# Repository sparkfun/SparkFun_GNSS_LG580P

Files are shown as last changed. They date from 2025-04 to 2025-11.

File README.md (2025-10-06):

SparkFun Quadband GNSS RTK with Heading Breakout - LG580P (Qwiic)
========================================

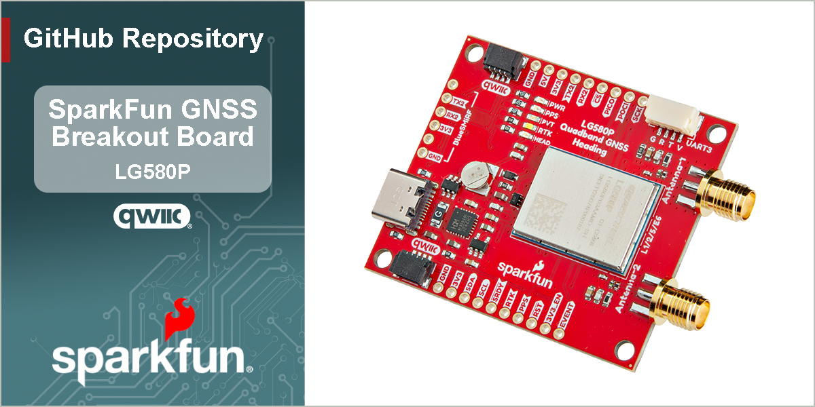
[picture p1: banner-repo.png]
SparkFun Quadband GNSS RTK with Heading Breakout - LG580P (Qwiic)


[*SparkFun Quadband GNSS RTK with Heading Breakout - LG580P (Qwiic) (GPS-28019)*](https://www.sparkfun.com/sparkfun-quadband-gnss-rtk-with-heading-breakout-lg580p-qwiic.html)

The [SparkFun Quadband GNSS RTK with Heading Breakout - LG580P (Qwiic)](https://www.sparkfun.com/sparkfun-quadband-gnss-rtk-with-heading-breakout-lg580p-qwiic.html) features the Quectel LG580P GNSS module, providing exceptional positioning and heading accuracy. The LG580P GNSS module is an upgraded version of the LG290P on our [SparkFun Quadband GNSS RTK Breakout - LG290P (Qwiic)](https://www.sparkfun.com/sparkfun-quadband-gnss-rtk-breakout-lg290p-qwiic.html); providing an additional GNSS antenna input for instantaneous heading determination down to 0.1&deg;. In traditional navigation systems, such as those used on your phone or car, previous navigation points are utilized to determine the course heading. This is the reason why the arrow indicator will spin or be oriented in the wrong directions when the navigation system first boots or has been stationary for extended periods of time. However, with the LG580 GNSS module, users are provided with a dedicated heading without relying on previous course data points, magnetometers/compasses, or gyroscopes in IMUs, which can introduce small errors.

The board's dimensions, pin layout, and connectors are similar to our very popular [SparkFun GPS-RTK-SMA Breakout - ZED-F9P (Qwiic)](https://www.sparkfun.com/sparkfun-gps-rtk-sma-breakout-zed-f9p-qwiic.html), featuring a compact design and convenient Qwiic connectors. *(\*Depending on your application, this board could potentially function as a drop-in replacement; users should verify the pin compatibility of this board with their current installation.)* The board also accommodates users with a diverse choice of interfaces including UART, SPI*, I<sup>2</sup>C*, and CAN*. The board has three UART ports, which are accessible through the USB-C connector, BlueSMiRF *(6-pin PTH)* header, and 4-pin locking JST connector. Users can also interface with the board through the 25 PTH pins that are broken out around the edge of the board. For the GNSS antenna(s), SMA antenna connectors are provided on the edge of the board; an optional, secondary antenna can be utilized for heading determination. We also provide two 4-pin JST Qwiic connectors for future use, when the I<sup>2</sup>C feature becomes available for the GNSS module.

The LG580P module is a quad-band, multi-constellation, high-precision, RTK and heading GNSS receiver. The module is capable of simultaneously receiving signals from the `L1`, `L2`, `L5`, and `L6`/`E6` frequency bands of the GPS, GLONASS, Galileo, BDS, QZSS, and NavIC GNSS constellations. In addition, the module supports SBAS augmentation systems (WAAS, EGNOS, BDSBAS, MSAS, GAGAN, KASS, ASECNA, SouthPAN, and SDCM), PPP services* (BDS PPP-B2b, QZSS CLAS, MADOCA-PPP, and Galileo HAS), RTCM, and RTK corrections for precision navigation with a fast convergence time and reliable performance.

The built-in professional-grade interference signal detection and elimination algorithms, effectively mitigate multiple narrow-band interference sources and significantly improve signal reception performance in complex electromagnetic environments. In addition, the RTK and heading algorithms ensure reliable positioning in challenging scenarios such as urban environments and deep tree cover. With its high-precision, low power consumption and a high positioning and heading update rate of up to 20 Hz, this board is ideal for high-precision navigation applications, such as intelligent robots, precision agriculture, ADAS, and autonomous driving.

> [!NOTE]
> `*`: Feature is still under development

> [!IMPORTANT]
> - Currently, only the UART interface is supported by the module. All three UART ports are broken out to the USB-C connector *(via CH342 USB-serial converter)*, 4-pin locking JST connector, and BlueSMiRF 6-pin header.
> - Additionally, the corrections for some of the PPP services may not be implemented yet.

Documentation
--------------

- **[Hookup Guide (mkdocs)](http://docs.sparkfun.com/SparkFun_GNSS_LG580P/)** - A hookup guide for the SparkFun Quadband GNSS RTK Breakout - LG580P breakout board hosted by GitHub pages<br>
   
- [SparkFun LG290P GNSS Arduino Library](https://github.com/sparkfun/SparkFun_LG290P_GNSS_Arduino_Library) - An Arduino library for the LG290P and LGx80P GNSS modules

Repository Contents
-------------------

- **[/docs](/docs/)** - Online documentation files
  - [/assets](/docs/assets/) - Assets files
    - [/3d_model](/docs/assets/3d_model/) - 3D models for the board
    - [/board_files](/docs/assets/board_files/) - Design files for the board
      - [KiCad Design Files](/docs/assets/board_files/kicad_files.zip) (.zip)
      - [Schematic](/docs/assets/board_files/schematic.pdf) (.pdf)
      - [Dimensions](/docs/assets/board_files/dimensions.pdf) (.pdf)
    - [/component_documentation](/docs/assets/component_documentation/) - Datasheets for hardware components
    - [/img/hookup_guide](/docs/assets/img/hookup_guide/) - Images for hookup guide documentation - Hookup guide images for the board
    - /Hardware - Hardware design files (.brd, .sch)
      - /Production - Production files

Product Variants
----------------

- [GPS-28019](https://www.sparkfun.com/sparkfun-quadband-gnss-rtk-with-heading-breakout-lg580p-qwiic.html) - v1.0, Initial Release
- LG290P Variants
  - [GPS-26620](https://www.sparkfun.com/sparkfun-quadband-gnss-rtk-breakout-lg290p-qwiic.html) - SparkFun LG290P Breakout
  - [GPS-26916](https://www.sparkfun.com/sparkfun-rtk-postcard.html) - SparkFun RTK Postcard *(LG290P + ESP32)*

Version History
---------------

- [v10](https://github.com/sparkfun/SparkFun_GNSS_LG580P/releases/tag/v10) - Initial Release

License Information
-------------------

This product is ***open source***!

Please review the [`LICENSE.md`](./LICENSE.md) file for license information.

If you have any questions or concerns about licensing, please contact technical support on our [SparkFun forums](https://forum.sparkfun.com/viewforum.php?f=152).

Distributed as-is; no warranty is given.

- Your friends at SparkFun.

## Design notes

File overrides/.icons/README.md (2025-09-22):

.icons directory
====================
This folder should contain branding logos for the product documentation

## General Images
- `sfe.svg` - SparkFun flame logo
- `kicad-primary.svg` - Full KiCad logo

## Directory
- `logo` - Other available logos

## SVG Optimizer
- [Remove meta data from svg](https://jakearchibald.github.io/svgomg/)

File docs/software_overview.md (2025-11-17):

!!! tip
	While it is not required, we highly recommend that users configure their LG580P GNSS module with the [QGNSS software provided by Quectel](#qgnss-software).

	???+ warning "Windows Only"
		Currently, the QGNSS software is only available for Windows operating systems.

???+ success "Windows, MacOS, or Linux"
	For users with computers that run on MacOS or Linux, we have found alternative software option for viewing the data from the NMEA messages.

	- :material-github: [GitHub Repository](https://github.com/semuconsulting/PyGPSClient)
	- [Installation Instructions](https://github.com/semuconsulting/PyGPSClient?tab=readme-ov-file#installation)
	- [PyPI Project](https://pypi.org/project/pygpsclient/)

## CH342 USB Driver
The USB drivers for the CH342 USB-to-Serial converter can be downloaded from the [manufacturer's website](https://www.wch-ic.com/search?q=CH342&t=downloads).

<div class="grid cards" align="center" markdown>

-   :material-microsoft-windows: **Windows**

	---

	[:octicons-download-16:{ .heart } Download Page for `CH343SER.EXE`](https://www.wch-ic.com/downloads/CH343SER_EXE.html){ .md-button .md-button--primary target="blank" }

-   :material-apple: **MacOS**

	---

	[:octicons-download-16:{ .heart } Download Page for `CH341SER_MAC.ZIP`](https://www.wch-ic.com/downloads/CH34XSER_MAC_ZIP.html){ .md-button .md-button--primary target="blank" }

</div>

!!! info "Linux"
	A USB driver is not required for Linux based operating systems.

## QGNSS Software
!!! warning "Windows Only"
	Currently, the QGNSS software is only available for Windows operating systems.

QGNSS is highly intuitive GNSS evaluation software that is easy to use, personalized, and compatible with leading Quectel technologies. The software allows users to define or apply GNSS product configurations for specific use cases. Saving, restoring, or sharing configurations between different products and users is easy. The software supports product evaluation with a choice of views to observe static and dynamic behavior of the connected a Quectel GNSS receiver.

<article style="text-align: center;" markdown>
[:octicons-download-16:{ .heart } Download the QGNSS Software *(v2.x)* from Quectel](https://www.quectel.com/download/qgnss_v2-0_en/){ .md-button .md-button--primary target="blank" }
</article>

!!! info "System Requirements"
	**Operating System:** Windows

### Connecting to the LG580P
In order to connect to the LG580P properly, users will need to specify the settings of the UART port.

<figure markdown>
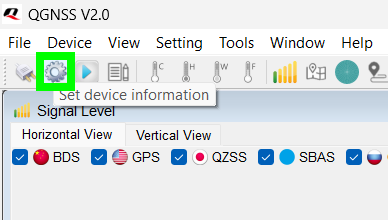
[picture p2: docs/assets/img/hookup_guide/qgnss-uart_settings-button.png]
Configure UART Settings

<figcaption markdown>Click the <kbd>:material-cog:</kbd> button to configure the UART settings.</figcaption>
</figure>

Before users can connect to the Quad-band GNSS RTK breakout board, they will need to specify the connection settings in QGNSS. Once configured, users can select the ++"OK"++ button and QGNSS will automatically attempt to connect to the GNSS module.

- Select the `LG580P(03)` from the drop-down menu to configure the `Model` of the GNSS module being connected.
- Below, is a list of the default settings for `UART` ports of the LG580P. These settings should be selected in the `Device Information` menu, unless configured differently.
- For the `Port`, select the enumeration of the CH342 labeled with channel `A` from the drop-down menu.

<div class="grid" markdown>

<figure markdown>
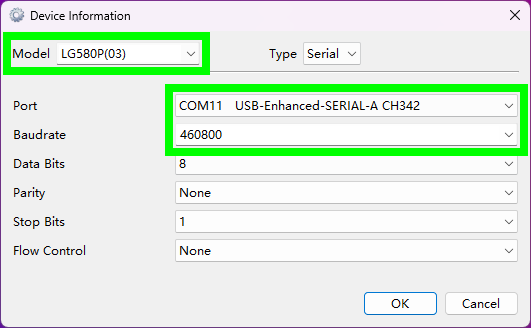
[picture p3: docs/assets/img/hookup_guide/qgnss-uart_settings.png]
UART Settings in QGNSS

<figcaption markdown>Specify the settings for the UART port in QGNSS.</figcaption>
</figure>

<figure markdown>
COM Ports
<figcaption markdown>Select the `COM` port of the CH342 labeled with `A`.</figcaption>
</figure>

</div>

### Configure the LG580P
By default, the UART ports are configured to transmit and receive `NMEA 0183` and/or `RTCM 3.x` messages. These messages are generally used for transmitting PNT data; and providing or receiving RTK corrections, respectively. Quectel also implements a system of proprietary messages (`PQTM`) for users to configure the LG580P, following the data format of the `NMEA` protocol.

???+ terminal "Data Format - PQTM Messages"
	The expected structure of the data in the proprietary PQTM messages is shown below:

	<figure markdown>
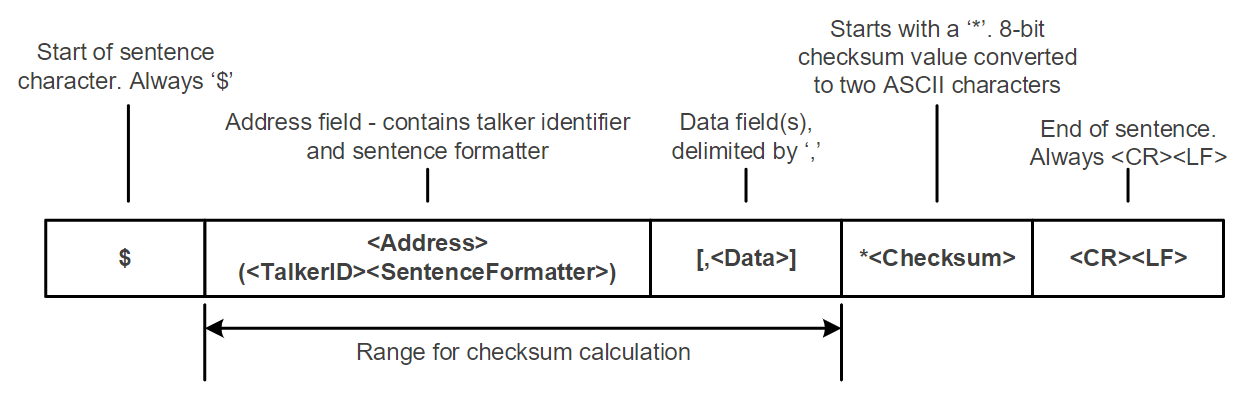
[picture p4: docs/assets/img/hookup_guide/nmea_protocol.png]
NMEA data structure
	
	<figcaption markdown>The data structure of Quectel messages for the `NMEA` protocol.</figcaption>
	</figure>

	`<Checksum>`:

	- Checksum field follows the checksum delimiter character `*`.
	- Checksum is the 8-bit exclusive OR of all characters in the sentence, including `,` the field delimiter, between but not including the `$` and the `*` delimiters.

	`<CR>` & `<LF>`: Carriage return; followed by a new line

	- Depending on the terminal emulator, these may be options configured in the program settings.
	- Otherwise, users may need to add the `\r` and `\n` characters at the end of the message.

In the QGNSS software, users can click on the ++"Advance"++ button, at the bottom of the `QConsole` window, to configure the settings for the messages sent to the LG580P. Selecting `NMEA` and `CRLF` from the drop-down menu of the **Checksum Type** and **Suffix** options, will automatically calculate and append the `<checksum>` value, carriage return, and line follow to the end of the message entered in the **Data Input** field.

<figure markdown>
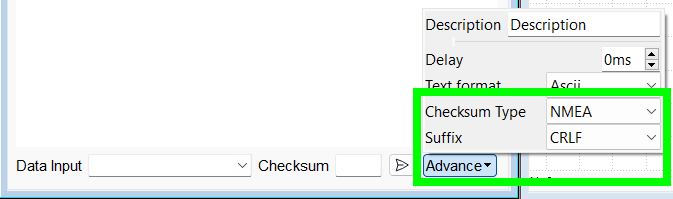
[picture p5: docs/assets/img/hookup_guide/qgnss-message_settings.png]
NMEA message setting

<figcaption markdown>The settings for the messages transmitted from the QConsole.</figcaption>
</figure>

???+ tip "Display the QConsole Toolbar"
	There is a toolbar for the QConsole, which has a bunch of tools that users may find useful. This includes, a search function, scroll-lock button, pause/clear the message feed, etc. To open/close the toolbar inside the QConsole, ++"right-click"++ on the mouse and select the `Show Tool` option from the drop-down menu or utilize the keyboard shortcut: ++ctrl++ + ++q++.

	<figure markdown>
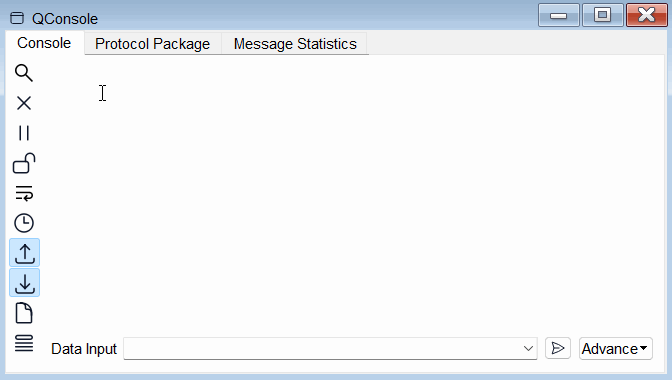
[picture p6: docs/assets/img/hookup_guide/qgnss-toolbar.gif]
QConsole Toolbar
	
	<figcaption markdown>++"Right-click"++ on the mouse and select the `Show Tool` option, inside the QConsole.</figcaption>
	</figure>

??? example "Example - `PQTMCFGUART` Message"
	As an example, try utilizing the `PQTMCFGUART` PQTM message. Enter `$PQTMCFGUART,R*` into the **Data Input** field of the QConsole. DOn't forget to select the `NMEA` and `CRLF` options from ++"Advance"++ settings menu. If entered and configured properly, the value `36` should pop up in the **Checksum** field of the QConsole; then, click on the <kbd>:material-send:</kbd> button to send the message.

	``` bash
	$PQTMCFGUART,R*
	```

	Once the message has been sent, keep a close watch of the messages in the console. It may help to click on the <kbd>:octicons-unlock-16:</kbd> button to disable auto-scrolling, when trying to locate the message response. Additionally, the response may not appear right away, it could be appended to the end of the next data packet, as shown in the image below.

	<figure markdown>
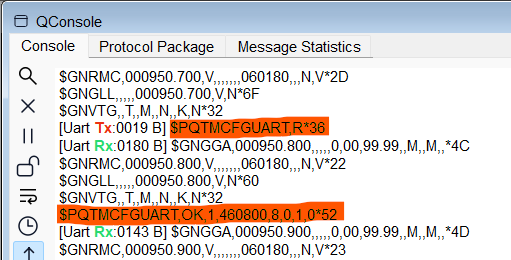
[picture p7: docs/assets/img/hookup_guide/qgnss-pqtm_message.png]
PQTM demo
	
	<figcaption markdown>Example of utilizing the Quectel PQTM messages in the QConsole.</figcaption>
	</figure>

### Firmware Update
In the event that users need to update the firmware on the LG580P module, please refer to the instructions in Quectel's [reference manual](./assets/component_documentation/quectel_lg290p03lgx80p03_firmware_upgrade_guide_v1-1.pdf). The [GitHub repo Firmware folder](https://github.com/sparkfun/SparkFun_GNSS_LG580P/tree/main/Firmware) contains firmware provided by Quectel. For the very latest firmware, users should reach out to Quectel through their [forum page](https://forums.quectel.com/).

<article style="text-align: center;" markdown>

[Firmware Upgrade Manual](./assets/component_documentation/quectel_lg290p03lgx80p03_firmware_upgrade_guide_v1-1.pdf){ .md-button .md-button--primary target="blank" }

</article>

!!! example "Example - Step-by-Step Instructions"

	1. [Connect to the LG580P](#connecting-to-the-lg580p)
	1. From the **Tools** drop down menu, select **Firmware Update**

		**Tools** > **Firmware Update**

	1. Click the :material-file-send: button to select the receiver firmware
	1. Click to choose the firmware upgrade package whose name is identifiable by the presence of `*.pkg` file extension
	1. Click the :material-play: button to start the firmware upgrade process
	1. Reset the GNSS module using a jumper wire: momentarily short the RST (RESET) breakout pad to GND to reset the module
		1. The upgrade process waits at the synchronization step. The user has 20 seconds to manually reset the GNSS module; otherwise, the firmware upgrade process will fail
		1. After momentarily shorting RST to GND, the upgrade process will continue
		1. Wait for the process to complete
	1. After the firmware upgrade is complete, the module will automatically reboot

!!! warning "Synchronization Step"
	In the [reference manual](./assets/component_documentation/quectel_lg290p03lgx80p03_firmware_upgrade_guide_v1-1.pdf), **Step 9** instructs users to wait for a synchronization process. If users refer to an earlier section of the manual, this process requires the LG580P module to receive a `SYNC_WORD1` within 500ms of powering up. Therefore, users must restart the module during the synchronization step. In the QGNSS software *(+v2.1)*, a software reset can be performed with the :material-refresh: reboot button. **However, for the firmware upgrade, the LG580P seems to need an actual hardware reset. Use a jumper wire to momentarily short the RST pad to GND to reset the LG580P.**

	<figure markdown>
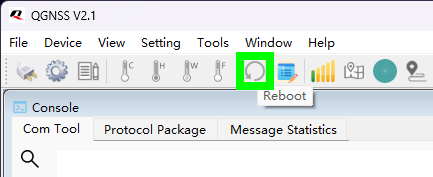
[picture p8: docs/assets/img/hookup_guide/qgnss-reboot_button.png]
Reboot button
	
	<figcaption markdown>Reboot button in the QGNSS software *(v2.1)*.</figcaption>
	</figure>

## PyGPSClient
As an alternative to QGNSS, we recommend [PyGPSClient](https://github.com/semuconsulting/PyGPSClient) for users with computers that run on MacOS or Linux.

??? info "Resources"
	For additional information, users can refer to the following resources for the PyGPSClient software:

	- :material-github: [GitHub Repository](https://github.com/semuconsulting/PyGPSClient)
	- [Installation Instructions](https://github.com/semuconsulting/PyGPSClient?tab=readme-ov-file#installation)
	- [LG580P Configuration](https://github.com/semuconsulting/PyGPSClient?tab=readme-ov-file#nmeaconfig)
	- [PyPI Project](https://pypi.org/project/pygpsclient/)

### Installation
There are a variety of [installation methods](https://github.com/semuconsulting/PyGPSClient?tab=readme-ov-file#installation) detailed in the GitHub repository's `README.md` file. However, we recommend utilizing the `pip` installation method.

!!! terminal "Installation Commands"
	Depending on how Python is installed on the computer, one of the following commands should allow users to install the software.

	- 
		``` bash
		python3 -m pip install pygpsclient
		```
	- 
		``` bash
		pip install pygpsclient
		```

	??? info "System Requirements"
		This installation method requires an internet connection. Additionally, users will also need administrative privileges *(or root access `sudo`)* for the installation.

### Connecting to the LG580P
Before users can connect to the Quad-band GNSS RTK breakout board, they will need to specify the settings of the UART port in PyGPSClient. Once configured, users can select the <kbd>:material-usb:</kbd> button and PyGPSClient will automatically attempt to connect to the GNSS module.

- For the `Serial Port`, select the port with the lowest enumeration of the CH342 or the port labeled with channel `A` from the drop-down menu.

<figure markdown>
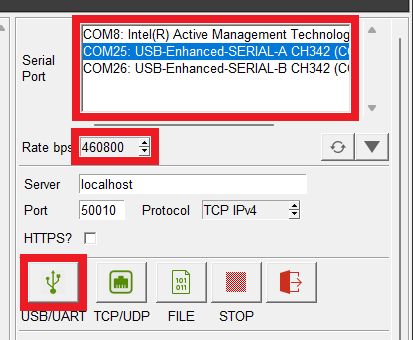
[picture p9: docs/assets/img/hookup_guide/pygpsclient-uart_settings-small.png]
UART Settings in PyGPSClient

<figcaption markdown>Specify the settings for the UART port in QGNSS.</figcaption>
</figure>

### Terminal Emulator
Another viable option for connecting to the Quad-band GNSS RTK breakout board, is to utilize a [terminal emulation program](https://learn.sparkfun.com/tutorials/112). While reading the data sent from the LG580P is relatively trivial, users will need to be more selective when choosing an emulator to configure the LG580P module on the Quad-band GNSS RTK breakout board. This is due to the unique data structure of the proprietary messages that Quectel implements to configure the LG580P *(see the [**Configure the LG580P**](#configure-the-lg580p) section, above)*.

## Arduino IDE
!!! tip
	For first-time users, who have never programmed before and are looking to use the Arduino IDE, we recommend beginning with the <a href="https://www.sparkfun.com/sparkfun-inventor-s-kit-for-arduino-uno-v4-1.html">SparkFun Inventor's Kit (SIK)</a>, which is designed to help users get started programming with the Arduino IDE.

Most users may already be familiar with the Arduino IDE and its use. However, for those of you who have never heard the name *Arduino* before, feel free to check out the [Arduino website](https://www.arduino.cc/en/Guide/HomePage). To get started with using the Arduino IDE, check out our tutorials below:

<div class="grid cards" markdown align="center">

-   <a href="https://learn.sparkfun.com/tutorials/50"><figure markdown>
	What is an Arduino?
	</figure>

	---

	**What is an Arduino?**</a>

-   <a href="https://learn.sparkfun.com/tutorials/61"><figure markdown>
	Installing the Arduino IDE
	</figure>

	---
	
	**Installing the Arduino IDE**</a>

-   <a href="https://learn.sparkfun.com/tutorials/15"><figure markdown>
	Installing an Arduino Library
	</figure>

	---
	
	**Installing an Arduino Library**</a>

-   <a href="https://learn.sparkfun.com/tutorials/1265"><figure markdown>
	Installing Board Definitions in the Arduino IDE
	</figure>

	---
	
	**Installing Board Definitions in the Arduino IDE**</a>
</div>

### SparkFun LG290P GNSS Arduino Library
The [SparkFun LG290P Quadband RTK GNSS Arduino Library](https://github.com/sparkfun/SparkFun_LG290P_GNSS_Arduino_Library) can be installed from the library manager in the Arduino IDE by searching for:

	SparkFun LG290P Quadband RTK GNSS Arduino Library

<div class="grid" markdown>

<div markdown>

<figure markdown>
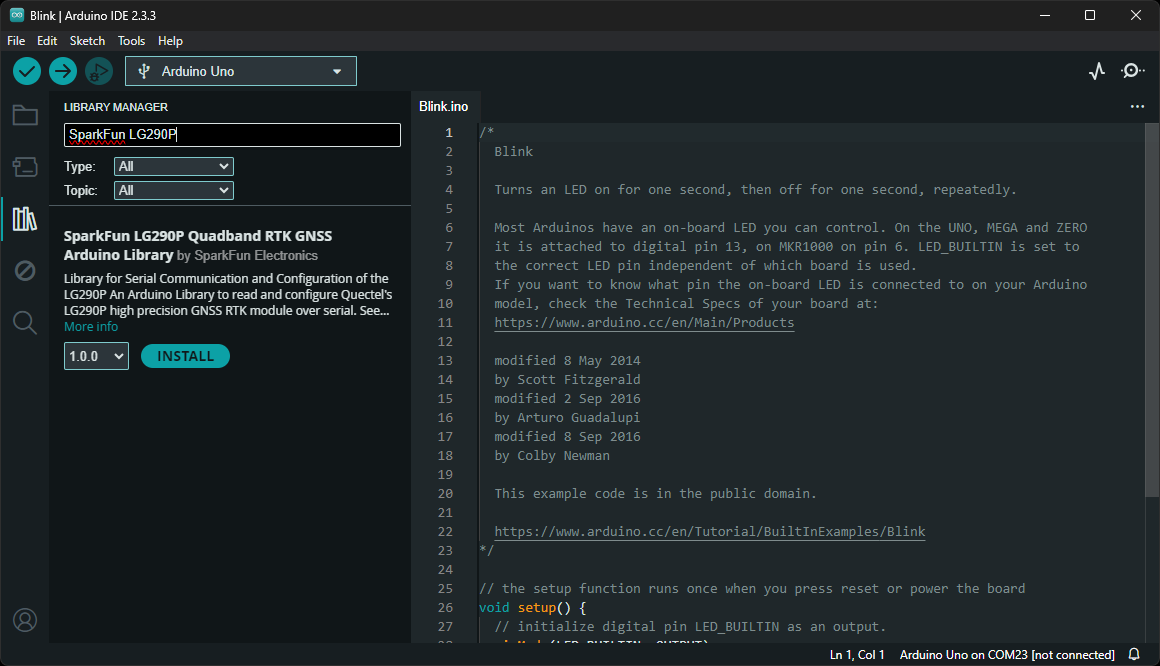
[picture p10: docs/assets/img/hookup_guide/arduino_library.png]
Library listed in the library manager of the Arduino IDE Click to enlarge

<figcaption markdown>The SparkFun LG290P Quadband RTK GNSS Arduino Library in the library manager of the Arduino IDE.</figcaption>
</figure>

</div>

<div markdown>

!!! tip "Manually Download the Arduino Library"
	For users who would like to manually download and install the library, the `*.zip` file can be accessed from the [GitHub repository](https://github.com/sparkfun/SparkFun_LG290P_GNSS_Arduino_Library) or downloaded by clicking the button below.

	<article style="text-align: center;" markdown>
	[:octicons-download-16:{ .heart } Download the Arduino Library](https://github.com/sparkfun/SparkFun_LG290P_GNSS_Arduino_Library/archive/refs/heads/main.zip){ .md-button .md-button--primary }
	</article>

</div>

</div>

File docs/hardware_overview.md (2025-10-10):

## :material-folder-cog: Design Files
The SparkFun LG580P Quad-band GNSS RTK breakout board's dimensions, pin layout, and connectors are similar to our very popular [SparkFun GPS-RTK-SMA Breakout - ZED-F9P (Qwiic)](https://www.sparkfun.com/sparkfun-gps-rtk-sma-breakout-zed-f9p-qwiic.html) and [SparkFun Quadband GNSS RTK Breakout - LG290P (Qwiic)](https://www.sparkfun.com/sparkfun-quadband-gnss-rtk-breakout-lg290p-qwiic.html) boards, featuring a compact design and convenient Qwiic connectors.

!!! warning "Drop-in Replacement"
	Depending on your appication, this board could potentially function as a drop-in replacement. However, we advise users to verify the pin compatibility of this board with their current installation.

<!-- Import the component -->
<script type="module" src="https://ajax.googleapis.com/ajax/libs/model-viewer/3.5.0/model-viewer.min.js"></script>

<div class="grid cards desc" markdown>

-   :kicad-primary:{ .enlarge-logo } Design Files

	---

	- :fontawesome-solid-file-pdf: [Schematic](./assets/board_files/schematic.pdf)
	- :material-folder-zip: [KiCad Files](./assets/board_files/kicad_files.zip)
	- :material-rotate-3d: [STEP File](./assets/3d_model/cad_model.step)
	- :fontawesome-solid-file-pdf: [Board Dimensions](./assets/board_files/dimensions.pdf):
		- 1.70" x 1.80" (43.2mm x 45.7mm)
		- Four mounting holes:
			- 4-40 screw compatible

-   <!-- Boxes in tabs -->

	=== "3D Model"
		<article style="text-align: center;" markdown>
		<model-viewer src="../assets/3d_model/web_model.glb" camera-controls poster="../assets/3d_model/poster.png" tone-mapping="neutral" shadow-intensity="2" shadow-softness="0.2" camera-orbit="0deg 75deg 0.103m" field-of-view="25.11deg" style="width: 100%; height: 450px;">
		</model-viewer>

		[Download the `*.step` File](./assets/3d_model/cad_model.step "Click download"){ .md-button .md-button--primary width="250px" }

		</article>

		???+ tip "Manipulate 3D Model"
			<article style="text-align: center;" markdown>

			| Controls       | Mouse                    | Touchscreen    |
			| :------------- | :----------------------: | :------------: |
			| Zoom           | Scroll Wheel             | 2-Finger Pinch |
			| Rotate         | ++"Left-Click"++ & Drag  | 1-Finger Drag  |
			| Move/Translate | ++"Right-Click"++ & Drag | 2-Finger Drag  |

			</article>

	=== "Dimensions"
		<article style="text-align: center;" markdown>
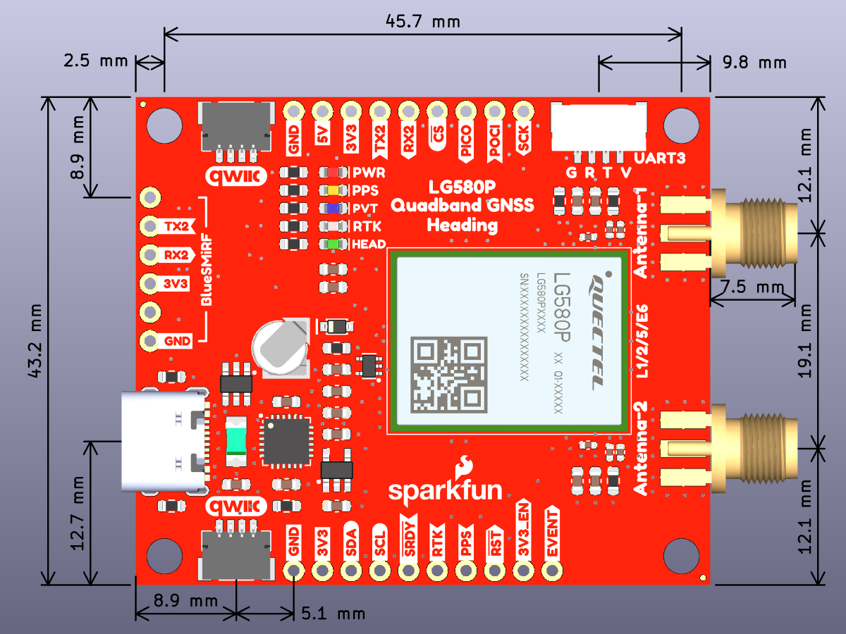
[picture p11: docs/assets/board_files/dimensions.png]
Board Dimensions
		
		<figcaption markdown>Dimensions of the LG580P GNSS breakout board.</figcaption>
		</article>

		???+ tip "Need more measurements?"
			For more information about the board's dimensions, users can download the [KiCad files](./assets/board_files/kicad_files.zip) for this board. These files can be opened in KiCad and additional measurements can be made with the measuring tool.

			!!! info ":octicons-download-16:{ .heart } KiCad - Free Download!"
				KiCad is free, open-source [CAD]("computer-aided design") program for electronics. Click on the button below to download their software. *(\*Users can find out more information about KiCad from their [website](https://www.kicad.org/).)*

				<article style="text-align: center;" markdown>
				[Download :kicad-primary:{ .enlarge-logo }](https://www.kicad.org/download/ "Go to downloads page"){ .md-button .md-button--primary width="250px" }
				</article>

			???+ info ":straight_ruler: Measuring Tool"
				This video demonstrates how to utilize the dimensions tool in KiCad, to include additional measurements:

				<article class="video-500px" style="text-align: center; margin: auto;" markdown>
				<iframe src="https://www.youtube.com/embed/-eXuD8pkCYw" title="KiCad Dimension Tool" frameborder="0" allow="accelerometer; autoplay; clipboard-write; encrypted-media; gyroscope; picture-in-picture" allowfullscreen></iframe>
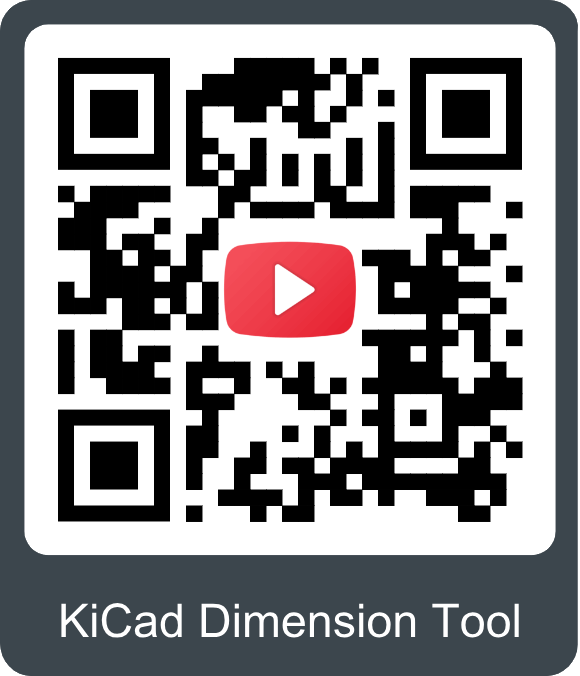
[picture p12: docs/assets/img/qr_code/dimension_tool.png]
QR code to play video
				
				</article>

</div>

## Board Layout
The SparkFun LG580P Quad-band GNSS RTK breakout board features the following:

<div class="grid" markdown>

<div markdown>

<figure markdown>
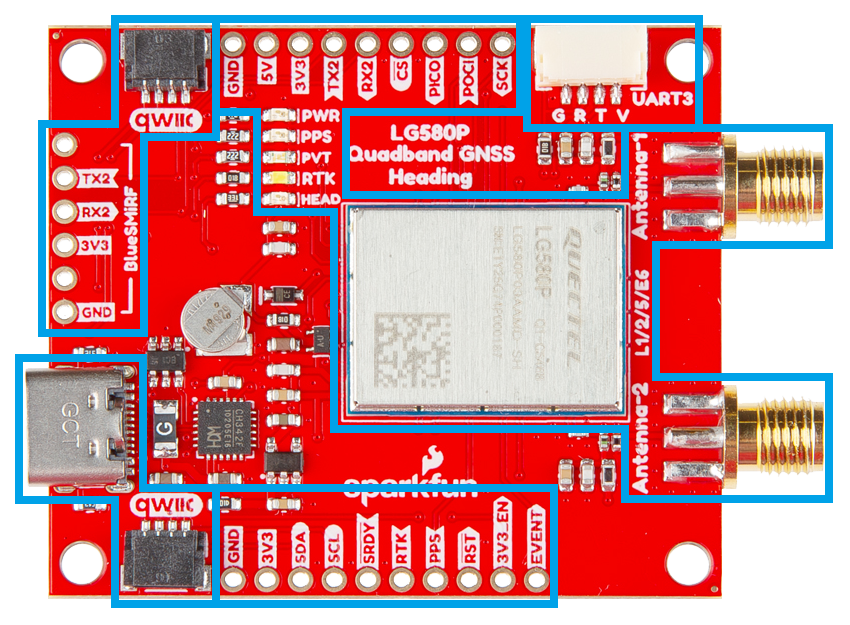
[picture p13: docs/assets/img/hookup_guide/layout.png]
Layout

<figcaption markdown>Layout of the major components on the breakout board.</figcaption>
</figure>

</div>

<div markdown>

1. **USB-C Connector**
:   The primary inteface for powering and interacting with the board
1. **LG580P GNSS Module**
:   The Quectel LG580P GNSS module
1. **Header Pins**
:   Exposes pins to power the board and breaks out the interfaces of the LG580P GNSS module
1. **BlueSMiRF Header Pins**
:   Exposes the `UART2` port of the LG580P GNSS module
1. **JST Connector**
:   Exposes the `UART3` port of the LG580P GNSS module
1. **Qwiic Connectors**
:   Exposes the I^2^C interface of the LG580P GNSS module
1. **Status LEDs**
:   LED status indicators for the LG580P GNSS module
1. **`Antenna L1/2/5/6` RF Connectors**
:   SMA connectors for an external GNSS antennas
1. **Backup Battery**
:   Backup power to maintain ephemeris data on the LG580P GNSS module for warm starts

</div>

</div>

## USB-C Connector
The USB connector is provided to power and communicate with the LG580P GNSS receiver. For most users, it will be the primary method for interfacing with the LG580P.

<figure markdown>
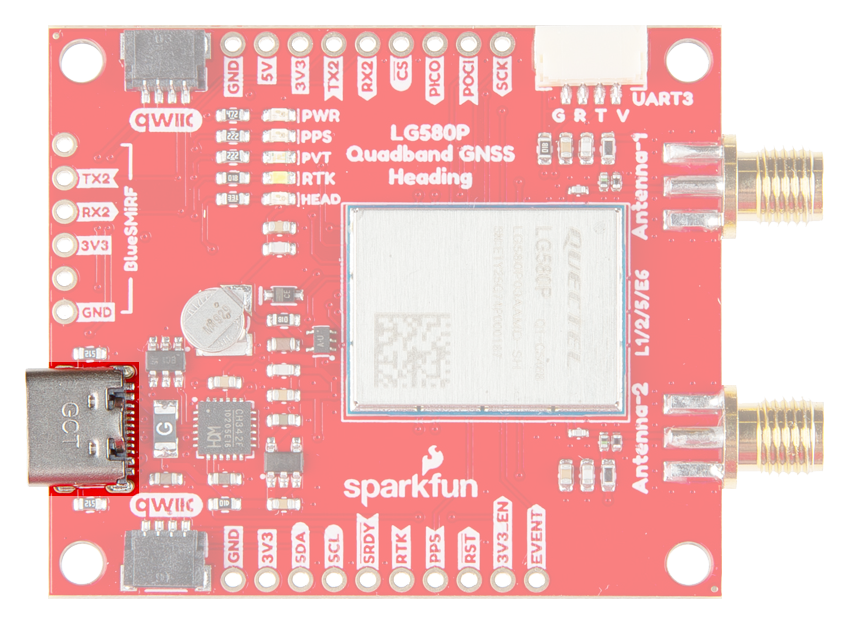
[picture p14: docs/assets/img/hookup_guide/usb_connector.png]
USB-C Connector

<figcaption markdown>USB-C connector on the Quad-band GNSS RTK breakout board.</figcaption>
</figure>

### CH342 Converter
The CH342 serial-to-USB converter allows users to interface with the `UART1` port of the LG580P GNSS module through the USB-C connector. Although the CH342 provides a dual-channel UART interface, only a single channel is utilized to communicate with the LG580P GNSS module. To utilize the CH342, users may need to install a USB driver, which can be downloaded from the [manufacturer website](https://www.wch-ic.com/search?q=CH342&t=downloads).

Once the USB driver is installed:

- Two virtual `COM` ports will be emulated, which can be used as standard `COM` ports to access the receiver.
- Users should select UART port with the enumeration labeled as `Channel A`.

??? tip "USB Drivers"
	<div class="grid cards" align="center" markdown>

	-   :material-microsoft-windows: **Windows**

		---

		[:octicons-download-16:{ .heart } Download Page for <code>CH343SER.EXE</code>](https://www.wch-ic.com/downloads/CH343SER_EXE.html){ .md-button .md-button--primary target="blank" }

	-   :material-apple: **MacOS**

		---

		[:octicons-download-16:{ .heart } Download Page for `CH341SER_MAC.ZIP`](https://www.wch-ic.com/downloads/CH34XSER_MAC_ZIP.html){ .md-button .md-button--primary target="blank" }

	</div>

	!!! info "Linux"
		A USB driver is not required for Linux based operating systems.

## Power
The Quad-band GNSS RTK breakout board only requires **3.3V** to power the board's primary components. The simplest method to power the board is through the USB-C connector. Alternatively, the board can also be powered through the other connectors and [PTH](https://en.wikipedia.org/wiki/Through-hole_technology "Plated Through Holes") pins.

<figure markdown>
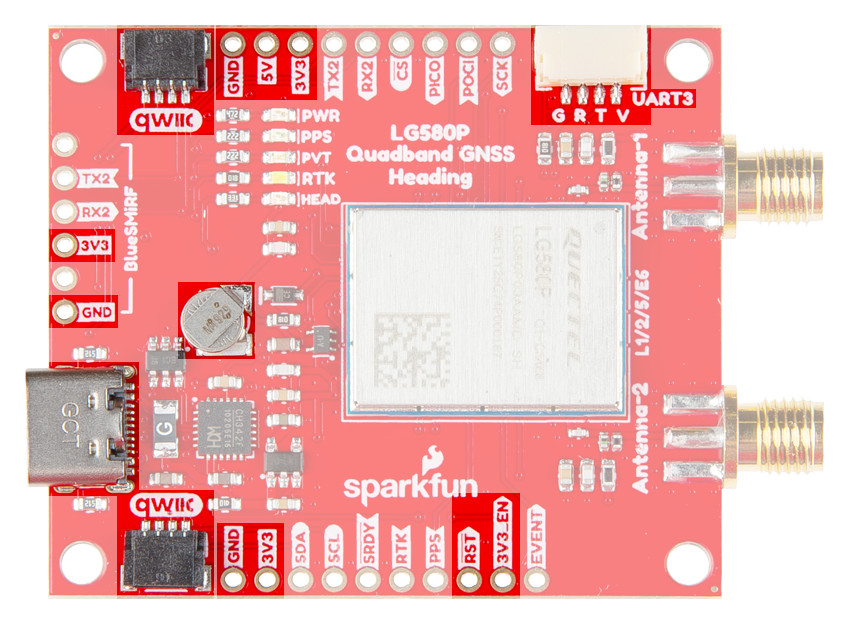
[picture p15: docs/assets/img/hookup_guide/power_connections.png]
Power connections

<figcaption markdown>Quad-band GNSS RTK breakout board's power connections.</figcaption>
</figure>

Below, is a general summary of the power circuitry for the board:

<div class="annotate" markdown>

- **`5V`** - The voltage from the USB-C connector, usually **5V**.
	- Can be utilized as the primary power source for the entire board.
- **`3V3`** - 3.3V power rail, which powers the LG580P GNSS module, backup battery, and the power LED.
	- Power can also be distributed to/from any of the `3V3` PTH pins or JST connectors *(Qwiic or `UART3`)*.
		- For power that is supplied through these connections, the LG580P requires a supply voltage of **3.0–3.6V**.
	- A regulated **3.3V** is supplied by the [RT9080](./assets/component_documentation/DS9080.pdf), when powered from the `5V` PTH pin or USB connector
		- Input Voltage Range: **1.2 to 5.5V** (1)
		- The RT9080 LDO regulator can source up to 600mA.
- **`3V3_EN`** - Controls the power output from the RT9080 voltage regulator.
	- By default, the pin is pulled-up to 5V and to enable the RT9080 output voltage.
- **`RST`** - Used to reset the LG580P GNSS module
	- Connected to the [`RESET_N` pin](#pio-pins) of the LG580P module, a system pin with an internal pull-up resistor.
	- Driving the pin `LOW` for at least 100ms and releasing it, triggers a hard reset.
- **`GND`** - The common ground or the 0V reference for the voltage supplies.
- [**Backup Battery**](#backup-battery) - Provides backup power to the GNSS module to maintain ephemeris data

</div>

1. While the [RT9080](./assets/component_documentation/DS9080.pdf) LDO regulator has an input voltage range of 1.2 - 5.5V, a minimum supply voltage of **3.5V** is recommended for a 3.3V output.

!!! tip "JST Connector"
	The `VCC` pin of the [JST connector](#jst-connector) is designed to operate as a voltage output. However, an input voltage can be supplied through the pin, but users should be mindful of any voltage contention issues.

	Additionally, the `VSEL` jumper can be modified to change to output voltage level of the `VCC` pin.

!!! tip "BlueSMiRF Header"
	The `3V3` pin of the [BlueSMiRF header](#bluesmirf-header) is designed to operate as a voltage output. However, an input voltage can be supplied through the pin, but users should be mindful of any voltage contention issues.

	Additionally, the `BT-VCC` jumper can be modified to change to output voltage level of the `3V3` pin.

!!! info
	For more details, users can reference the [schematic](./assets/board_files/schematic.pdf) and the datasheets of the individual components on the board.

<div class="grid" markdown>

<div markdown>

### Power Modes

**Acquisition:**
:   Module searches for satellites and to determine visible satellites, coarse frequency, and the code phase of satellite signals

**Tracking:**
:   Once acquisition is completed, the module tracks satellites and demodulates the navigation data from specific satellites

**Backup Mode:**
:   Reduces power consumption. Only backup domain is active and keeps track of time.

</div>

<div markdown>

### Power Consumption
The power consumption of the LG580P GNSS module depends on the GNSS signals enabled and the positioning mode.

**Current Consumption:**

- Acquisition: 98mA (323.4mW)
- Tracking: 116mA (382.8mW)
- Backup Mode: 18μA (59.4μW)

</div>

<div markdown>

### Backup Battery

While charged, the backup battery allows the GNSS module to maintain valid ephemeris data (time and GNSS orbital trajectories) that was stored. Otherwise, the GNSS module must restart [acquiring and tracking satellites](#power-modes).

**Time to First Fix:**

- Cold Start: 28s
- Warm Start: 28s
- Hot Start: 1.8s

</div>

</div>

## :fontawesome-solid-microchip:&nbsp; LG580P GNSS
The centerpiece of the Quad-band GNSS RTK breakout board, is the [LG580P GNSS module](./assets/component_documentation/quectel_lg580p03_hardware_design_v1-0.pdf) from [Quectel](https://www.quectel.com/). The LG580P is a low-power, multi-band, multi-constellation GNSS receiver capable of delivering centimeter-level precision at high update rates. The built-in professional-grade interference signal detection and elimination algorithms, effectively mitigate multiple narrow-band interference sources and significantly improve signal reception performance in complex electromagnetic environments. In addition, the RTK and heading algorithms ensure reliable positioning in challenging scenarios such as urban environments and deep tree cover. With its performance advantages of high-precision and power consumption, this board is an ideal choice for high-precision navigation applications, such as intelligent robots, UAVs, precision agriculture, mining, surveying, and autonomous navigation.

<div class="grid" markdown>

<div markdown>

<figure markdown>
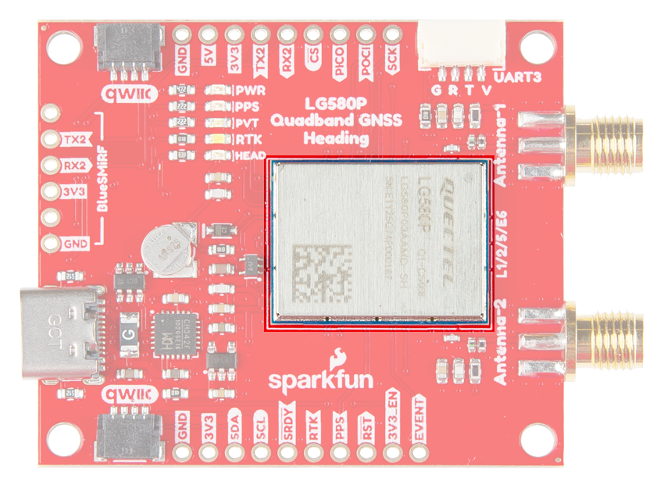
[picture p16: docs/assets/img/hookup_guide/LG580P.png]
LG580P GNSS module

<figcaption markdown>The LG580P module on the Quad-band GNSS RTK breakout board.</figcaption>
</figure>

</div>

<div markdown>

<article class="video-500px" style="text-align: center; margin: auto;" markdown>
<iframe src="https://player.vimeo.com/video/1115089915?h=127c90c2a9" title="Quectel: Product Intro for LG580P GNSS Module" frameborder="0" allow="accelerometer; autoplay; clipboard-write; encrypted-media; gyroscope; picture-in-picture" allowfullscreen></iframe>
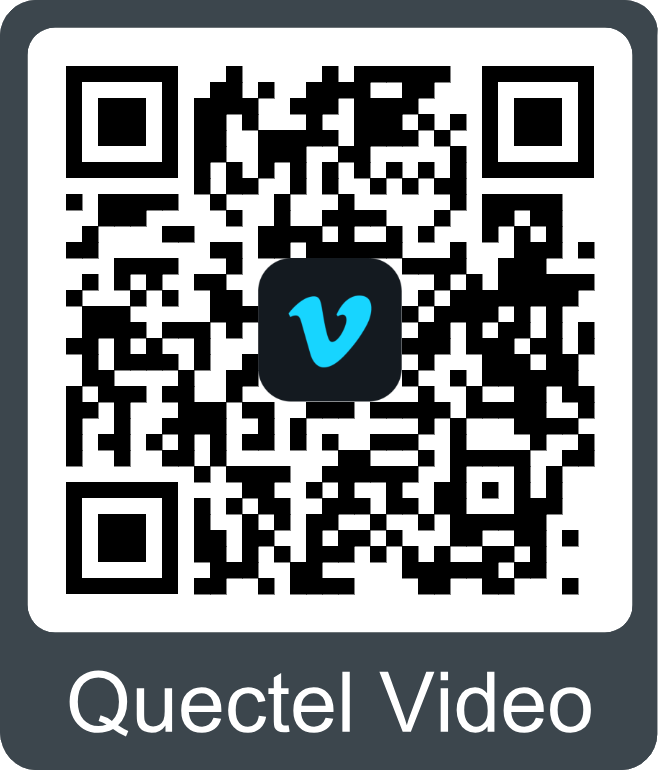
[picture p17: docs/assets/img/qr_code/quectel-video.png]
QR code to product video

</article>

</div>

</div>

??? info "General Features"
	<div class="grid" markdown>

	<div markdown>

	- Supply Voltage: **3.0–3.6V**
	- Tracking Channels: 1040
	- Concurrent signal reception: 5 + QZSS
		- `L1`, `L2`, `L5`, `E6` frequency bands
	- Sensitivity:
		- Acquisition: -145dBm
		- Tracking: -160dBm
		- Reacquisition: -155dBm
	- Antenna Power: External
	- GNSS Constellations and SBAS Systems:
		- **USA:** GPS + WASS
		- **Russia:** GLONASS + SDCM
		- **EU:** Galileo + EGNOS
		- **China:** BDS + BDSDAS
		- **Japan:** QZSS + MSAS
		- **India:** NavIC + GAGAN
		- **Korea:** KASS
		- **Africa:** ASECNA
		- **Auz/NZ:** SouthPAN
	- Accuracy of 1PPS Signal: 5ns
	- Update Rate:
		- Default: 10Hz
		- Max: 20Hz

	</div>

	<div markdown>

	- Time to First Fix *(without AGNSS)*:
		- Cold Start: 28s
		- Warm Start: 28s
		- Hot Start: 1.8s
	- RTK Convergence Time: 5s
	- Dynamic Performance:
		- Maximum Altitude: 10000m
		- Maximum Velocity: 490m/s
		- Maximum Acceleration: 4g
	- Interfaces
		- UART (x3)
			- Baud Rate: 9600–3000000bps
				- **Default:** 460800bps
			- Protocol: `NMEA 0183`/`RTCM 3.x`/`QGC`
		- SPI[^1] (x1)
		- I^2^C[^1] (x1)
		- CAN[^1] (x1)
	- Operating temperature: -40&deg;C to +85&deg;C
	- Footprint: 21mm × 16mm × 2.7mm
	- Weight: 1.4g

	</div>

	</div>

	[^1]:
		!!! warning "Feature Under Development"
			Currently, only the UART interface is supported by the module. Support for the **I^2^C**, **SPI**, and **CAN** interfaces are still under development.

### Frequency Bands
The LG580P modules are multi-band, multi-constellation GNSS receivers. Below, is a chart illustrating the frequency bands utilized by all the global navigation satellite systems; along with a list of the frequency bands and GNSS systems supported by the LG580P GNSS module.

<figure markdown>
GNSS frequency bands (https://www.tallysman.com/app/uploads/2021/07/Tallysman-GNSS-Frequencies-v8.0_Chart-1-1024x425.png "Click to enlarge")
<figcaption markdown>Frequency bands of the global navigation satellite systems. (Source: [Tallysman](https://www.tallysman.com/gnss-constellations-radio-frequencies-and-signals/))</figcaption>
</figure>

<div class="grid" markdown>

<div markdown>

**Supported Frequency Bands:**

- GPS: `L1 C/A`, `L5`, `L2C`
- GLONASS: `L1`, `L2`
- Galileo: `E1`, `E5a`, `E5b`, `E6`
- BDS: `B1I`, `B1C`, `B2a`, `B2b`, `B2I`, `B3I`
- QZSS: `L1 C/A`, `L5`, `L2C`, `L6`
- NavIC: `L5`
- SBAS: `L1`
- L-band PPP[^2]:
	- PPP: `B2b`
	- QZSS: `L6`
	- Galileo HAS: `E6`

</div>

<div markdown>

**Supported GNSS Constellations:**

- GPS (USA)
- GLONASS (Russia)
- Galileo (EU)
- BDS (China)
- QZSS (Japan)
- NavIC (India)

**Supported SBAS Systems:**

- WASS (USA)
- SDCM (Russia)
- EGNOS (EU)
- BDSBAS (China)
- MSAS (Japan)
- GAGAN (India)
- KASS (Korea)
- ASECNA (Africa)
- SouthPAN (Aus/NZ)

</div>

</div>

[^2]:
	!!! warning "Feature Under Development"
		Corrections for some of the PPP services have not been implemented.

!!! info
	For a comparison of the frequency bands supported by the LG580P GNSS modules, refer to sections **1.2**, **1.5**, and **1.6** of the [hardware design manual](./assets/component_documentation/quectel_lg580p03_hardware_design_v1-0.pdf).

??? tip "What are Frequency Bands?"
	A [frequency band](https://en.wikipedia.org/wiki/Frequency_band) is a section of the [electromagnetic spectrum](https://en.wikipedia.org/wiki/Electromagnetic_spectrum), usually denoted by the range of its upper and lower limits. In the [radio spectrum](https://en.wikipedia.org/wiki/Radio_spectrum), these frequency bands are usually regulated by region, often through a government entity. This regulation prevents the interference of RF communication; and often includes major penalties for any interference with critical infrastructure systems and emergency services.

	<figure markdown>
	GNSS frequency bands (https://gssc.esa.int/navipedia/images/c/cf/GNSS_All_Signals.png "Click to enlarge")
	<figcaption markdown>Frequency bands of the global navigation satellite systems. (Source: [ESA](https://gssc.esa.int/navipedia/index.php?title=File:GNSS_All_Signals.png "European Space Agency"))</figcaption>
	</figure>

	However, if the various GNSS constellations share similar frequency bands, then how do they avoid interfering with one another? Without going too far into detail, the image above helps illustrate some of the characteristics, specific to the frequency bands of each system. With these characteristics in mind, along with other factors, the chart can help users to visualize how multiple GNSS constellations might co-exist with each other.

	For more information, users may find these articles of interest:

	- [GNSS signal](https://gssc.esa.int/navipedia/index.php/GNSS_signal)
	- [GPS Signal Plan](https://gssc.esa.int/navipedia/index.php?title=GPS_Signal_Plan)
	- [GLONASS Signal Plan](https://gssc.esa.int/navipedia/index.php?title=GLONASS_Signal_Plan)
	- [GALILEO Signal Plan](https://gssc.esa.int/navipedia/index.php?title=GALILEO_Signal_Plan)

### GNSS Accuracy
The accuracy of the position reported from the LG580P GNSS module, can be improved based upon the correction method being employed. Currently, [RTK](https://en.wikipedia.org/wiki/Real-time_kinematic_positioning "Real-Time Kinematic") corrections provide the highest level of accuracy; however, users should be aware of certain limitations of the system:

- RTK technique requires real-time correction data from a reference station or network of base stations.
	- RTK corrections usually come from RTCM messages that are signal specific *(i.e. an RTK network may only provide corrections for specific signals; only `E5b` and not `E5a`)*.
- The range of the base stations will vary based upon the method used to transmit the correction data.
- The reliability of RTK corrections are inherently reduced in [multipath environments](https://en.wikipedia.org/wiki/Multipath_propagation).

<article style="text-align: center;" markdown>

| Correction Method | Horizontal | Vertical | Heading  | Velocity |
| :--- | :---: | :---: | :---: | :---: |
| Standalone | 1.0m<br>~3.3' | 1.5m<br>~4.9' | | 3cm/s (0.108kph)<br>~1.2in/s (0.067mph) |
| [RTK](https://en.wikipedia.org/wiki/Real-time_kinematic_positioning "Real-Time Kinematic") | **0.8cm** *(+1ppm)*<br>~0.3" | 1.5cm *(+1ppm)*<br>~0.6" | 0.1&deg; | |

</article>

??? info "RTK Corrections"
	To understand how RTK works, users will need a more fundamental understanding of the signal error sources.

	<div class="grid cards" markdown align="center">

	-   <a href="https://www.sparkfun.com/news/7533">
		<figure markdown>
		Tutorial Thumbnail
		</figure>

		---

		**Real-Time Kinematics Explained**</a>

	-   <a href="https://www.sparkfun.com/news/7138">
		<figure markdown>
		Tutorial Thumbnail
		</figure>

		---

		**What is Correction Data?**</a>

	</div>

## Peripherals and I/O Pins
The LG580P GNSS features several peripheral interfaces and I/O pins. Some of these are broken out as pins on the Quad-band GNSS RTK breakout board; whereas, others are broken out to their specific interface *(i.e. USB connector, JST connector, etc.)*. Additionally, some of their connections are tied to other components on the board.

<div class="grid" markdown>

<div markdown>

<figure markdown>
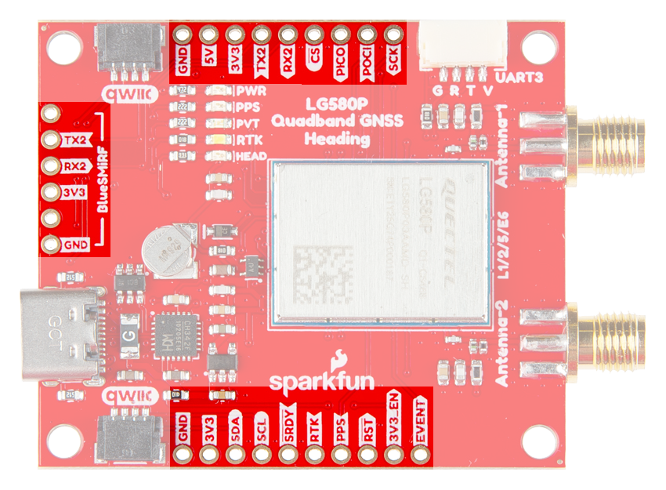
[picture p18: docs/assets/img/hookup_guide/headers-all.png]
Header pins

<figcaption markdown>The I/O pins on the Quad-band GNSS RTK breakout board.</figcaption>
</figure>

</div>

<div markdown>
**Interfaces:**

- UART (x3)
- ~~SPI[^1]~~
- ~~I^2^C[^1]~~
- ~~CAN[^1]~~
- ~~Event Trigger[^3]~~
- PPS Signal
- RTK Signal
- Module Reset

[^3]:
	!!! warning "Feature Under Development"
		The event trigger has not been implemented.

</div>

</div>

=== "UARTs"
	<div class="grid" markdown>

	<div markdown>

	The LG580P GNSS has three UART ports, which can be operated and configured separately.

	<figure markdown>
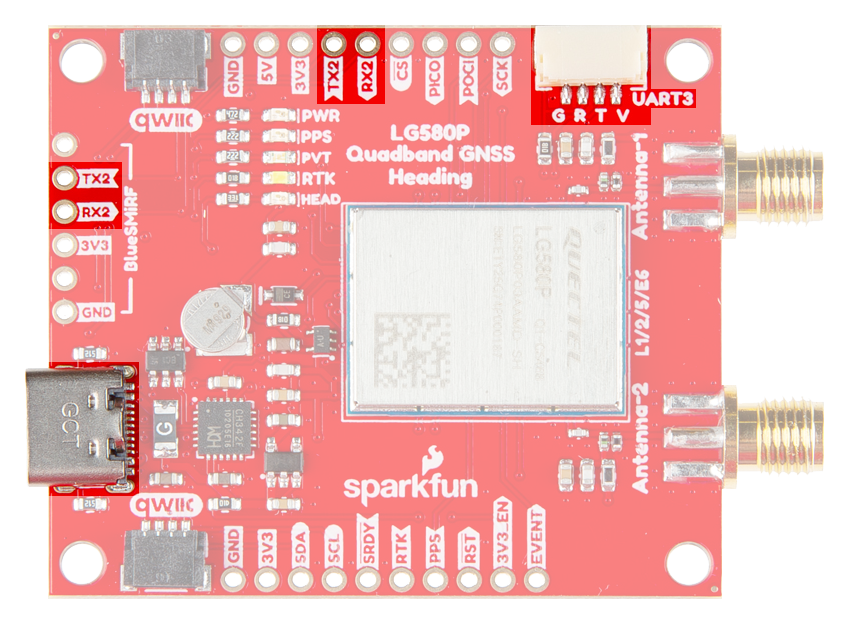
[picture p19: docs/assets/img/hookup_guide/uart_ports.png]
UART interface
	
	<figcaption markdown>The UART ports on the Quad-band GNSS RTK breakout board.</figcaption>
	</figure>

	??? tip "Pin Connections"
		When connecting to the UART pins to another device, the signals should be connected based upon the flow of their data.

		<article style="text-align: center;" markdown>

		<table>
		<tr>
		<th>Board</th>
		<td align="center">RX</td>
		<td align="center">TX</td>
		<td align="center">GND</td>
		</tr>
		<tr>
		<th>UART Device</th>
		<td align="center">TX</td>
		<td align="center">RX</td>
		<td align="center">GND</td>
		</tr>
		</table>

		</article>

	</div>

	<div markdown>

	!!! info "UART Settings"
		The UART ports have the following configuration settings:

		- Logic Level: **3.3V**
		- Baudrate: 9600bps, 115200bps, 230400bps, 460800bps, 921600bps, and 3000000bps 
		- Data Bits: 8
		- Parity: No
		- Stop Bits: 1
		- Flow Control: N/A
		- Supported Protocols:
			- `NMEA 0183` (`PQTM`)
			- `RTCM 3.x`
			- `QGC`

		??? note "Additional Support"
			All of the UART ports support firmware updates through their interface. In addition, the `UART1` port also supports debugging data and the `UART3` interface can be multiplexed for the CAN bus interface[^1].

	</div>

	</div>

	=== "`UART1`"
		`UART1` can only be accessed from the [USB-C connector](#usb-c-connector), through the CH342 serial-to-USB converter. For Windows and MacOS computers, a [USB driver must be installed](#ch342-converter) in order to communicate with the LG580P module through the CH342 converter; however for Linux operating systems, the standard Linux CDC-ACM driver is suitable. Once the USB driver has been installed:

		- Two virtual `COM` ports are emulated, which can be used as standard `COM` ports to access the receiver.
		- Users should select `COM` port with the lower enumeration or listed as `Channel A`.

	=== "`UART2`"
		`UART2` is available through the breakout [PTH](https://en.wikipedia.org/wiki/Through-hole_technology "Plated Through Holes") pins or the [BlueSMiRF header pins](#bluesmirf-header). The pin layout of the BlueSMiRF header is pin compatible with many of our serial devices (i.e. [UART adapters](https://www.sparkfun.com/categories/349), [*serial* data loggers](https://www.sparkfun.com/categories/589), [BlueSMiRF transceivers](https://www.sparkfun.com/categories/tags/bluesmirf)).

	=== "`UART3`"
		`UART3` is available through the [JST connector](#jst-connector). The pin layout of the 4-pin locking JST-GH connector is compatible with many of our [serial radios and adapter cables](hardware_assembly.md#radio-transceivers).

	??? info "UART Protocols"
		#### UART Protocols
		By default, these UART ports are configured to transmit and receive `NMEA 0183`, `RTCM 3.x`, and/or `QGC` messages. These messages are generally used for transmitting PNT data; providing or receiving RTK corrections; and receiving PPP data, respectively. Quectel also implements a system of proprietary messages (`PQTM`) for users to configure the LG580P that follows a data format similar to the `NMEA` protocol. The expected structure of these proprietary messages is shown below:

		<div class="grid" markdown>

		<div markdown>

		<figure markdown>
		NMEA data structure
		<figcaption markdown>The data structure of Quectel messages for the `NMEA` and `PQTM` protocols.</figcaption>
		</figure>

		</div>

		<div markdown>

		<figure markdown>
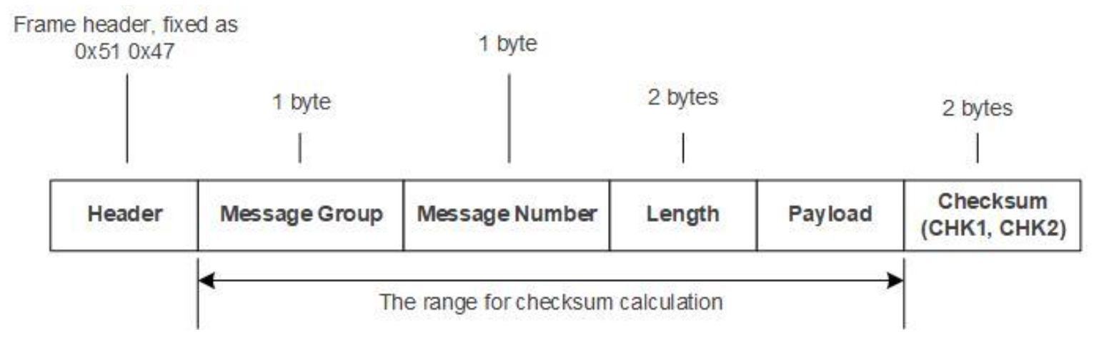
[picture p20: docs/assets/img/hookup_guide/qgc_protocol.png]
QGC data structure
		
		<figcaption markdown>The data structure of Quectel messages for the `QGC` protocol.</figcaption>
		</figure>

		</div>

		</div>

		=== "NMEA"
			A full list of compatible `NMEA 0183` v4.11 messages, is provided in section **2.2. Standard Messages** of the [GNSS Protocol Specification](./assets/component_documentation/quectel_lg290p03lgx80p03_gnss_protocol_specification_v1-1.pdf) manual. This protocol is used for outputting GNSS data, as detailed by the [National Marine Electronics Association](https://www.nmea.org/) organization.

			??? abstract "List of Standard NMEA Messages"
				<article style="text-align: center;" markdown>

				| Message | Type Mode | Message Description               |
				| :-----: | :-------: | :-------------------------------- |
				| RMC | Output | Recommended Minimum Specific GNSS Data   |
				| GGA | Output | Global Positioning System Fix Data       |
				| GSV | Output | GNSS Satellites in View                  |
				| GSA | Output | GNSS DOP and Active Satellites           |
				| VTG | Output | Course Over Ground & Ground Speed        |
				| GLL | Output | Geographic Position – Latitude/Longitude |
				| GBS | Output | GNSS Satellite Fault Detection           |
				| GNS | Output | GNSS Fix Data                            |
				| GST | Output | GNSS Pseudorange Error Statistics        |
				| ZDA | Output | UTC Time & Date                          |
				| HDT | Output | True Vessel Heading                      |
				| THS | Output | True, Heading, and Status                |

				</article>

		=== "PQTM"
			A full list of PQTM messages (proprietary NMEA messages defined by Quectel) supported by LG580P, is provided in section **2.3. PQTM Messages** of the [GNSS Protocol Specification](./assets/component_documentation/quectel_lg290p03lgx80p03_gnss_protocol_specification_v1-1.pdf) manual. This protocol is used to configure or read the settings for the LG580P GNSS module.

			??? abstract "List of Proprietary Quectel Messages"
				<article style="text-align: center;" markdown>

				| Message            | Type Mode    | Message Description                              |
				| :----------------- | :----------: | :----------------------------------------------- |
				| PQTMVER            | Output       | Outputs the firmware version                     |
				| PQTMCOLD           | Command      | Performs a cold start                            |
				| PQTMWARM           | Command      | Performs a warm start                            |
				| PQTMHOT            | Command      | Performs a hot start                             |
				| PQTMSRR            | Command      | Performs a system reset and reboots the receiver |
				| PQTMUNIQID         | Command      | Queries the module unique ID                     |
				| PQTMSAVEPAR        | Command      | Saves the configurations into NVM                |
				| PQTMRESTOREPAR     | Command      | Restores the parameters configured by all commands to their default values |
				| PQTMVERNO          | Command      | Queries the firmware version                     |
				| PQTMCFGUART        | Set/Get      | Sets/gets the UART interface                     |
				| PQTMCFGPPS         | Set/Get      | Sets/gets the PPS feature                        |
				| PQTMCFGPROT        | Set/Get      | Sets/gets the input and output protocol for a specified port |
				| PQTMCFGNMEADP      | Set/Get      | Sets/gets the decimal places of standard NMEA messages |
				| PQTMEPE            | Output       | Outputs the estimated position error             |
				| PQTMCFGMSGRATE     | Set/Get      | Sets/gets the message output rate on the current interface |
				| PQTMVEL            | Output       | Outputs the velocity information                 |
				| PQTMCFGGEOFENCE    | Set/Get      | Sets/gets geofence feature                       |
				| PQTMGEOFENCESTATUS | Output       | Outputs the geofence status                      |
				| PQTMGNSSSTART      | Command      | Starts GNSS engine                               |
				| PQTMGNSSSTOP       | Command      | Stops GNSS engine                                |
				| PQTMTXT            | Output       | Outputs short text messages                      |
				| PQTMCFGSVIN        | Set/Get      | Sets/gets the Survey-in feature                  |
				| PQTMSVINSTATUS     | Output       | Outputs the Survey-in status                     |
				| PQTMPVT            | Output       | Outputs the PVT (GNSS only) result               |
				| PQTMCFGRCVRMODE    | Set/Get      | Sets/gets the receiver working mode              |
				| PQTMDEBUGON        | Command      | Enables debug log output                         |
				| PQTMDEBUGOFF       | Command      | Disables debug log output                        |
				| PQTMCFGFIXRATE     | Set/Get      | Sets/gets the fix interval                       |
				| PQTMCFGRTK         | Set/Get      | Sets/gets the RTK mode                           |
				| PQTMCFGCNST        | Set/Get      | Sets/gets the constellation configuration        |
				| PQTMDOP            | Output       | Outputs dilution of precision                    |
				| PQTMPL             | Output       | Outputs protection level information             |
				| PQTMCFGODO         | Set/Get      | Sets/gets the odometer feature                   |
				| PQTMRESETODO       | Command      | Resets the accumulated distance recorded by the odometer |
				| PQTMODO            | Output       | Outputs the odometer information                 |
				| PQTMCFGSIGNAL      | Set/Get      | Sets/gets GNSS signal mask                       |
				| PQTMCFGSAT         | Set/Get      | Sets/gets GNSS satellite mask                    |
				| PQTMCFGRSID        | Set/Get      | Sets/gets the reference station ID               |
				| PQTMCFGRTCM        | Set/Get      | Sets/gets RTCM                                   |
				| PQTMCFGSBAS        | Set/Get      | Configures SBAS                                  |
				| PQTMCFGNMEATID     | Set/Get      | Configures the NMEA Talker ID                    |
				| PQTMTAR            | Output       | Outputs the time and attitude                    |
				| PQTMCFGBLD         | Set/Get      | Configures the baseline distance                 |
				| PQTMCFGRTKSRCTYPE  | Set/Get      | Configures RTK differential source type          |
				| PQTMSN             | Command      | Reads the SN of module                           |
				| PQTMCFGANTINF      | Set/Get      | Configures the antenna information               |
				| PQTMCFGANTDELTA    | Set/Get      | Configures the delta between antennas            |
				| PQTMCFGSIGGRP      | Set/Get      | Configures the GNSS signal group                 |
				| PQTMCFGSIGNAL2     | Set/Get      | Configures GNSS signal mask for second antenna   |
				| PQTMCFGGEOSEP      | Set/Get      | Configures geoidal separation                    |
				| PQTMCFGCNRTHD      | Set/Get      | Configures the CNR threshold for position engine |
				| PQTMCFGELETHD      | Set/Get      | Configures the elevation threshold for position engine |
				| PQTMNAV            | Output       | Outputs the navigation information               |
				| PQTMEOE            | Output       | Outputs the end of epoch information             |
				| PQTMCFGWN          | Set/Get      | Configures the reference start week number       |
				| PQTMANTENNASTATUS  | Output       | Reports the antenna status                       |

				</article>

		=== "QGC"
			A full list of QGC messages (proprietary protocol defined by Quectel) supported by LG580P, is provided in section **3. QGC Protocol** of the [GNSS Protocol Specification](./assets/component_documentation/quectel_lg290p03lgx80p03_gnss_protocol_specification_v1-1.pdf) manual. This protocol is used to output the PPP raw data.

			??? abstract "List of Proprietary Quectel Messages"
				<article style="text-align: center;" markdown>

				| GQC Message Name | Message Group | Message Number | Type | Description |
				| :--------- | :--: | :--: | :----: | :--------------------------------- |
				| RAW-PPPB2B | 0x0A | 0xB2 | Output | BDS PPPB2B binary raw messages     |
				| RAW-QZSSL6 | 0x0A | 0xB6 | Output | QZSSL6 binary raw messages         |
				| RAW-HASE6  | 0x0A | 0xE6 | Output | Galileo HASE6 binary raw messages  |

				</article>

		=== "RTCM"
			A full list of compatible `RTCM v3` messages, is provided in section **4. RTCM Protocol** of the [GNSS Protocol Specification](./assets/component_documentation/quectel_lg290p03lgx80p03_gnss_protocol_specification_v1-1.pdf) manual. This protocol is used for transferring GNSS raw measurement data, as detailed by the [Radio Technical Commission for Maritime Services](https://www.rtcm.org/) organization.

			??? abstract "List of Supported RTCMv3 *(MSM)* Messages"
				<article style="text-align: center;" markdown>

				| Message | Type Mode | Message Description                              |
				| :--: | :----------: | :----------------------------------------------- |
				| 1005 | Input/Output | Stationary RTK Reference Station ARP             |
				| 1006 | Input/Output | Stationary RTK Reference Station ARP with height |
				| 1019 | Input/Output | GPS Ephemerides                                  |
				| 1020 | Input/Output | GLONASS Ephemerides                              |
				| 1041 | Input/Output | NavIC/IRNSS Ephemerides                          |
				| 1042 | Input/Output | BDS Satellite Ephemeris Data                     |
				| 1044 | Input/Output | QZSS Ephemerides                                 |
				| 1046 | Input/Output | Galileo I/NAV Satellite Ephemeris Data           |
				| 1073 | Input/Output | GPS MSM3 |
				| 1074 | Input/Output | GPS MSM4 |
				| 1075 | Input/Output | GPS MSM5 |
				| 1076 | Input/Output | GPS MSM6 |
				| 1077 | Input/Output | GPS MSM7 |
				| 1083 | Input/Output | GLONASS MSM3 |
				| 1084 | Input/Output | GLONASS MSM4 |
				| 1085 | Input/Output | GLONASS MSM5 |
				| 1086 | Input/Output | GLONASS MSM6 |
				| 1087 | Input/Output | GLONASS MSM7 |
				| 1093 | Input/Output | Galileo MSM3 |
				| 1094 | Input/Output | Galileo MSM4 |
				| 1095 | Input/Output | Galileo MSM5 |
				| 1096 | Input/Output | Galileo MSM6 |
				| 1097 | Input/Output | Galileo MSM7 |
				| 1113 | Input/Output | QZSS MSM3 |
				| 1114 | Input/Output | QZSS MSM4 |
				| 1115 | Input/Output | QZSS MSM5 |
				| 1116 | Input/Output | QZSS MSM6 |
				| 1117 | Input/Output | QZSS MSM7 |
				| 1123 | Input/Output | BDS MSM3 |
				| 1124 | Input/Output | BDS MSM4 |
				| 1125 | Input/Output | BDS MSM5 |
				| 1126 | Input/Output | BDS MSM6 |
				| 1127 | Input/Output | BDS MSM7 |
				| 1133 | Input/Output | NavIC/IRNSS MSM3 |
				| 1134 | Input/Output | NavIC/IRNSS MSM4 |
				| 1135 | Input/Output | NavIC/IRNSS MSM5 |
				| 1136 | Input/Output | NavIC/IRNSS MSM6 |
				| 1137 | Input/Output | NavIC/IRNSS MSM7 |

				</article>

=== "I^2^C"
	<div class="grid" markdown>

	<div markdown>

	While not implemented yet, the I^2^C interface is available through the breakout [PTH](https://en.wikipedia.org/wiki/Through-hole_technology "Plated Through Holes") pins or the Qwiic connectors.

	<figure markdown>
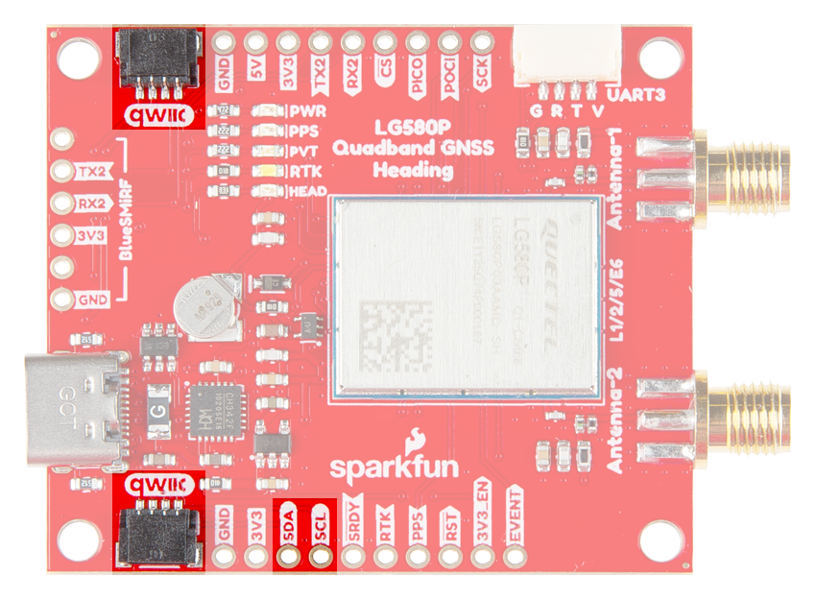
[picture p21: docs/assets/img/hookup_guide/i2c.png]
I2C interface
	
	<figcaption markdown>The I^2^C interface on the Quad-band GNSS RTK breakout board.</figcaption>
	</figure>

	</div>

	<div markdown>

	!!! info "I^2^C Settings"
		By default, the UART ports are configured with the following settings:

		- Logic Level: **3.3V**
		- I^2^C Address: N/A
		- Bitrate: up to **400kbps**
		- Protocols:
			- `NMEA`
			- `PQTM`
			- `RTCM`
		- Built-in 2.2k&ohm; pull-up resistors

	</div>

	</div>

=== "SPI"
	<div class="grid" markdown>

	<div markdown>

	While not implemented yet, the SPI interface is available through the breakout [PTH](https://en.wikipedia.org/wiki/Through-hole_technology "Plated Through Holes") pins.

	<figure markdown>
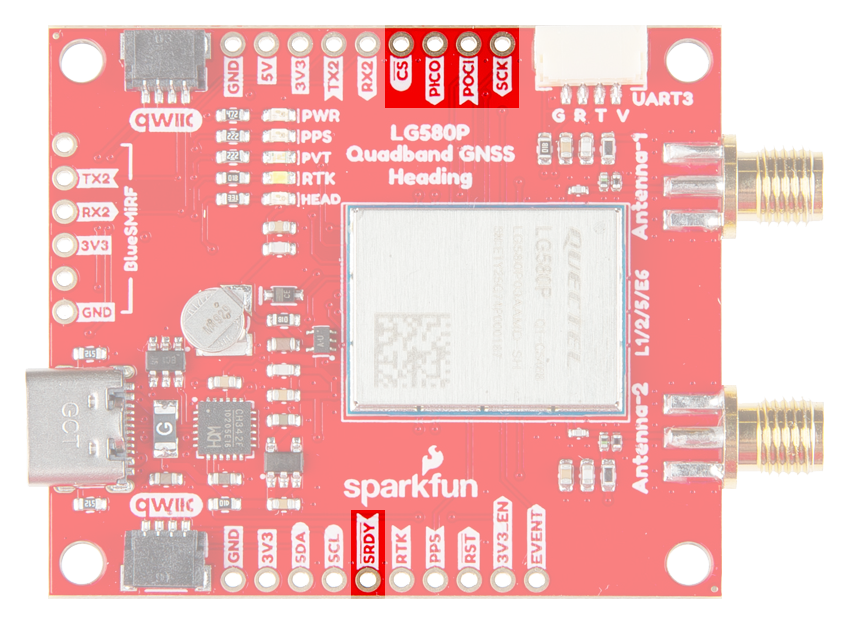
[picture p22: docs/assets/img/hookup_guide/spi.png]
SPI interface
	
	<figcaption markdown>The SPI interface on the Quad-band GNSS RTK breakout board.</figcaption>
	</figure>

	</div>

	<div markdown>

	!!! info "SPI Settings"
		By default, the UART ports are configured with the following settings:

		- Logic Level: **3.3V**
		- Baudrate: 1Mbps – 3Mbps
		- Protocols:
			- `NMEA`
			- `PQTM`
			- Firmware updates

	!!! note "`SRDY` Pin"
		The `SDRY` pin functions as the interrupt output for the SPI interface. By default, the pin is `LOW`.

	</div>

	</div>

=== "PPS Output"
	From the module, the [PPS](https://en.wikipedia.org/wiki/Pulse-per-second_signal "Pulse Per Second") output signal is a 3.3V signal output that can be accessed from the `PPS` [PTH](https://en.wikipedia.org/wiki/Through-hole_technology "Plated Through Holes") pin. The signal is also connected to the `PPS` LED, which can be used as a visual indicator for its operation.

	<figure markdown>
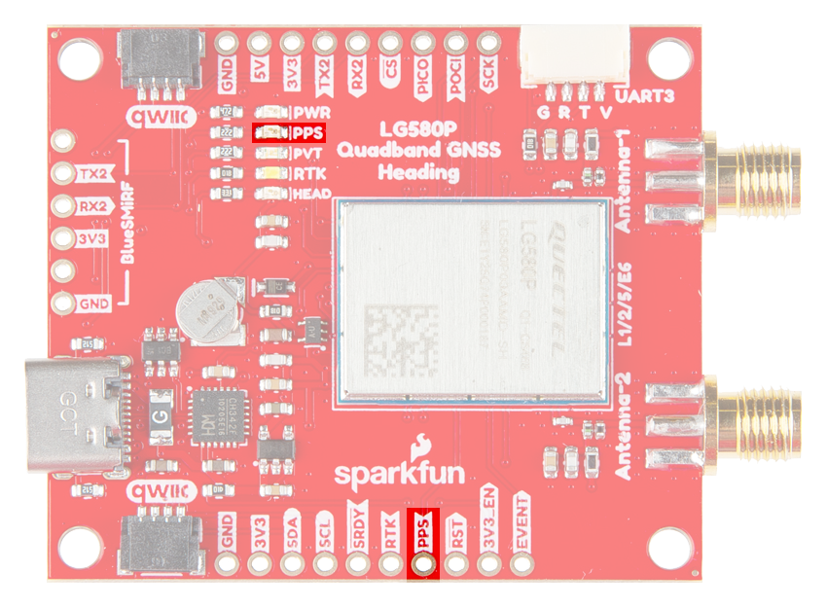
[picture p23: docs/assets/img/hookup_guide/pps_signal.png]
I/O for PPS signal
	
	<figcaption markdown>The timing signal's outputs on the Quad-band GNSS RTK breakout board.</figcaption>
	</figure>

	???+ tip "Jumpers"
		*See the **[Jumpers](#jumpers)** section for more details.*

		- There is a jumper attached to the `PPS` LED. For low power applications, the jumper can be cut to disable the `PPS` LED.

	!!! tip "Use Case"
		- Users could use this signal in conjunction with the event pins to synchronize two modules with each other.
		- Users could use this signal to create their own **Stratum 0** source for the [NTP](https://en.wikipedia.org/wiki/Network_Time_Protocol "Network Time Protocol") on a primary time server.

=== "RTK"
	The `RTK` [PTH](https://en.wikipedia.org/wiki/Through-hole_technology "Plated Through Holes") pin operates as the `RTK_STAT` status indicator for the [RTK](https://en.wikipedia.org/wiki/Real-time_kinematic_positioning "Real-Time Kinematic") positioning. The pin is also connected to the `RTK` LED, which can be used as a visual indicator for its operation.

	<figure markdown>
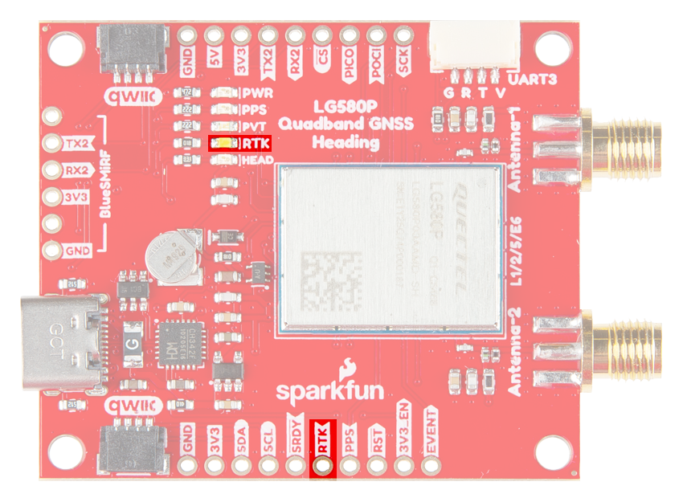
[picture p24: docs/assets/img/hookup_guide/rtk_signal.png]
I/O for RTK signal
	
	<figcaption markdown>The RTK signal's outputs on the Quad-band GNSS RTK breakout board.</figcaption>
	</figure>

	!!! info
		The `RTK_STAT` pin is used to indicate [RTK](https://en.wikipedia.org/wiki/Real-time_kinematic_positioning "Real-Time Kinematic") status. The pin is at high level during startup.

		1. If the pin output is high, it indicates the module has entered the RTK fixed mode.
		2. If the pin output is low, it indicates that the module exited the RTK fixed mode or is in [Backup mode](#power-modes).
		3. If the pin outputs an alternating pin level, it indicates that the module received the correct RTCM data and did not enter the RTK fixed mode. The default frequency is 10Hz.

	???+ tip "Jumpers"
		*See the **[Jumpers](#jumpers)** section for more details.*

		- There is a jumper attached to the `RTK` LED. For low power applications, the jumper can be cut to disable the `RTK` LED.

=== "Event"
	The `EVENT` pin provides event inputs with adjustable input frequentness and polarity.

	<figure markdown>
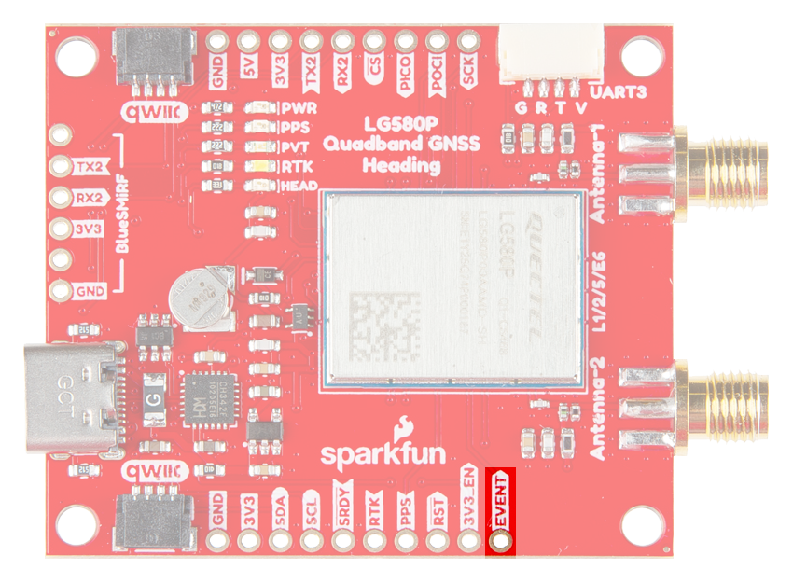
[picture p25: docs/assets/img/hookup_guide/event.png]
	
	<figcaption markdown>The `EVENT` pin on the Quad-band GNSS RTK breakout board.</figcaption>
	</figure>

	!!! tip "Use Case"
		Users could use this pin in conjunction with the PPS signal to synchronize two modules with each other.

=== "Reset"
	The `RST` pin can be used to reset the LG580P module if it enters an abnormal state. To reset the GNSS module, the pin must be low for more than 100ms.

	<figure markdown>
	Reset Pin
	<figcaption markdown>The `RST` pin on the Quad-band GNSS RTK breakout board.</figcaption>
	</figure>

## SMA Connectors
There are two SMA connectors on the Quad-band GNSS RTK breakout board. The `Antenna-1` connector is the primary input for a GNSS antenna for the LG580P GNSS receiver. The `Antenna-2` connector operates as a secondary GNSS antenna input to provide a heading and pitch solution from the LG580P GNSS receiver.

<figure markdown>
SMA Connectors
<figcaption markdown>The SMA connectors for an external GNSS antennas on the Quad-band GNSS RTK breakout board.</figcaption>
</figure>

!!! warning "Antenna Specifications"
	- Passive antennas are not recommended for the LG580P GNSS module.
	- To mitigate the impact of out-of-band signals, utilize an active antenna whose SAW filter is placed in front of the LNA in the internal framework.
		- **DO NOT** select and antenna with the LNA placed in the front.
	- There is no need to inject an external DC voltage into the SMA connector for the GNSS antenna. Power is already provided from the LG580P module for the LNA of an active antenna.

!!! tip
	For the best performance, we recommend users choose compatible L1/L2/L5/L6/L-Band GNSS antennas and utilize a low-loss cables. Also, don't forget that GNSS signals are fairly weak and can't penetrate buildings or dense vegetation. The GNSS antennas should have an unobstructed view of the sky.

## JST Connector
The Quad-band GNSS RTK breakout features a 4-pin [JST GH connector](./assets/component_documentation/JST-GH_datasheet.pdf), which is polarized and locking. Users can access pins of the `UART3` port with our [breadboard cable](https://www.sparkfun.com/breadboard-to-jst-ghr-04v-cable-4-pin-x-1-25mm-pitch.html). Otherwise, the connector's pin layout is compatible with any of our [serial radios and adapter cables](hardware_assembly.md#radio-transceivers).

<figure markdown>
JST connector
<figcaption markdown>The JST connector on the Quad-band GNSS RTK breakout board.</figcaption>
</figure>

??? info "Pin Connections"
	#### Pin Connections
	When connecting the Quad-band GNSS RTK breakout board to other products, users need to be aware of the pin connections between the devices.

	<article style="text-align: center;" markdown>

	<table border="1" markdown>
	<tr>
	<th style="vertical-align:middle;">Pin Number</th>
	<td align="center">
		**1**<br>
		*(Left Side)*
	</td>
	<td align="center">**2**</td>
	<td align="center">**3**</td>
	<td align="center">**4**</td>
	</tr>
	<tr>
	<th>Label</th>
	<td align="center">VCC</td>
	<td align="center">TX3</td>
	<td align="center">RX3</td>
	<td align="center">GND</td>
	</tr>
	<tr>
	<th style="vertical-align:middle;">Function</th>
	<td>
		<u>**Voltage Output**</u><br>
		- **Default: 3.3V**<br>
		- Selectable: 3.3V or 5V
	</td>
	<td align="center" style="vertical-align:middle;">`UART3` - Receive</td>
	<td align="center" style="vertical-align:middle;">`UART3` - Transmit</td>
	<td align="center" style="vertical-align:middle;">Ground</td>
	</tr>
	</table>

	</article>

	<div class="grid" markdown>

	<div markdown>

	When connecting the Quad-band GNSS RTK breakout board to our radios, the pin connections should follow the table below. If the flow control is not enabled, the only the `RX`, `TX`, and `GND` pins are utilized.

	<article style="text-align: center;" markdown>

	<table markdown>
	<tr>
	<th>Board</th>
	<td align="center">RX</td>
	<td align="center">TX</td>
	<td align="center">GND</td>
	</tr>
	<tr>
	<th>Radio</th>
	<td align="center">TX</td>
	<td align="center">RX</td>
	<td align="center">GND</td>
	</tr>
	</table>

	</article>

	</div>

	<div markdown>

	As documented in the [LoRaSerial product manual](https://docs.sparkfun.com/SparkFun_LoRaSerial), the pin connections between a host system *(i.e. Quad-band GNSS RTK breakout board)* and the LoRaSerial Kit radio is outlined in the image below.

	<figure markdown>
	Flow Control (https://docs.sparkfun.com/SparkFun_LoRaSerial/img/SAMD21%20Flow%20control.png "Click to enlarge")
	<figcaption markdown>The `COM` ports on the Quad-band GNSS RTK breakout board.</figcaption>
	</figure>

	</div>

	</div>

???+ tip "Jumpers"
	By default, the [`VSEL` jumper](#jumpers) is connected to `3V3` pad for a regulated 3.3V output on the 4-pin JST-GH connector.

## BlueSMiRF Header
The Quad-band GNSS RTK breakout features a 6-pin BlueSMiRF [PTH](https://en.wikipedia.org/wiki/Through-hole_technology "Plated Through Holes") header for `UART2`. The pin layout of which, is compatible with many of our serial devices (i.e. [UART adapters](https://www.sparkfun.com/categories/349), [*serial* data loggers](https://www.sparkfun.com/categories/589), [BlueSMiRF transceivers](https://www.sparkfun.com/categories/tags/bluesmirf)).

<figure markdown>
BlueSMiRF header
<figcaption markdown>The 6-pin BlueSMiRF PTH header on the Quad-band GNSS RTK breakout board.</figcaption>
</figure>

???+ tip "Jumpers"
	By default, the [`BT_VCC` jumper](#jumpers) provides a regulated 3.3V output to the BlueSMiRF header.

## Status LEDs

<div class="grid" markdown>

<div markdown>

There are four status LEDs on the Quad-band GNSS RTK breakout board:

<figure markdown>
Status LEDs
<figcaption markdown>The status LED indicators on the Quad-band GNSS RTK breakout board.</figcaption>
</figure>

</div>

<div markdown>

- `PWR` - Power *(Red)*
	- Turns on once 3.3V power is supplied to the board
- `PPS` - [Pulse-Per-Second](https://en.wikipedia.org/wiki/Pulse-per-second_signal) Signal *(Yellow)*
	- Indicates when there is a pulse-per-second signal *(see the **[PPS Output](#pps-output)** section)*
- `PVT` - Position-Velocity-Time Solution *(Blue)*
	- **On:** Indicates the module has entered PVT mode
	- **Off:** Indicates that the module has exited PVT mode or is in [Backup mode](#power-modes).
- `RTK` - [Real-Time Kinematic](https://en.wikipedia.org/wiki/Real-time_kinematic_positioning) Mode *(White)*
	- Indicates when an RTK fix has been established or when the correct RTCM data is being received *(see the **[RTK](#rtk)** section)*
- `HEAD` - Heading Solution *(Green)*
	- **On:** Indicates the module has entered Heading fixed mode
	- **Off:** Indicates that the module has exited Heading fixed mode or is in [Backup mode](#power-modes).

</div>

</div>

!!! info
	- The [`PPS`](https://en.wikipedia.org/wiki/Pulse-per-second_signal "Pulse Per Second") LED is also connected to the [`PPS` pin](#pps-output).
	- The [`RTK`](https://en.wikipedia.org/wiki/Real-time_kinematic_positioning "Real-Time Kinematic") LED is also connected to the [`RTK` pin](#rtk).

???+ tip "Jumpers"
	There are jumper attached to the LEDs. For low power applications, these jumpers can be cut to disable their respective LED. *See the **[Jumpers](#jumpers)** section for more details.*

## Jumpers

??? note "Never modified a jumper before?"
	Check out our <a href="https://learn.sparkfun.com/tutorials/664">Jumper Pads and PCB Traces tutorial</a> for a quick introduction!

	<div class="grid cards" markdown align="center">

	-   <a href="https://learn.sparkfun.com/tutorials/664">
		<figure markdown>
		Tutorial thumbnail
		</figure>

		---

		**How to Work with Jumper Pads and PCB Traces**</a>

	</div>

There are seven jumpers on the back of the board that can be used to easily modify the hardware connections on the board. From which, there are three jumpers that control power to the status LEDs on the board. By default, all the jumpers are connected, to power the status LEDs. For low power applications, users can cut the jumpers to disconnect power from each of the LEDs.

<figure markdown>
Jumpers
<figcaption markdown>The jumpers on the back of the Quad-band GNSS RTK breakout board.</figcaption>
</figure>

- **`VSEL`** - This jumper can be modified to configure/disconnect the `VCC` pin of the 4-pin locking JST connector to/from `3V3` or `5V` power.
- **`BT_VCC`** - This jumper can be cut to disconnect the `3V3` BlueSMiRF header pin from the 3.3V output of the RT9080 LDO regulator.
- **`PWR`** - This jumper can be cut to remove power from the red, power LED.
- **`PPS`** - This jumper can be cut to remove power from the yellow `PPS` LED, indicating when there is a [PPS](https://en.wikipedia.org/wiki/Pulse-per-second_signal "Pulse Per Second") signal.
- **`PVT`** - This jumper can be cut to remove power from the blue `PVT` LED, indicating a PVT solution or operation in PVT mode.
- **`RTK`** - This jumper can be cut to remove power from the white `RTK` LED, indicating RTK fix or operation in RTK mode.
- **`HEADING`** - This jumper can be cut to remove power from the green `HEAD` LED, indicating a heading solution or operation in Heading fixed mode.
- **`SHLD`** - This jumper can be cut to disconnect the shielding of the USB-C connector from the `GND` plane of the board

!!! info
	- By default, the `VSEL` jumper is connected to `3V3` pad for a regulated 3.3V output on the 4-pin JST-GH connector.
	- By default, the `BT_VCC` jumper provides a regulated 3.3V output to the BlueSMiRF header.

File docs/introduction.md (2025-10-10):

<figure markdown>
Hookup Guide - Thumbnail
</figure>

---

# Introduction

<div class="grid cards desc" markdown>

-   <a href="https://www.sparkfun.com/sparkfun-quadband-gnss-rtk-with-heading-breakout-lg580p-qwiic.html">
	**SparkFun Quadband GNSS RTK with Heading Breakout - LG580P (Qwiic)**<br>
	**SKU:** GPS-28019

	---

	<figure markdown>
	Product Thumbnail
	</figure></a>

	<article style="text-align: center;" markdown>
	QR code to product page [Purchase from SparkFun :fontawesome-solid-cart-plus:{ .heart }](https://www.sparkfun.com/sparkfun-quadband-gnss-rtk-with-heading-breakout-lg580p-qwiic.html){ .md-button .md-button--primary }
	</article>

-	The [SparkFun Quadband GNSS RTK with Heading Breakout - LG580P (Qwiic)](https://www.sparkfun.com/sparkfun-quadband-gnss-rtk-with-heading-breakout-lg580p-qwiic.html) features the Quectel LG580P GNSS module, providing exceptional positioning and heading accuracy. The LG580P GNSS module is an upgraded version of the LG290P on our [SparkFun Quadband GNSS RTK Breakout - LG290P (Qwiic)](https://www.sparkfun.com/sparkfun-quadband-gnss-rtk-breakout-lg290p-qwiic.html); providing an additional GNSS antenna input for instantaneous heading determination down to 0.1&deg;. In traditional navigation systems, such as those used on your phone or car, previous navigation points are utilized to determine the course heading. This is the reason why the arrow indicator will spin or be oriented in the wrong directions when the navigation system first boots or has been stationary for extended periods of time. However, with the LG580 GNSS module, users are provided with a dedicated heading without relying on previous course data points, magnetometers/compasses, or gyroscopes in IMUs, which can introduce small errors.

	The board's dimensions, pin layout, and connectors are similar to our very popular [SparkFun GPS-RTK-SMA Breakout - ZED-F9P (Qwiic)](https://www.sparkfun.com/sparkfun-gps-rtk-sma-breakout-zed-f9p-qwiic.html), featuring a compact design and convenient Qwiic connectors. *(\*Depending on your application, this board could potentially function as a drop-in replacement; users should verify the pin compatibility of this board with their current installation.)* The board also accommodates users with a diverse choice of interfaces including UART, SPI*, I^2^C*, and CAN*. The board has three UART ports, which are accessible through the USB-C connector, BlueSMiRF *(6-pin PTH)* header, and 4-pin locking JST connector. Users can also interface with the board through the 25 PTH pins that are broken out around the edge of the board. For the GNSS antenna(s), SMA antenna connectors are provided on the edge of the board; an optional, secondary antenna can be utilized for heading determination. We also provide two 4-pin JST Qwiic connectors for future use, when the I^2^C feature becomes available for the GNSS module.

	The LG580P module is a quad-band, multi-constellation, high-precision, RTK and heading GNSS receiver. The module is capable of simultaneously receiving signals from the `L1`, `L2`, `L5`, and `L6`/`E6` frequency bands of the GPS, GLONASS, Galileo, BDS, QZSS, and NavIC GNSS constellations. In addition, the module supports SBAS augmentation systems (WAAS, EGNOS, BDSBAS, MSAS, GAGAN, KASS, ASECNA, SouthPAN, and SDCM), PPP services* (BDS PPP-B2b, QZSS CLAS, MADOCA-PPP, and Galileo HAS), RTCM, and RTK corrections for precision navigation with a fast convergence time and reliable performance.

	The built-in professional-grade interference signal detection and elimination algorithms, effectively mitigate multiple narrow-band interference sources and significantly improve signal reception performance in complex electromagnetic environments. In addition, the RTK and heading algorithms ensure reliable positioning in challenging scenarios such as urban environments and deep tree cover. With its high-precision, low power consumption and a high positioning and heading update rate of up to 20 Hz, this board is ideal for high-precision navigation applications, such as intelligent robots, precision agriculture, ADAS, and autonomous driving.

</div>

!!! warning "Features Under Development"
	- **I^2^C/SPI/CAN** - Currently, only the UART interface is supported by the module.
	- **PPP Services** - Corrections for some of the PPP services have not been implemented.

??? question "Product Comparison"
	<article style="text-align: center;" markdown>

	| Characteristics | LG580P | LG290P |
	| :-------------- | :----: | :----: |
	| Supply Voltage:                   | 3.0–3.6V | 3.15–3.45V |
	| Acquisition Current:              | 98mA (323.4mW)  | 91mA (300.3mW) |
	| Tracking Current:                 | 116mA (382.8mW) | 91mA (300.3mW) |
	| Backup Mode Current:              | 18μA (59.4μmW)  | 12μA (39.6mW)  |
	| GPS Frequency bands:              | `---`    | `L1C`*     |
	| QZSS Frequency bands:             | `---`    | `L1C`*     |
	| SBAS Frequency bands:             | `L1`     | `L1 C/A`   |
	| Horizontal Accuracy (Autonomous): | 1m       | 0.7m       |
	| Vertical Accuracy (Autonomous):   | 1.5m     | 2.5m       |
	| Heading Accuracy:                 | 0.1&deg; | NA         |
	| TTFF (Hot Start):                 | 1.8s     | 1.7s       |
	| Sensitivity (Acquisition):        | -145dBm  | -146dBm    |
	| Antenna Power Supply:             | External | External or Internal |
	| UART Protocols:                   | `QGC`    | `---`      |
	| CAN Interface*:                   | x1       | NA         |
	| Footprint:                        | 21mm × 16mm × 2.7mm | 12.2mm × 16mm × 2.6mm |
	| Weight:                           | 1.4g     | ~0.9g      |

	</article>

	!!! note
		- `---`: Any remarks on the other module, are additional features
		- NA: Feature is not available for that module
		- *: Feature is still under development

In this guide we'll cover how to setup the LG580P GNSS breakout board. To follow along with this tutorial, at a minimum, users will need the following items:

<div class="annotate" markdown>

- Computer with an operating system (OS) that is compatible with all the software installation requirements
- [USB 3.1 Cable A to C - 3 Foot](https://www.sparkfun.com/usb-3-1-cable-a-to-c-3-foot.html) - Used to interface with the LG580P GNSS Breakout (1)
- [SparkFun Quadband GNSS RTK with Heading Breakout - LG580P (Qwiic)](https://www.sparkfun.com/sparkfun-quadband-gnss-rtk-with-heading-breakout-lg580p-qwiic.html)
- [GNSS Multi-Band L1/L2/L5 Surveying Antenna](https://www.sparkfun.com/gnss-multi-band-l1-l2-l5-surveying-antenna-tnc-spk6618h.html)
	- [SMA Male to TNC Male Cable](https://www.sparkfun.com/reinforced-interface-cable-sma-male-to-tnc-male-10m.html)
	- [Antenna Mount](https://www.sparkfun.com/gnss-magnetic-antenna-mount-5-8-11-tpi.html)

</div>

1. If your computer doesn't have a USB-A slot, then choose an appropriate cable or adapter.

<div class="grid cards" markdown>

-   <a href="https://www.sparkfun.com/usb-3-1-cable-a-to-c-3-foot.html">
	<figure markdown>
	USB 3.1 Cable A to C - 3 Foot
	</figure>

	---

	**USB 3.1 Cable A to C - 3 Foot**<br>
	CAB-14743</a>

-   <a href="https://www.sparkfun.com/sparkfun-quadband-gnss-rtk-with-heading-breakout-lg580p-qwiic.html">
	<figure markdown>
	Product Thumbnail
	</figure>

	---

	**SparkFun Quadband GNSS RTK with Heading Breakout - LG580P (Qwiic)**<br>
	GPS-28019</a>

-   <a href="https://www.sparkfun.com/gnss-multi-band-l1-l2-l5-surveying-antenna-tnc-spk6618h.html">
	<figure markdown>
	Product Thumbnail
	</figure>

	---

	**GNSS Multi-Band L1/L2/L5 Surveying Antenna - TNC (SPK6618H)**<br>
	GPS-21801</a>

-   <a href="https://www.sparkfun.com/reinforced-interface-cable-sma-male-to-tnc-male-10m.html">
	<figure markdown>
	Product Thumbnail
	</figure>

	---

	**Reinforced Interface Cable - SMA Male to TNC Male (10m)**<br>
	CAB-21740</a>

-   <a href="https://www.sparkfun.com/gnss-magnetic-antenna-mount-5-8-11-tpi.html">
	<figure markdown>
	Product Thumbnail
	</figure>

	---

	**GNSS Magnetic Antenna Mount - 5/8" 11-TPI**<br>
	PRT-21257</a>

</div>

## Section Topics
This guide is divided into multiple sections:

- The **Hardware** section has two sub-sections that provide:
	- An overview of the board's design, major components, and interfaces. Refer to this page for information on the connectors, breakout pins, and jumpers.
	- Assembly instructions for this product's interfaces.
- The **Software** section has several sub-sections. The LG580P module has numerous capabilities and a multitude of ways to configure and interface with them.
- In the **Resources** and **Support** sections, users can find the design files (KiCad files & schematic), relevant documentation (datasheets, white papers, etc.) and other helpful links on the Resources page. Lastly, the **Troubleshooting Tips** page includes helpful tips and instructions for how to receive technical support from SparkFun.

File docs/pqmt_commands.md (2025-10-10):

Below, are excerpts for a few of the PQTM messages from the [GNSS Protocol Specification](./assets/component_documentation/quectel_lg290p03lgx80p03_gnss_protocol_specification_v1-1.pdf) manual. Users will find these useful for configuring their LG580P GNSS module as an RTK base station or rover.

???+ info "Documentation"
	A full list of PQTM messages (proprietary NMEA messages defined by Quectel) supported by LG580P, is provided in section **2.3. PQTM Messages** of the [GNSS Protocol Specification](./assets/component_documentation/quectel_lg290p03lgx80p03_gnss_protocol_specification_v1-1.pdf) manual. This protocol is used to configure or read the settings for the LG580P GNSS module.

	??? abstract "List of Proprietary Quectel Messages"
		<article style="text-align: center;" markdown>

		| Message                             | Type Mode    | Message Description                              |
		| :---------------------------------- | :----------: | :----------------------------------------------- |
		| PQTMVER                             | Output       | Outputs the firmware version                     |
		| PQTMCOLD                            | Command      | Performs a cold start                            |
		| PQTMWARM                            | Command      | Performs a warm start                            |
		| PQTMHOT                             | Command      | Performs a hot start                             |
		| PQTMSRR                             | Command      | Performs a system reset and reboots the receiver |
		| PQTMUNIQID                          | Command      | Queries the module unique ID                     |
		| [PQTMSAVEPAR](#pqtmsavepar)         | Command      | Saves the configurations into NVM                |
		| [PQTMRESTOREPAR](#pqtmrestorepar)   | Command      | Restores the parameters configured by all commands to their default values |
		| PQTMVERNO                           | Command      | Queries the firmware version                     |
		| [PQTMCFGUART](#pqtmcfguart)         | Set/Get      | Sets/gets the UART interface                     |
		| PQTMCFGPPS                          | Set/Get      | Sets/gets the PPS feature                        |
		| [PQTMCFGPROT](#pqtmcfgprot)         | Set/Get      | Sets/gets the input and output protocol for a specified port |
		| PQTMCFGNMEADP                       | Set/Get      | Sets/gets the decimal places of standard NMEA messages |
		| PQTMEPE                             | Output       | Outputs the estimated position error             |
		| PQTMCFGMSGRATE                      | Set/Get      | Sets/gets the message output rate on the current interface |
		| PQTMVEL                             | Output       | Outputs the velocity information                 |
		| PQTMCFGGEOFENCE                     | Set/Get      | Sets/gets geofence feature                       |
		| PQTMGEOFENCESTATUS                  | Output       | Outputs the geofence status                      |
		| PQTMGNSSSTART                       | Command      | Starts GNSS engine                               |
		| PQTMGNSSSTOP                        | Command      | Stops GNSS engine                                |
		| PQTMTXT                             | Output       | Outputs short text messages                      |
		| [PQTMCFGSVIN](#pqtmcfgsvin)         | Set/Get      | Sets/gets the Survey-in feature                  |
		| PQTMSVINSTATUS                      | Output       | Outputs the Survey-in status                     |
		| PQTMPVT                             | Output       | Outputs the PVT (GNSS only) result               |
		| [PQTMCFGRCVRMODE](#pqtmcfgrcvrmode) | Set/Get      | Sets/gets the receiver working mode              |
		| PQTMDEBUGON                         | Command      | Enables debug log output                         |
		| PQTMDEBUGOFF                        | Command      | Disables debug log output                        |
		| PQTMCFGFIXRATE                      | Set/Get      | Sets/gets the fix interval                       |
		| [PQTMCFGRTK](#pqtmcfgrtk)           | Set/Get      | Sets/gets the RTK mode                           |
		| PQTMCFGCNST                         | Set/Get      | Sets/gets the constellation configuration        |
		| PQTMDOP                             | Output       | Outputs dilution of precision                    |
		| PQTMPL                              | Output       | Outputs protection level information             |
		| PQTMCFGODO                          | Set/Get      | Sets/gets the odometer feature                   |
		| PQTMRESETODO                        | Command      | Resets the accumulated distance recorded by the odometer |
		| PQTMODO                             | Output       | Outputs the odometer information                 |
		| PQTMCFGSIGNAL                       | Set/Get      | Sets/gets GNSS signal mask                       |
		| PQTMCFGSAT                          | Set/Get      | Sets/gets GNSS satellite mask                    |
		| PQTMCFGRSID                         | Set/Get      | Sets/gets the reference station ID               |
		| PQTMCFGRTCM                         | Set/Get      | Sets/gets RTCM                                   |
		| PQTMCFGSBAS                         | Set/Get      | Configures SBAS                                  |
		| PQTMCFGNMEATID                      | Set/Get      | Configures the NMEA Talker ID                    |
		| PQTMTAR                             | Output       | Outputs the time and attitude                    |
		| PQTMCFGBLD                          | Set/Get      | Configures the baseline distance                 |
		| PQTMCFGRTKSRCTYPE                   | Set/Get      | Configures RTK differential source type          |
		| PQTMSN                              | Command      | Reads the SN of module                           |
		| PQTMCFGANTINF                       | Set/Get      | Configures the antenna information               |
		| PQTMCFGANTDELTA                     | Set/Get      | Configures the delta between antennas            |
		| PQTMCFGSIGGRP                       | Set/Get      | Configures the GNSS signal group                 |
		| PQTMCFGSIGNAL2                      | Set/Get      | Configures GNSS signal mask for second antenna   |
		| PQTMCFGGEOSEP                       | Set/Get      | Configures geoidal separation                    |
		| PQTMCFGCNRTHD                       | Set/Get      | Configures the CNR threshold for position engine |
		| PQTMCFGELETHD                       | Set/Get      | Configures the elevation threshold for position engine |
		| PQTMNAV                             | Output       | Outputs the navigation information               |
		| PQTMEOE                             | Output       | Outputs the end of epoch information             |
		| PQTMCFGWN                           | Set/Get      | Configures the reference start week number       |
		| PQTMANTENNASTATUS                   | Output       | Reports the antenna status                       |

		</article>

## Save Parameters/Restore to Default Settings

#### `PQTMSAVEPAR`
:   Saves the current configurations into NVM of the LG580P

	```
	$PQTMSAVEPAR*<Checksum><CR><LF>
	```

	??? example
		Save the current settings to non-volatile memory of the LG580P.
		```
		$PQTMSAVEPAR*5A
		```

		If there are no errors, users will receive the following response:
		```
		$PQTMSAVEPAR,OK*72
		```

#### `PQTMRESTOREPAR`
:   Restores the parameters configured by all commands to their default values; this command takes effect after restarting the LG580P

	```
	$PQTMRESTOREPAR*<Checksum><CR><LF>	
	```

	??? example
		Restore all the settings of the LG580P to their factory defaults
		```
		$PQTMRESTOREPAR*13
		```

		If there are no errors, users will receive the following response:
		```
		$PQTMRESTOREPAR,OK*3B
		```

## UART Settings

#### `PQTMCFGUART`
:   Configures the serial protocol setting for the UART interfaces

	- Current UART interface:

		```
		$PQTMCFGUART,W,<BaudRate>[,<DataBit>,<Parity>,<StopBit>,<FlowCtrl>]*<Checksum><CR><LF>
		```

	- A specific UART interface:

		```
		$PQTMCFGUART,W,<Index>,<BaudRate>[,<DataBit>,<Parity>,<StopBit>,<FlowCtrl>]*<Checksum><CR><LF>
		```

	**Parameters:**

	<table markdown>
	<tr markdown>
	<th>Field</th>
	<td markdown>`<Index>`</td>
	<td markdown>`<BaudRate>`</td>
	<td markdown>`<DataBit>`</td>
	<td markdown>`<Parity>`</td>
	<td markdown>`<StopBit>`</td>
	<td markdown>`<FlowCtrl>`</td>
	</tr>
	<tr markdown>
	<th>Description</th>
	<td markdown>
	**UART Interface**
	<ul markdown>
	<li markdown>`1` = UART1</li>
	<li markdown>`2` = UART2</li>
	<li markdown>`3` = UART3</li>
	</ul>
	</td>
	<td markdown>
	**Baud Rate** (bps)
	<ul markdown>
	<li markdown>`9600`</li>
	<li markdown>`115200`</li>
	<li markdown>`230400`</li>
	<li markdown>==`460800`==</li>
	<li markdown>`921600`</li>
	</ul>
	</td>
	<td markdown>
	**Number of Data Bits**
	<ul markdown>
	<li markdown>==`8` = 8 bits==</li>
	</ul>
	</td>
	<td markdown>
	**Parity**
	<ul markdown>
	<li markdown>==`0` = No parity==</li>
	<li markdown>`1` = Odd parity</li>
	<li markdown>`2` = Even parity</li>
	<li markdown>`3` = Mark</li>
	<li markdown>`4` = Space</li>
	</ul>
	</td>
	<td markdown>
	**Number of Stop Bit**(s)
	<ul markdown>
	<li markdown>==`1` = 1 stop bit==</li>
	<li markdown>`2` = 2 stop bits</li>
	</ul>
	</td>
	<td markdown>
	**Flow Control**
	<ul markdown>
	<li markdown>==`0` = None==</li>
	</ul>
	</td>
	</tr>
	</table>

	???+ tip "Baud Rate"
		For ports utilized in conjunction with either the BlueSMiRF or radio transceivers, we recommend reducing the baud rate to 115200bps or lower to avoid overflowing the buffers of the transceiver's serial port.

	??? example "Configure the Settings"
		!!! abstract inline end "Example Settings"

			- Port: `UART1`
			- Baud Rate: 115200bps
			- Data Bits: 8
			- Parity: No
			- Stop Bits: 1
			- Flow Control: None

		Configure the baud rate of the current UART interface to 115200bps:
		```
		$PQTMCFGUART,W,115200*18
		```

		Configure the baud rate of `UART1` to 115200bps:
		```
		$PQTMCFGUART,W,1,115200*05
		```

		Configure all parameters of the current UART interface:
		```
		$PQTMCFGUART,W,115200,8,0,1,0*11
		```

		Configure all parameters of `UART1`:
		```
		$PQTMCFGUART,W,1,115200,8,0,1,0*0C
		```

		If there are no errors, users will receive the following response:
		```
		$PQTMCFGUART,OK*60
		```

	??? example "Retrieve the Settings"
		!!! abstract inline end "Example Settings"

			- Port: `UART1`
			- Baud Rate: 115200bps
			- Data Bits: 8
			- Parity: No
			- Stop Bits: 1
			- Flow Control: None

		Get the configuration on the current UART interface:
		```
		$PQTMCFGUART,R*36
		```

		Get the configuration on UART1:
		```
		$PQTMCFGUART,R,1*2B
		```

		If there are no errors, users will receive the following response:
		```
		$PQTMCFGUART,OK,1,115200,8,0,1,0*5F
		```

#### `PQTMCFGPROT`
:   Configures the input/output protocol on a specified port

	```
	$PQTMCFGPROT,W,<PortType>,<PortID>,<InputProt>,<OutputProt>*<Checksum><CR><LF>
	```

	**Parameters:**

	<table markdown>
	<tr markdown>
	<th>Field</th>
	<td markdown>`<PortType>`</td>
	<td markdown>`<PortID>`</td>
	<td markdown>`<InputProt>`</td>
	<td markdown>`<OutputProt>`</td>
	</tr>
	<tr markdown>
	<th>Description</th>
	<td markdown>
	**Port Type**
	<ul markdown>
	<li markdown>==`1` = UART==</li>
	</ul>
	</td>
	<td markdown>
	**Port ID**
	<ul markdown>
	<li markdown>`1` = UART1</li>
	<li markdown>`2` = UART2</li>
	<li markdown>`3` = UART3</li>
	</ul>
	</td>
	<td colspan="2" markdown>
	**Input/Output Protocols** (`HEX`: 32-bit)
	<ul markdown>
	<li markdown>==Bit `0` = NMEA==</li>
	<li markdown>==Bit `2` = RTCM3==</li>
	</ul>
	The **default** protocols are NMEA and RTCM3:<br>
	==**HEX:** `00000005`==<br>
	**BIN:** `0000 0000 0000 0000 0000 0000 0000 0101`
	</td>
	</tr>
	</table>

	??? example "Configure the Settings"
		!!! abstract inline end "Example Settings"

			- Port: `UART1`
			- Input Protocol: NMEA & RTCM3
			- Input Protocol: NMEA & RTCM3

		Configure the configuration on UART1:
		```
		$PQTMCFGPROT,W,1,1,00000005,00000005*38
		```

		If there are no errors, users will receive the following response:
		```
		$PQTMCFGPROT,OK*6B
		```

	??? example "Retrieve the Settings"
		!!! abstract inline end "Example Settings"

			- Port: `UART1`
			- Input Protocol: NMEA & RTCM3
			- Input Protocol: NMEA & RTCM3

		Get the configuration on UART1:
		```
		$PQTMCFGPROT,R,1,1*3D
		```

		If there are no errors, users will receive the following response:
		```
		$PQTMCFGPROT,OK,1,1,00000005,00000005*6B
		```

## RTK Settings

#### `PQTMCFGSVIN`
:   Configures a base station's position either by **survey-in** mode or **fixed** mode

	```
	$PQTMCFGSVIN,W,<Mode>,<CFG_CNT>,<3D_AccLimit>,<ECEF_X>,<ECEF_Y>,<ECEF_Z>*<Checksum><CR><LF>
	```

	**Parameters:**

	<table markdown>
	<tr markdown>
	<th>Field</th>
	<td markdown>`<Mode>`</td>
	<td markdown>`<CFG_CNT>`</td>
	<td markdown>`<3D_AccLimit>`</td>
	<td markdown>`<ECEF_X>` `<ECEF_Y>` `<ECEF_Z>`</td>
	</tr>
	<tr markdown>
	<th>Description</th>
	<td markdown>
	**Receiver Mode**
	<ul markdown>
	<li markdown>==`0` = Disable==</li>
	<li markdown>`1` = Survey-in mode</li>
	<li markdown>`2` = Fixed mode<br>*(Position is configured in ECEF coordinates)*</li>
	</ul>
	</td>
	<td markdown>
	**Survey-in Mode**<br>
	Minimum positioning time *(seconds)*
	<ul markdown>
	<li markdown>Range: `0`-`86400`</li>
	<li markdown>==**Default:** `0`==</li>
	</ul>
	</td>
	<td markdown>
	**Survey-in Mode**<br>
	3D positioning accuracy *(meters)*
	<ul markdown>
	<li markdown>`0` = No limit</li>
	<li markdown>==**Default:** `0.0`==</li>
	</ul>
	</td>
	<td markdown>
	**Fixed Mode**<br>
	WGS84 ECEF X,Y,Z coordinates *(meters)*
	<ul markdown>
	<li markdown>==**Default:** `0.0000`==</li>
	</ul>
	</td>
	</tr>
	</table>

	???+ info "RTK Base Station Modes"
		In order to operate as a base station, the LG580P GNSS module requires an accurate position of its antenna. This can be either defined in [ECEF coordinates](https://en.wikipedia.org/wiki/Earth-centered%2C_Earth-fixed_coordinate_system) or acquired through a self-survey process.

		1. ==Survey-In Mode:== The base station's location is established based on a weighted mean of recent solutions of its position. The `<CFG_CNT>` and `<3D_AccLimit>` parameters define the shortest amount of time that the position gets surveyed and the maximum standard deviation of the estimated position.
		1. ==Fixed Mode:== The base station's position is provided in [ECEF coordinates](https://en.wikipedia.org/wiki/Earth-centered%2C_Earth-fixed_coordinate_system).
	
		!!! note
			Any error in the base station's location will translate directly into an error in the rover's position.

	??? example "Configure the Settings"
		!!! abstract inline end "Example Settings"

			- Mode: Survey-in mode
			- Survey Time: 3600 seconds
			- 3D Accuracy: 1.2m
			- ECEF Coordinates:
				- X: -2519265.0514m
				- Y: 4849534.9045m
				- Z: 3277834.6432m

		Configure the configuration on UART1:
		```
		$PQTMCFGSVIN,W,1,3600,1.2,-2519265.0514,4849534.9045,3277834.6432*01
		```

		If there are no errors, users will receive the following response:
		```
		$PQTMCFGSVIN,OK*70
		```

	??? example "Retrieve the Settings"
		!!! abstract inline end "Example Settings"

			- Mode: Survey-in mode
			- Survey Time: 3600 seconds
			- 3D Accuracy: 1.2m
			- ECEF Coordinates:
				- X: -2519265.0514m
				- Y: 4849534.9045m
				- Z: 3277834.6432m

		Get the configuration on UART1:
		```
		$PQTMCFGSVIN,R*26
		```

		If there are no errors, users will receive the following response:
		```
		$PQTMCFGSVIN,OK,1,3600,1.2,-2519265.0514,4849534.9045,3277834.6432*52
		```

#### `PQTMCFGRCVRMODE`
:   Configures the mode that the receiver is operating in

	```
	$PQTMCFGRCVRMODE,W,<Mode>*<Checksum><CR><LF>
	```

	**Parameters:**

	<table markdown>
	<tr markdown>
	<th>Field</th>
	<td markdown>`<Mode>`</td>
	</tr>
	<tr markdown>
	<th>Description</th>
	<td markdown>
	**Operation mode**
	<ul markdown>
	<li markdown>`0` = Unknown</li>
	<li markdown>
	**`1` = Rover**<br>
	When set to this mode, the receiver will restore to default NMEA message output state.
	</li>
	<li markdown>`2` = Base Station<br>
	When set to this mode, the receiver will automatically disable NMEA message output and enable RTCM `MSM4` and RTCMv3 `1005` message output.
	</li>
	</ul>
	</td>
	</tr>
	</table>

	!!! note
		After switching the module‘s working mode, save the configuration and then reset the module. Otherwise, it will continue to operate in the original mode.

	??? example "Configure the Settings"
		!!! abstract inline end "Example Settings"

			- Port ID: `UART1`
			- Input Protocol: NMEA & RTCM3
			- Input Protocol: NMEA & RTCM3

		Configure the configuration on UART1:
		```
		$PQTMCFGRCVRMODE,W,2*29
		```

		If there are no errors, users will receive the following response:
		```
		$PQTMCFGRCVRMODE,OK*64
		```

	??? example "Retrieve the Settings"
		!!! abstract inline end "Example Settings"

			- Port ID: `UART1`
			- Input Protocol: NMEA & RTCM3
			- Input Protocol: NMEA & RTCM3

		Get the configuration on UART1:
		```
		$PQTMCFGRCVRMODE,R*32
		```

		If there are no errors, users will receive the following response:
		```
		$PQTMCFGRCVRMODE,OK,2*7A
		```

#### `PQTMCFGRTK`
:   Configures the operation settings of the RTK mode

	```
	$PQTMCFGRTK,W,<DiffMode>,<RelMode>*<Checksum><CR><LF>
	```

	**Parameters:**

	<table markdown>
	<tr markdown>
	<th>Field</th>
	<td markdown>`<DiffMode>`</td>
	<td markdown>`<RelMode>`</td>
	</tr>
	<tr markdown>
	<th>Description</th>
	<td markdown>
	**Differential Mode**
	<ul markdown>
	<li markdown>`0` = Disable RTK/RTD feature *(Differential data is not used)*</li>
	<li markdown>**`1` = Auto mode**</li>
	<li markdown>`2` = RTD only mode *(Only pseudoranges is used)*</li>
	</ul>
	</td>
	<td markdown>
	**Absolute/Relative Mode**
	<ul markdown>
	<li markdown>**`1` = Absolute mode, ensure absolute position accuracy**</li>
	<li markdown>`2` = Relative mode, ensure relative position accuracy</li>
	</ul>
	This field only takes effect when `<DiffMode>` = `1` and the module enters the RTK only mode.
	</td>
	</tr>
	</table>

	??? example "Configure the Settings"
		!!! abstract inline end "Example Settings"

			- Port ID: `UART1`
			- Input Protocol: NMEA & RTCM3
			- Input Protocol: NMEA & RTCM3

		Configure the configuration on UART1:
		```
		$PQTMCFGRTK,W,1,1*6C
		```

		If there are no errors, users will receive the following response:
		```
		$PQTMCFGRTK,OK*3F
		```

	??? example "Retrieve the Settings"
		!!! abstract inline end "Example Settings"

			- Port ID: `UART1`
			- Input Protocol: NMEA & RTCM3
			- Input Protocol: NMEA & RTCM3

		Get the configuration on UART1:
		```
		$PQTMCFGRTK,R*69
		```

		If there are no errors, users will receive the following response:
		```
		$PQTMCFGRTK,OK,1,1*3F
		```

## Heading Settings

### `PQTMTAR`
:   Outputs the time and attitude. The attitude computation in this message is computed from the two-antenna system.

	```
	$PQTMTAR,<MsgVer>,<Time>,<Quality>,<Res>,<Length>,<Pitch>,<Roll>,<Heading>,<Acc_Pitch>,<Acc_Roll>,<Acc_Heading>,<UsedSV>*<Checksum><CR><LF>
	```

	**Parameters:**

	<table markdown>
	<tr markdown>
	<th>Field</th>
	<th>Description</th>
	</tr>
	<tr markdown>
	<td markdown>`<MsgVer>`</td>
	<td markdown>
	**Message version.**
	<ul markdown>
	<li markdown>`1` = Version 1 (Always `1` for this message version)</li>
	</ul>
	</td>
	</tr>
	<tr markdown>
	<td markdown>`<Time>`</td>
	<td markdown>
	**UTC Time** *(`hhmmss.ddd`)*
	<ul markdown>
	<li markdown>`hh` = Hours (24hr)</li>
	<li markdown>`mm` = Minutes</li>
	<li markdown>`ss` = Seconds</li>
	<li markdown>`ddd` = Milliseconds</li>
	</ul>
	</td>
	</tr>
	<tr markdown>
	<td markdown>`<Quality>`</td>
	<td markdown>
	**GPS Heading Quality**
	<ul markdown>
	<li markdown>`0` = Fix not available or invalid</li>
	<li markdown>`1` = GPS SPS Mode, fix valid</li>
	<li markdown>`2` = Differential GPS, SPS Mode, or Satellite Based Augmentation System (SBAS), fix valid</li>
	<li markdown>`3` = GPS PPS Mode, fix valid</li>
	<li markdown>`4` = Fix Heading. System used in RTK mode with fixed integers</li>
	<li markdown>`5` = Float Heading. Satellite system used in RTK mode, floating integers</li>
	</ul>
	</td>
	</tr>
	<tr markdown>
	<td markdown>`<Res>`</td>
	<td markdown>
	**Reserved**
	</td>
	</tr>
	<tr markdown>
	<td markdown>`<Length>`</td>
	<td markdown>
	**Baseline Length** *(meters)*
	</td>
	</tr>
	<tr markdown>
	<td markdown>`<Pitch>`</td>
	<td markdown>
	**Pitch Angle** *(degrees)*
	<ul markdown>
	<li markdown>Range: `-90.000000`-`90.000000`</li>
	</ul>
	</td>
	</tr>
	<tr markdown>
	<td markdown>`<Roll>`</td>
	<td markdown>
	**Roll Angle** *(degrees)*
	<ul markdown>
	<li markdown>Range: `-180.000000`-`180.000000`</li>
	</ul>
	</td>
	</tr>
	<tr markdown>
	<td markdown>`<Heading>`</td>
	<td markdown>
	**Heading** *(degrees)*
	<ul markdown>
	<li markdown>Range: `0.000000`-`360.000000`</li>
	</ul>
	</td>
	</tr>
	<tr markdown>
	<td markdown>`<Acc_Pitch>`</td>
	<td markdown>
	**Pitch Accuracy** *(degrees)*
	</td>
	</tr>
	<tr markdown>
	<td markdown>`<Acc_Roll>`</td>
	<td markdown>
	**Roll Accuracy** *(degrees)*
	</td>
	</tr>
	<tr markdown>
	<td markdown>`<Acc_Heading>`</td>
	<td markdown>
	**Heading Accuracy** *(degrees)*
	</td>
	</tr>
	<tr markdown>
	<td markdown>`<UsedSV>`</td>
	<td markdown>
	**Satellites**<br>
	Number used for heading solution
	</td>
	</tr>
	</table>

	!!! info
		- Only the LG580P supports this message
		- More information for the direction of `<Heading>` in the `$PQTMTAR` message, please refer to the [dual-antenna heading application note](./assets/component_documentation/quectel_lg580p_series_dual-antenna_heading_application_note_v1-0.pdf)

	??? example "Parsed Message"
		```
		$PQTMTAR,1,165034.000,4,,0.860,1.124780,1.254125,50.968541,0.254125,0.125485,0.012547,21*52

		```

		- Message Version: `1`
		- UTC Time: 16:50 34.000s
		- GPS Heading Quality: `4` - Fix Heading. System used in RTK mode with fixed integers
		- Baseline Length: 0.860m
		- Pitch Angle: 1.124780&deg;
		- Roll Angle: 1.254125&deg;
		- Heading: 50.968541&deg;
		- Pitch Accuracy: 0.254125&deg;
		- Roll Accuracy: 0.125485&deg;
		- Heading Accuracy: 0.012547&deg;
		- Satellites: `21`

### `PQTMCFGBLD`
:   Configures the baseline distance between the two antennas.

	```
	$PQTMCFGBLD,W,<Distance>*<Checksum><CR><LF>
	```

	**Parameters:**

	<table markdown>
	<tr markdown>
	<th>Field</th>
	<td markdown>`<Distance>`</td>
	</tr>
	<tr markdown>
	<th>Description</th>
	<td markdown>
	**Baseline Distance** *(meters)*
	<ul markdown>
	<li markdown>Range: `0.000`-`5.000`</li>
	<li markdown>==**Default:** `0.000`==</li>
	</ul>
	When the baseline distance is `0`, the baseline distance will calculate by software
	</td>
	</tr>
	</table>

	!!! info
		- Only the LG580P supports this message

	??? example "Configure the Settings"
		!!! abstract inline end "Example Settings"

			- Port ID: `UART1`
			- Input Protocol: NMEA & RTCM3
			- Input Protocol: NMEA & RTCM3

		Configure the configuration on UART1:
		```
		$PQTMCFGBLD,W,1.000*68
		```

		If there are no errors, users will receive the following response:
		```
		$PQTMCFGBLD,OK*38
		```

	??? example "Retrieve the Settings"
		!!! abstract inline end "Example Settings"

			- Port ID: `UART1`
			- Input Protocol: NMEA & RTCM3
			- Input Protocol: NMEA & RTCM3

		Get the configuration on UART1:
		```
		$PQTMCFGBLD,R*6E
		```

		If there are no errors, users will receive the following response:
		```
		$PQTMCFGBLD,OK,1.000*3B
		```

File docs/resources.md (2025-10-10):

## Product Resources

- :sfe: [Product Page](https://www.sparkfun.com/sparkfun-quadband-gnss-rtk-with-heading-breakout-lg580p-qwiic.html)
- :material-folder-cog: Design Files:
	- :fontawesome-solid-file-pdf: [Schematic](./assets/board_files/schematic.pdf)
	- :fontawesome-solid-file-pdf: [Board Dimensions](./assets/board_files/dimensions.pdf)
	- :material-folder-zip: [KiCad Files](./assets/board_files/kicad_files.zip)
	- :material-cube-outline: [STEP File](./assets/3d_model/cad_model.step)
- :fontawesome-solid-computer: [QGNSS Software *(v2.x)*](https://www.quectel.com/download/qgnss_v2-0_en/)
- Component Documentation
	- :fontawesome-solid-file-pdf: [Product Specifications](./assets/component_documentation/Quectel_LG580P03_GNSS_Module_Specification_V1.0.pdf)
	- :fontawesome-solid-file-pdf: [Protocol Specification](./assets/component_documentation/quectel_lg290p03lgx80p03_gnss_protocol_specification_v1-1.pdf)
	- :fontawesome-solid-file-pdf: [Hardware Design](./assets/component_documentation/quectel_lg580p03_hardware_design_v1-0.pdf)
	- :fontawesome-solid-file-pdf: [Firmware Upgrade Guide](./assets/component_documentation/quectel_lg290p03lgx80p03_firmware_upgrade_guide_v1-1.pdf)
	- :fontawesome-solid-file-pdf: [Application Note - RTK Corrections](./assets/component_documentation/quectel_lg290p03lgx80p03_rtk_application_note_v1-1.pdf)
	- :fontawesome-solid-file-pdf: [Application Note - Base Station](./assets/component_documentation/quectel_lg290p03lgx80p_series_base_station_mode_application_note_v1-1.pdf)
	- :fontawesome-solid-file-pdf: [Application Note - Heading](./assets/component_documentation/quectel_lg580p_series_dual-antenna_heading_application_note_v1-0.pdf)
	- :fontawesome-solid-file-pdf: [CH342 Datasheet](./assets/component_documentation/CH342%20Datasheet.pdf)
	- :fontawesome-solid-file-pdf: [RT9080 Datasheet](./assets/component_documentation/DS9080.pdf)
	- :fontawesome-solid-file-pdf: [JST-GH Connector Specifications](./assets/component_documentation/JST-GH_datasheet.pdf)
- :material-github: [Hardware Repository](https://github.com/sparkfun/SparkFun_GNSS_LG580P)

### :sfe: Additional Resources

- [Qwiic Information Page](https://www.sparkfun.com/qwiic)
- :material-account-supervisor: [SparkFun Technical Assistance](https://www.sparkfun.com/technical_assistance)

### 🏭&nbsp;Manufacturer's Resources
Quectel also provides great resources for the LG580P GNSS module:

- :material-web: [Product Webpage](https://www.quectel.com/product/gnss-lg580p-03/)
- :material-help-box: [Quectel Forum](https://forums.quectel.com/)
- :material-account-supervisor: [Technical Support](https://www.quectel.com/tech-support/)
- :material-cloud-download: [Download Zone](https://www.quectel.com/download-zone/?_sft_product_cat=gnss-modules-standalone)
- :material-newspaper-variant: [Resource Library](https://www.quectel.com/library?_sft_topic=gnss)

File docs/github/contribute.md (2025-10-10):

## Make an Augmentation!
Spot an improvement opportunity? Feel free to contribute to our open-source design and documentation. 

## :material-file-document-multiple:&nbsp;Improve our Documentation
All of this documentation can be modified by you! Please help us make it better.

- These pages are contained in the [`docs` folder](https://github.com/sparkfun/SparkFun_GNSS_LG580P/tree/main/docs) of the [SparkFun GNSS LG580P repository](https://github.com/sparkfun/SparkFun_GNSS_LG580P).

<!-- ### :material-source-pull:&nbsp;Submit a Correction -->
### Submit a Correction

1. With a GitHub account, [fork this repository](https://github.com/sparkfun/SparkFun_GNSS_LG580P/fork).
2. Add your corrections or improvements to the markdown file.
3. File a pull request with your changes, and enjoy making the ~~words~~ ~~worlds~~ world a better place.
	- Once received, the documentation specialist will automatically be notified.
	- We will review your suggested improvements to make sure they are correct and fit within our documentation standards.

## :material-cog:&nbsp;Improve our Hardware Design
All of our designs are open-source! Please help us make it better.

- Our board design files are contained in the `/Hardware` directories of the [SparkFun GNSS LG580P repository](https://github.com/sparkfun/SparkFun_GNSS_LG580P).

<!-- ### :material-source-pull:&nbsp;Submit a Design Enhancement -->
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

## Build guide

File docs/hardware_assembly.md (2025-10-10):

## USB Programming (`UART1`)
The USB connection can be utilized for serial communication and configuring the LG580P GNSS module. Users only need to connect their Quad-band GNSS RTK breakout board to a computer, using a USB-C cable.

<figure markdown>
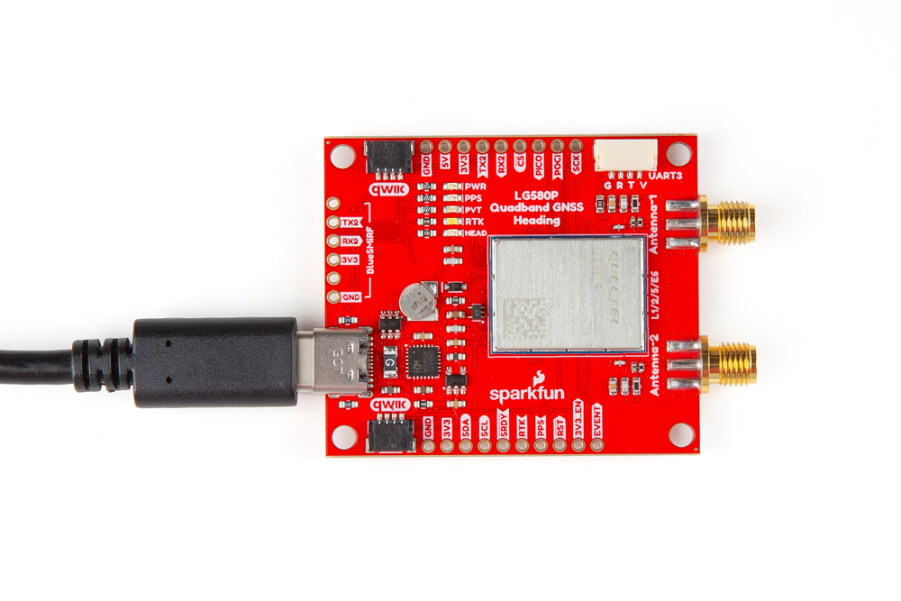
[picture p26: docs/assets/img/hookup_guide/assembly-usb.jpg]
Quad-band GNSS RTK breakout board USB connection

<figcaption markdown>The Quad-band GNSS RTK breakout board with USB-C cable being attached.</figcaption>
</figure>

## GNSS Antenna
In order to receive [GNSS](https://en.wikipedia.org/wiki/Satellite_navigation "Global Navigation Satellite System") signals, users will need to connect compatible antennas. For the best performance, we recommend users choose active, multi-band GNSS antennas and utilize a low-loss cables.

???+ warning "Antenna Specifications"
	- Passive antennas are not recommended for the LG580P GNSS module.
	- To mitigate the impact of out-of-band signals, utilize an active antenna whose SAW filter is placed in front of the LNA in the internal framework.
		- **DO NOT** select and antenna with the LNA placed in the front.
	- There is no need to inject an external DC voltage into the SMA connector for the GNSS antenna. Power is already provided from the LG580P module for the LNA of an active antenna.

!!! tip
	For the best performance, we recommend users choose compatible L1/L2/L5/L6/L-Band GNSS antennas and utilize a low-loss cables. Also, don't forget that GNSS signals are fairly weak and can't penetrate buildings or dense vegetation. The GNSS antennas should have an unobstructed view of the sky.

<div class="grid" markdown>

<div markdown>

### Primary Antenna
The `Antenna-1` SMA connector functions as the primary GNSS antenna connection for the LG580P GNSS receiver. The GNSS antenna on this connection will also function as the reference position for any heading computations.

<figure markdown>
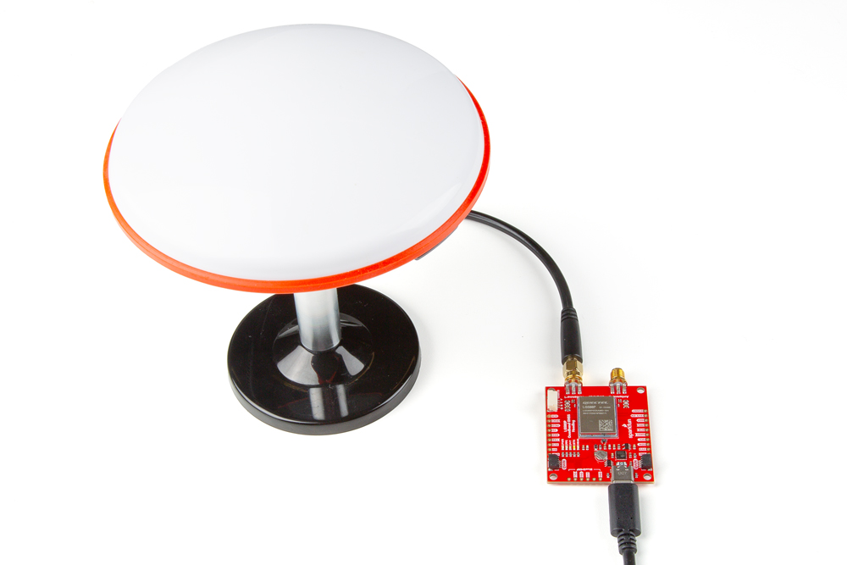
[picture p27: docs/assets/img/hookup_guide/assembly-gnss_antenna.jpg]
Quad-band GNSS RTK breakout board antenna connector

<figcaption markdown>A GNSS antenna attached to the SMA connector on the Quad-band GNSS RTK breakout board.</figcaption>
</figure>

</div>

<div markdown>

### Secondary Antenna
The `Antenna-2` SMA connector is only utilized for attitude determination by the LG580P GNSS receiver. With a minimum distance of 1m between the antennas and the base length setting configured, users should be able to achieve a heading accuracy of 0.1&deg;.

<figure markdown>
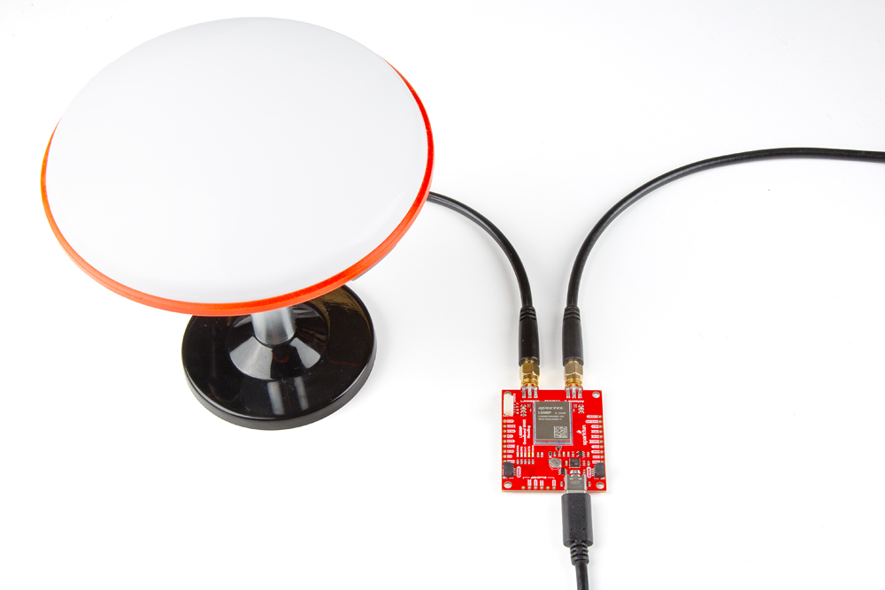
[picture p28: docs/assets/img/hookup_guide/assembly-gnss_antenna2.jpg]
Quad-band GNSS RTK breakout board antenna connector

<figcaption markdown>Two GNSS antennas attached to the SMA connectors on the Quad-band GNSS RTK breakout board.</figcaption>
</figure>

</div>

</div>

## JST Connector (`UART3`)
The JST connector on the Quad-band GNSS RTK board, breaks out the `UART3` port of the LG580P GNSS module. In certain circumstances, users may need to utilize the JST connector to transmit or receive RTK correction data with one of our radios.

<div class="grid" markdown>

<div markdown>

<figure markdown>
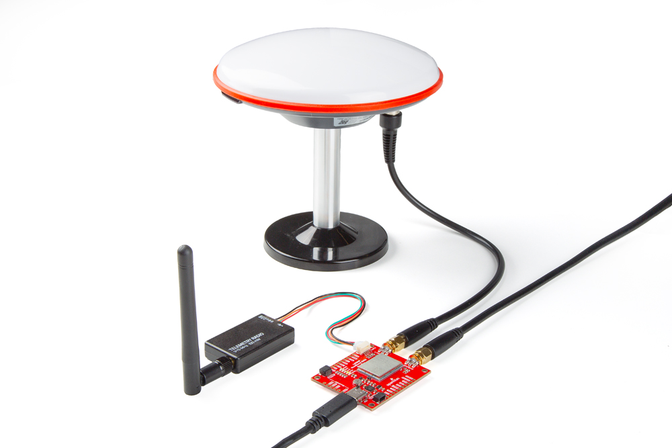
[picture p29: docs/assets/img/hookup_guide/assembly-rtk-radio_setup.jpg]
Device connected to the JST connector

<figcaption markdown>The [Telemetry Radio v3](https://www.sparkfun.com/sik-telemetry-radio-v3-915mhz-100mw.html) connected to the Quad-band GNSS RTK breakout.</figcaption>
</figure>

</div>

<div markdown>

When connecting the Quad-band GNSS RTK breakout board to other products, users should be aware of the pin connections between the devices. The table below, details the pin connections of the locking JST connector on the Quad-band GNSS RTK breakout board.

<article style="text-align: center;" markdown>

<table border="1" markdown>
<tr markdown>
<th style="vertical-align:middle;">Pin Number</th>
<td align="center" markdown>
	**1**<br>
	*(Left Side)*
</td>
<th align="center">2</td>
<th align="center">3</td>
<th align="center">4</td>
</tr>
<tr>
<th>Label</th>
<td align="center">VCC</td>
<td align="center">TX3</td>
<td align="center">RX3</td>
<td align="center">GND</td>
</tr>
<tr markdown>
<th style="vertical-align:middle;">Function</th>
<td markdown>
	<u>**Voltage Output**</u><br>
	- **Default: 3.3V**<br>
	- 3.3V or 5V
</td>
<td align="center" style="vertical-align:middle;" markdown>`UART3` - Receive</td>
<td align="center" style="vertical-align:middle;" markdown>`UART3` - Transmit</td>
<td align="center" style="vertical-align:middle;">Ground</td>
</tr>
</table>

</article>

</div>

</div>

### Radio Transceivers
We have designed the locking JST connector to be plug-n-play with the following devices and cables. However, for the [SiK Telemetry Radio v3](https://www.sparkfun.com/sik-telemetry-radio-v3-915mhz-100mw.html), users should [modify the `VSEL` jumper](../hardware_overview/#jumpers) (1) on the back of the board to enable a 5V output on the `VCC` pin. Below, is a table summarizing the pin connections of the radios.
{ .annotate }

1. While the [SiK Telemetry Radio v3](https://www.sparkfun.com/sik-telemetry-radio-v3-915mhz-100mw.html) may function with a **3.3V** input, their specifications stipulate that a **5V** power supply be provided.

<article style="text-align: center;" markdown>

<table border="1" markdown>
<tr markdown>
<th style="vertical-align:middle;">Pin Number</th>
<td align="center" markdown>
	**1**<br>
	*(Left Side)*
</td>
<td align="center" markdown>**2**</td>
<td align="center" markdown>**3**</td>
<td align="center" markdown>**4**</td>
<td align="center" markdown>**5**</td>
<td align="center" markdown>
	**6**<br>
	*(Right)*
</td>
</tr>
<tr>
<th style="vertical-align:middle;">Label</th>
<td align="center" style="vertical-align:middle;">5V</td>
<td>
	RX - SiK<br>
	RXI - LoRaSerial
</td>
<td>
	TX - SiK<br>
	TXO - LoRaSerial
</td>
<td align="center" style="vertical-align:middle;">CTS</td>
<td align="center" style="vertical-align:middle;">RTS</td>
<td align="center" style="vertical-align:middle;">GND</td>
</tr>
<tr markdown>
<th style="vertical-align:middle;">Function</th>
<td markdown>
	<u>**Voltage Input**</u><br>
	- SiK: 5V<br>
	- LoRaSerial: 3.3 to 5V
</td>
<td align="center" style="vertical-align:middle;">UART - Receive</td>
<td align="center" style="vertical-align:middle;">UART - Transmit</td>
<td align="center" style="vertical-align:middle;" markdown>
	Flow Control<br>
	*Clear-to-Send*
</td>
<td align="center" style="vertical-align:middle;" markdown>
	Flow Control<br>
	*Ready-to-Send*
</td>
<td align="center" style="vertical-align:middle;">Ground</td>
</tr>
</table>

</article>

??? tip "Radio Pin Connections"
	<div class="grid" markdown>

	<div markdown>

	As documented in the [LoRaSerial product manual](https://docs.sparkfun.com/SparkFun_LoRaSerial), the pin connections between a host system *(i.e. Quad-band GNSS RTK breakout board)* and the LoRaSerial radio is outlined in the image below.

	<figure markdown>
	UART w/ Flow Control (https://docs.sparkfun.com/SparkFun_LoRaSerial/img/SAMD21%20Flow%20control.png "Click to enlarge")
	<figcaption markdown>The pin connections between a radio and the Quad-band GNSS RTK breakout board.</figcaption>
	</figure>

	</div>

	<div markdown>

	However, the flow control pins *(`CTS` and `RTS`)* are not available on the Quad-band GNSS RTK breakout board. Therefore, when connecting either of the radios, the pin connections should follow the table below:

	<article style="text-align: center;" markdown>

	<table>
	<tr>
	<th>Board</th>
	<td align="center">RX</td>
	<td align="center">TX</td>
	<td align="center">GND</td>
	</tr>
	<tr>
	<th>Radio</th>
	<td align="center">TX</td>
	<td align="center">RX</td>
	<td align="center">GND</td>
	</tr>
	</table>

	</article>

	</div>

	</div>

???+ note "Radio Transceivers and Cables"
	!!! warning "Default Baud Rate"
		The baud rate for these radios are configured by the [`SERIAL_SPEED` parameter](https://docs.sparkfun.com/SparkFun_LoRaSerial/at_commands/#serial-commands). The default configuration is `SERIAL_SPEED`: **57600bps**.

	<div class="grid cards" markdown>

	-   <a href="https://www.sparkfun.com/sik-telemetry-radio-v3-915mhz-100mw.html">
		<figure markdown>
		Product Thumbnail
		</figure>

		---

		**SiK Telemetry Radio V3 - 915MHz, 100mW**<br>
		WRL-19032</a>

	-   <a href="https://www.sparkfun.com/sparkfun-loraserial-kit-915mhz-enclosed.html">
		<figure markdown>
		Product Thumbnail
		</figure>

		---

		**SparkFun LoRaSerial Kit - 915MHz (Enclosed)**<br>
		WRL-20029</a>

	-   <a href="https://www.sparkfun.com/jst-ghr-04v-to-jst-ghr-06v-cable-1-25mm-pitch.html">
		<figure markdown>
		Product Thumbnail
		</figure>

		---

		**JST-GHR-04V to JST-GHR-06V Cable - 1.25mm pitch**<br>
		CAB-17239</a>

	-   <a href="https://www.sparkfun.com/ghr-04v-s-to-ghr-06v-s-cable-100mm.html">
		<figure markdown>
		Product Thumbnail
		</figure>

		---

		**GHR-04V-S to GHR-06V-S Cable - 100mm**<br>
		CAB-17854</a>

	</div>

## Breakout Pins
The [PTH](https://en.wikipedia.org/wiki/Through-hole_technology "Plated Through Holes") pins on the Quad-band GNSS RTK board are broken out into 0.1"-spaced pins on the outer edges of the board.

??? note "New to soldering?"
	If you have never soldered before or need a quick refresher, check out our [How to Solder: Through-Hole Soldering](https://learn.sparkfun.com/tutorials/how-to-solder-through-hole-soldering) guide.

	<div class="grid cards" markdown align="center">

	-   <a href="https://learn.sparkfun.com/tutorials/5">
		<figure markdown>
		Tutorial thumbnail
		</figure>

		---
	
		**How to Solder: Through-Hole Soldering**</a>

	</div>

<div class="grid" markdown>

<div markdown>

**Headers**

---

When selecting headers, be sure you are aware of the functionality you require.

<figure markdown>
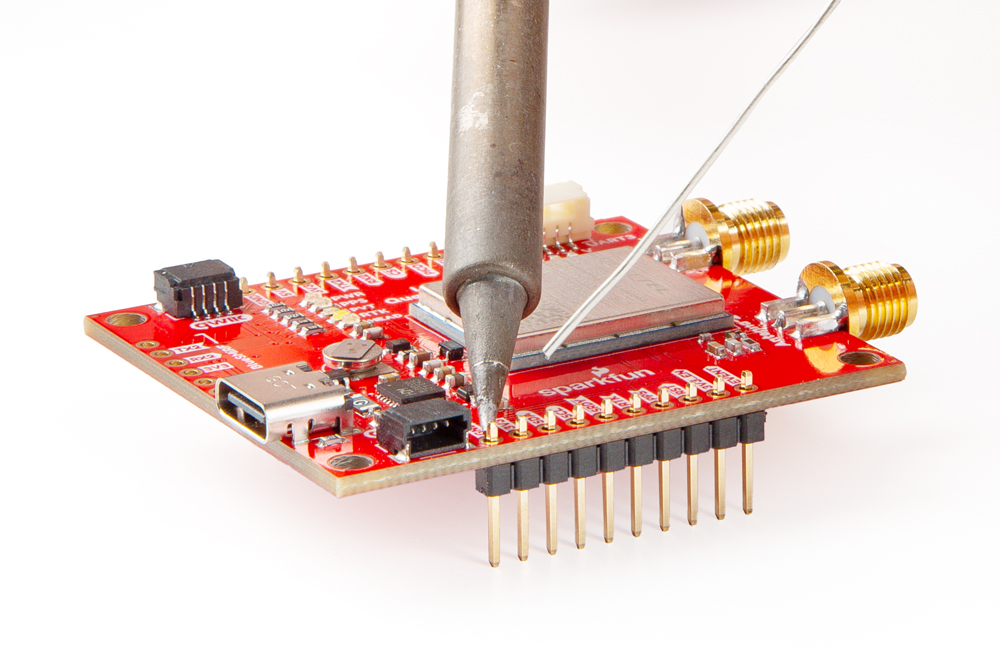
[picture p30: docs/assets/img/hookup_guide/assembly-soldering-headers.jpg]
Soldering headers

<figcaption markdown>Soldering headers to the Quad-band GNSS RTK breakout board.</figcaption>
</figure>

</div>

<div markdown>

**Hookup Wires**

---

For a more permanent connection, users can solder wires directly to the board.

<figure markdown>
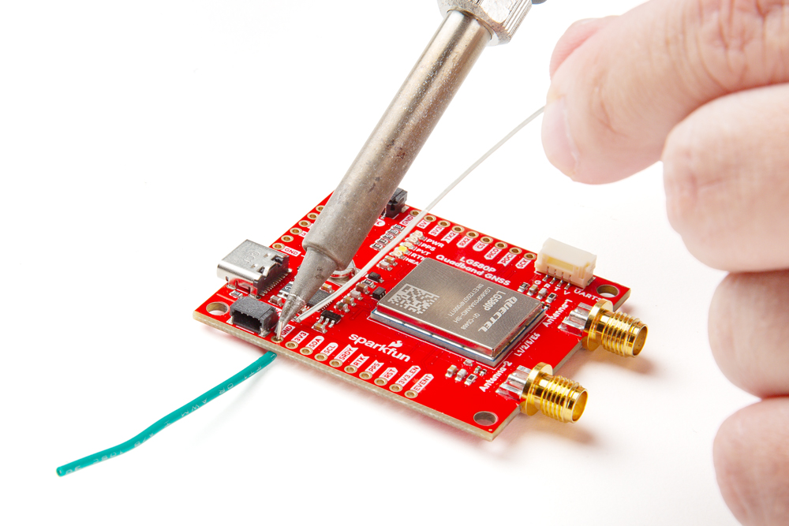
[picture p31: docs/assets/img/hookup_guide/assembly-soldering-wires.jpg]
Soldering wires

<figcaption markdown>Soldering wires to the Quad-band GNSS RTK breakout board.</figcaption>
</figure>

</div>

</div>

### BlueSMiRF Header (`UART2`)
The BlueSMiRF header pins on the Quad-band GNSS RTK board, breaks out the `UART2` port of the LG580P GNSS module. This pin layout is perfect for connecting a [serial-to-UART adapter](https://www.sparkfun.com/sparkfun-serial-basic-breakout-ch340c-and-usb-c.html) or a transceiver for serial data, such as the [BlueSMiRF Bluetooth&trade; serial-link](https://www.sparkfun.com/sparkfun-bluesmirf-v2-headers.html).

<div class="grid" markdown>

<div markdown>

<figure markdown>
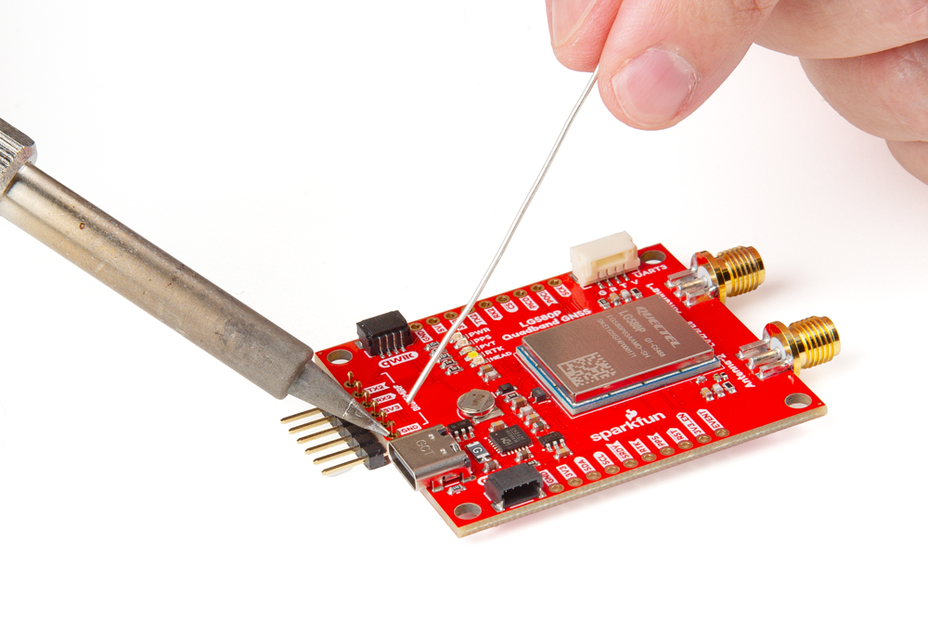
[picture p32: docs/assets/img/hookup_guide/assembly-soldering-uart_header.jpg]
Male Header Attached

<figcaption markdown>Soldering male header pins to the Quad-band GNSS RTK breakout board.</figcaption>
</figure>

</div>

<div markdown>

<figure markdown>
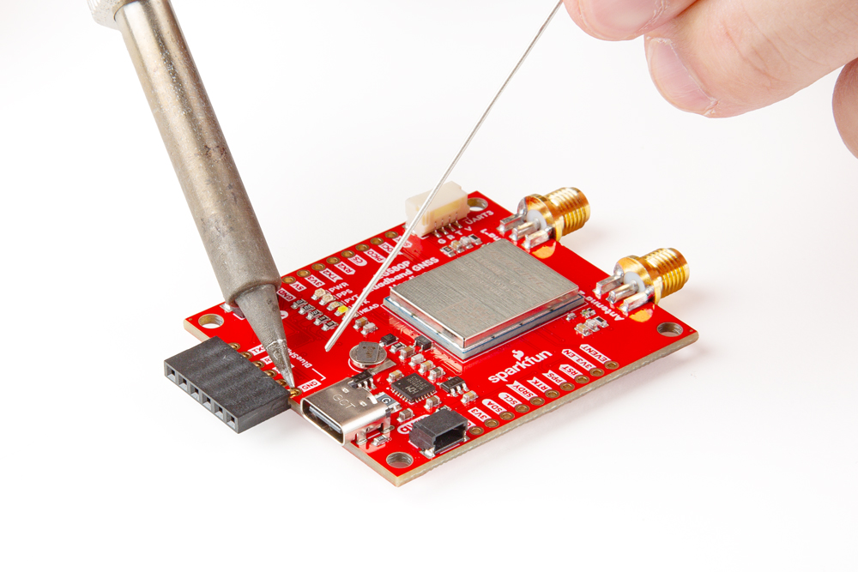
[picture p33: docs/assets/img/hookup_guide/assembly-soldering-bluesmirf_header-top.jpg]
Male Header Attached

<figcaption markdown>Soldering female header pins to the Quad-band GNSS RTK breakout board.</figcaption>
</figure>

</div>

<div markdown>

<figure markdown>
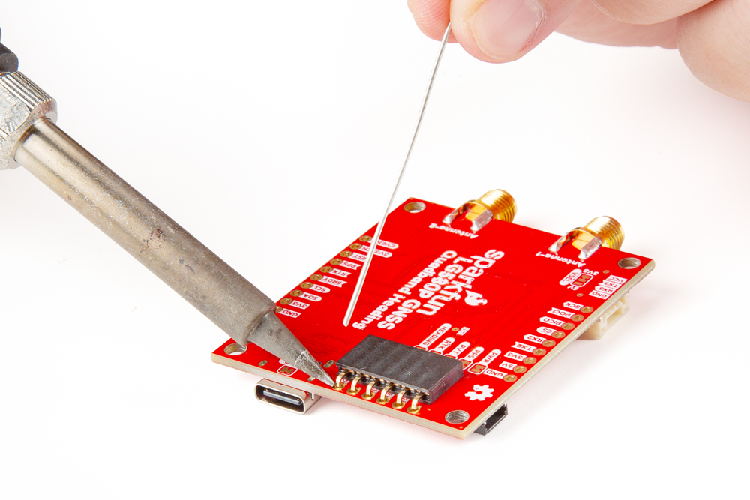
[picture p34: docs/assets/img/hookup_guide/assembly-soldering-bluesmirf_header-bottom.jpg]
Female Header Attached

<figcaption markdown>Soldering female header pins to the back of the Quad-band GNSS RTK breakout board.</figcaption>
</figure>

??? warning "Jumper Access"
	When soldering a header to the back of the board, be aware that you'll loose access to the jumper in that area.

	<figure markdown>
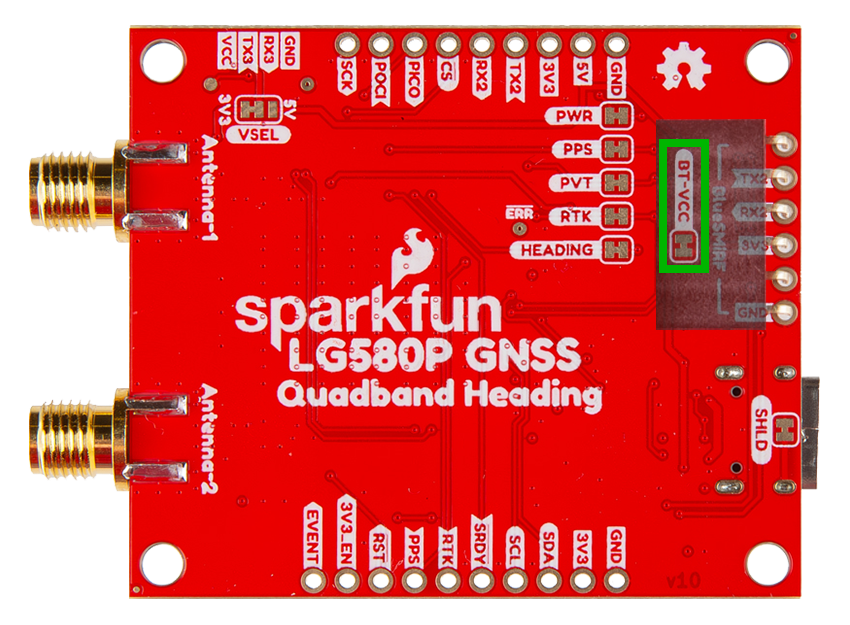
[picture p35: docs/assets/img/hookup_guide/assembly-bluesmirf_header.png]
BlueSMiRF transceiver - top
	
	<figcaption markdown>Female header covering the `BT-VCC` jumper.</figcaption>
	</figure>

</div>

</div>

=== "BlueSMiRF"
	!!! warning "Default Baud Rate"
		The baud rate for the BlueSMiRF transceiver is configured by the [`SerialSpeed` parameter](https://docs.sparkfun.com/SparkFun_BlueSMiRF-v2/at_commands/#serial-commands). The default configuration is `SerialSpeed`: **115200bps**.

	Connecting a [BlueSMiRF transceiver](https://www.sparkfun.com/sparkfun-bluesmirf-v2-headers.html) to a female header that was soldered to the Quad-band GNSS RTK breakout board. This will allow users to pair their board with a mobile device; and log PNT data on the mobile device and/or connect the LG580P to an NTRIP server for RTK corrections *(through mobile device's cellular or WiFi connection)*.

	<div class="grid" markdown>

	<div markdown>

	<figure markdown>
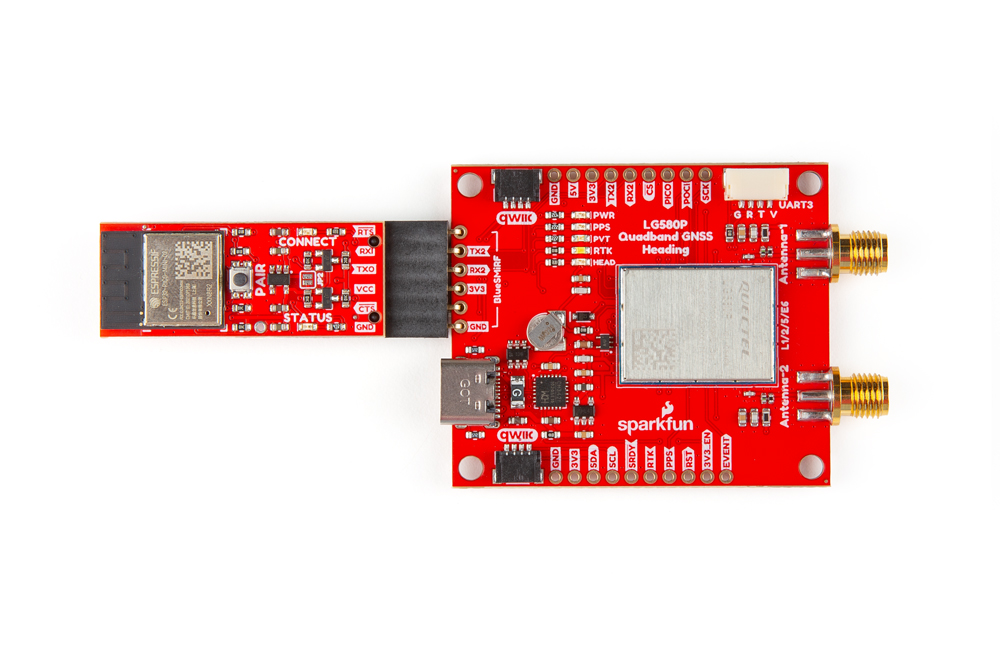
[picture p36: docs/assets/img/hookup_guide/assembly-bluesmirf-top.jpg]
BlueSMiRF transceiver - top
	
	<figcaption markdown>Female header pins soldered to the top of the board.</figcaption>
	</figure>

	</div>

	<div markdown>

	<figure markdown>
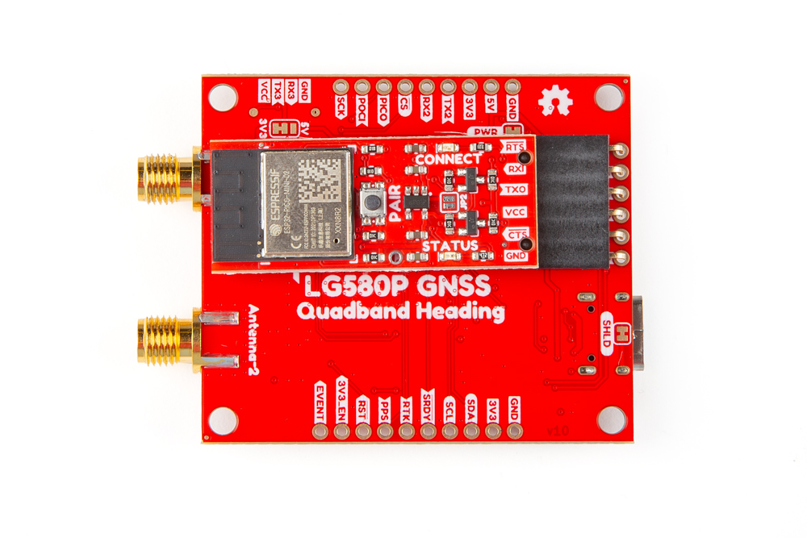
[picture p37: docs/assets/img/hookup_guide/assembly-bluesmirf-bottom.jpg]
BlueSMiRF transceiver - bottom
	
	<figcaption markdown>Female header pins soldered to the back of the board.</figcaption>
	</figure>

	</div>

	</div>

=== "UART Adapter"
	Connecting a UART adapter *([Serial Basic](https://www.sparkfun.com/sparkfun-serial-basic-breakout-ch340c-and-usb-c.html))* to a male header that was soldered to the Quad-band GNSS RTK breakout board. This will allow users to configure the LG580P, when the USB connection is unavailable.

	<figure markdown>
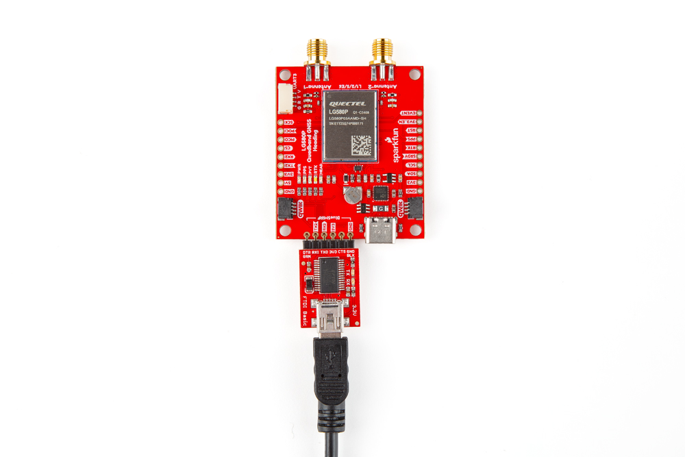
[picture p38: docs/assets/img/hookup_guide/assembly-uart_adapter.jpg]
Serial Basic
	
	<figcaption markdown>The adapter connected to the Quad-band GNSS RTK breakout board.</figcaption>
	</figure>

=== "OpenLog"
	!!! warning "Default Baud Rate"
		The baud rate for OpenLog needs to be configured in the `config.txt` file.

	Connecting an [OpenLog](https://www.sparkfun.com/sparkfun-openlog.html) to the Quad-band GNSS RTK breakout board. This will allow users to automatically log PNT data from the LG580P.

	<figure markdown>
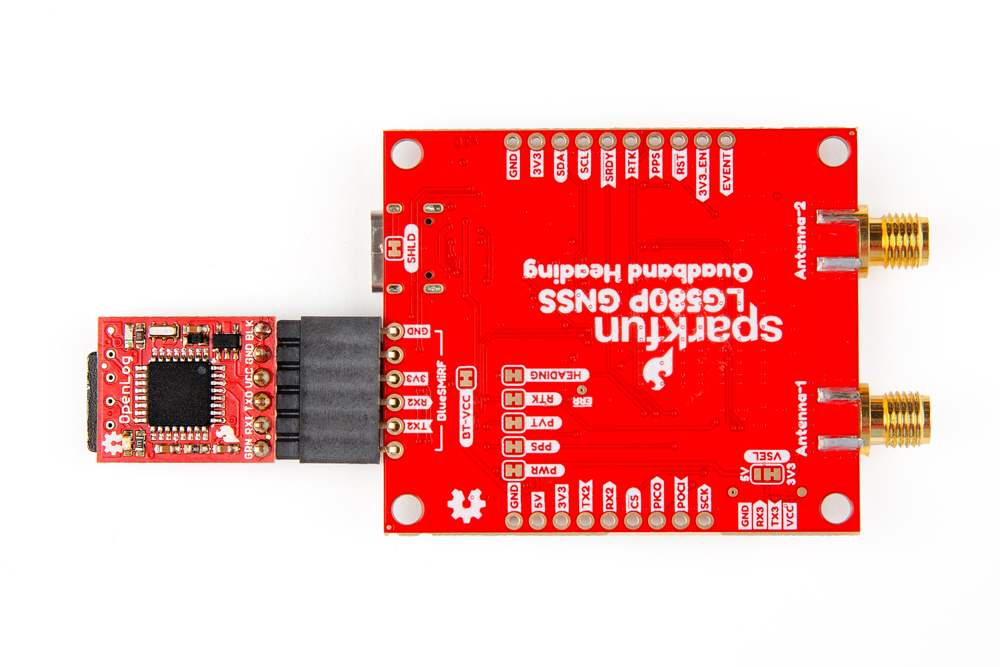
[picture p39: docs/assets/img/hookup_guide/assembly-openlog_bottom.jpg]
	
	<figcaption markdown>An [OpenLog](https://www.sparkfun.com/sparkfun-openlog.html) connected to the Quad-band GNSS RTK breakout board.</figcaption>
	</figure>

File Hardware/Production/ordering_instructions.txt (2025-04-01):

Ordering Instructions:
Panel dimensions: 179.29 x 144.24 mm.
Controlled Impedance: JLC04161H-7628
Material: TG155
Solder Mask: Red
Silkscreen Color: White
Layers: 4
Finish: ENIG
Thickness: 1.6mm
Outer Copper Weight: 1oz
Inner Copper Weight: 0.5oz
Minimum track width: 0.15mm (6.00mil)
Minimum via drill: 0.30mm (11.81mil)
No Clean Process

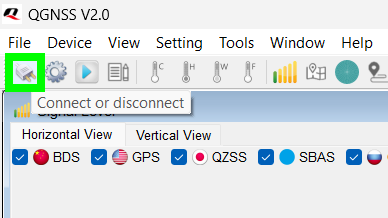
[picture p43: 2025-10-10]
docs/assets/img/hookup_guide/qgnss-connect_button.png

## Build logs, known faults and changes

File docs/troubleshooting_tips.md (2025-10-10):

---
icon: sfe
---

!!! warning "Need Help?"
	If you need technical assistance or more information on a product that is not working as you expected, we recommend heading over to the [SparkFun Technical Assistance](https://www.sparkfun.com/technical_assistance) page for some initial troubleshooting.

	<article style="text-align: center;" markdown>
	[SparkFun Technical Assistance Page](https://www.sparkfun.com/technical_assistance){ .md-button .md-button--primary }
	</article>

	If you can't find what you need there, the [SparkFun GNSS Forum](https://forum.sparkfun.com/viewforum.php?f=116) is a great place to ask questions.

	!!! info "Account Registration Required"
		If this is your first visit to our forum, you'll need to create a [Forum Account](https://forum.sparkfun.com/ucp.php?mode=register) to post questions.

<!-- QR Code for Hookup Guide (Displayed when printed) -->
<article style="text-align: center;" markdown>
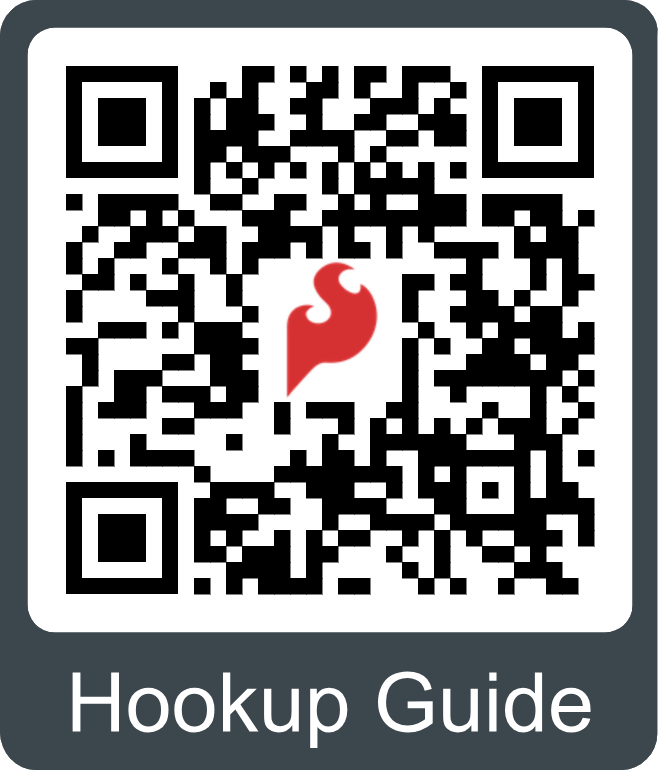
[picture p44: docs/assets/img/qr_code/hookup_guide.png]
QR code to the hookup guide

</article>

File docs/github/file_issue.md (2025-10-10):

## Need Assistance?

<!-- Technical Assistance Box -->
!!! warning "Need Help?"
	If you need technical assistance or more information on a product that is not working as you expected, we recommend heading on over to the [SparkFun Technical Assistance](https://www.sparkfun.com/technical_assistance) page for some initial troubleshooting. This **Submit Issues** page is not where users should seek assistance.

	<article style="text-align: center;" markdown>
	[SparkFun Technical Assistance Page](https://www.sparkfun.com/technical_assistance){ .md-button .md-button--primary }
	</article>

	If you can't find what you need there, the [SparkFun Forums](https://forum.sparkfun.com) is a great place to search the product forums and ask questions.

	!!! info "Account Registration Required"
		For your first visit to our forum, you'll need to create a [Forum Account](https://community.sparkfun.com/signup) to post questions.

## Did we make a mistake?
Spot something wrong? Please let us know. 

### Discrepancies in the Documentation
All of our documentation can be modified by you! Please help us make it better.

- The documentation files for these pages are contained in the [`docs` folder](https://github.com/sparkfun/SparkFun_GNSS_LG580P/tree/main/docs) of the [SparkFun GNSS LG580P repository](https://github.com/sparkfun/SparkFun_GNSS_LG580P).

#### 🔍 Spot something wrong?
If a section of the documentation is incorrect, please [open an issue](https://github.com/sparkfun/SparkFun_GNSS_LG580P/issues) and let us know.

#### Do you have a suggested correction?

1. With a GitHub account, [fork this repository](https://github.com/sparkfun/SparkFun_GNSS_LG580P/fork).
2. Add your correction(s) or improvement(s) to the markdown file(s)
3. File a pull request with your changes, and enjoy making the ~~words~~ ~~worlds~~ world a better place.
	- Once received, the documentation specialist will automatically be notified.
	- We will review your suggested improvement(s) to make sure they are correct and fit within our documentation standards.

### Problems in the Hardware Design
All of our designs are open-source! Please help us make it better.

- Our board design files are contained in the `/Hardware` directories of the [SparkFun GNSS LG580P repository](https://github.com/sparkfun/SparkFun_GNSS_LG580P).

#### Does something not make sense? 🤔
If part of the design is confusing, please [open an issue](https://github.com/sparkfun/SparkFun_GNSS_LG580P/issues) and let us know.

#### Did we forget to include an important function of the board? 🤦
If part of the board's functionality is missing, please [open an issue](https://github.com/sparkfun/SparkFun_GNSS_LG580P/issues) and file a feature request.

!!! tip "Design Considerations"
	Please keep in mind that we may intentionally exclude certain functions of the board to meet our product design requirements.

	- *For example, our Qwiic Micro boards are intended to fit on a small board layout and only use I^2^C communication; therefore, we may not have the SPI and interrupt pins available for users.*

#### Do you wish to contribute directly to improving the board design?

1. With a GitHub account, [fork this repository](https://github.com/sparkfun/SparkFun_GNSS_LG580P/fork).
2. Add your design augmentation(s)
3. File a pull request with your changes, and enjoy making the ~~words~~ ~~worlds~~ world a better place.
	1. Once received, the engineer in charge of the original design will automatically be notified.
	2. We will review your suggested improvement(s) to verify that they are within our board design standards and meet our product design requirements.
	3. If approved, we will flag these changes for our next board revision. Congrats! 🍻

		!!! info
			Even if your suggestion is accepted, these changes may not be immediately available for purchase. We may have to cycle through our current product inventory first.

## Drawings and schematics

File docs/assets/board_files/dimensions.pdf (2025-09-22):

45.7 mm
8.9 | mm | 5.1 | mm ⁸.9 mm

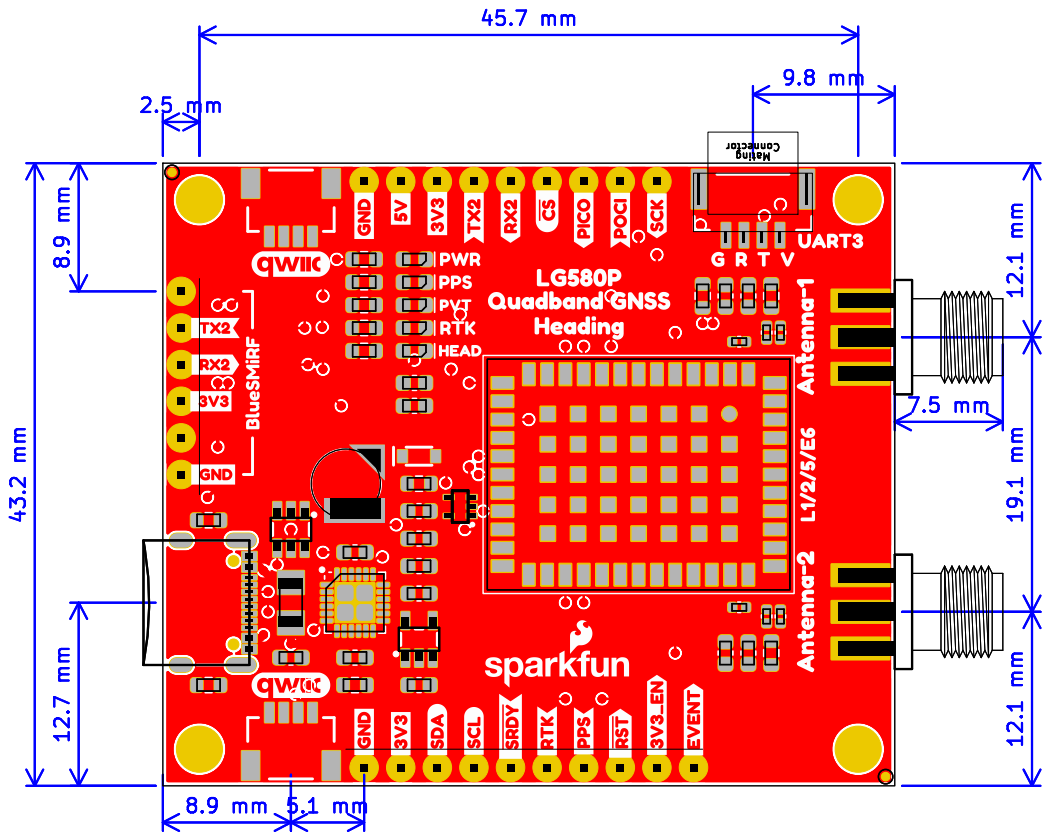
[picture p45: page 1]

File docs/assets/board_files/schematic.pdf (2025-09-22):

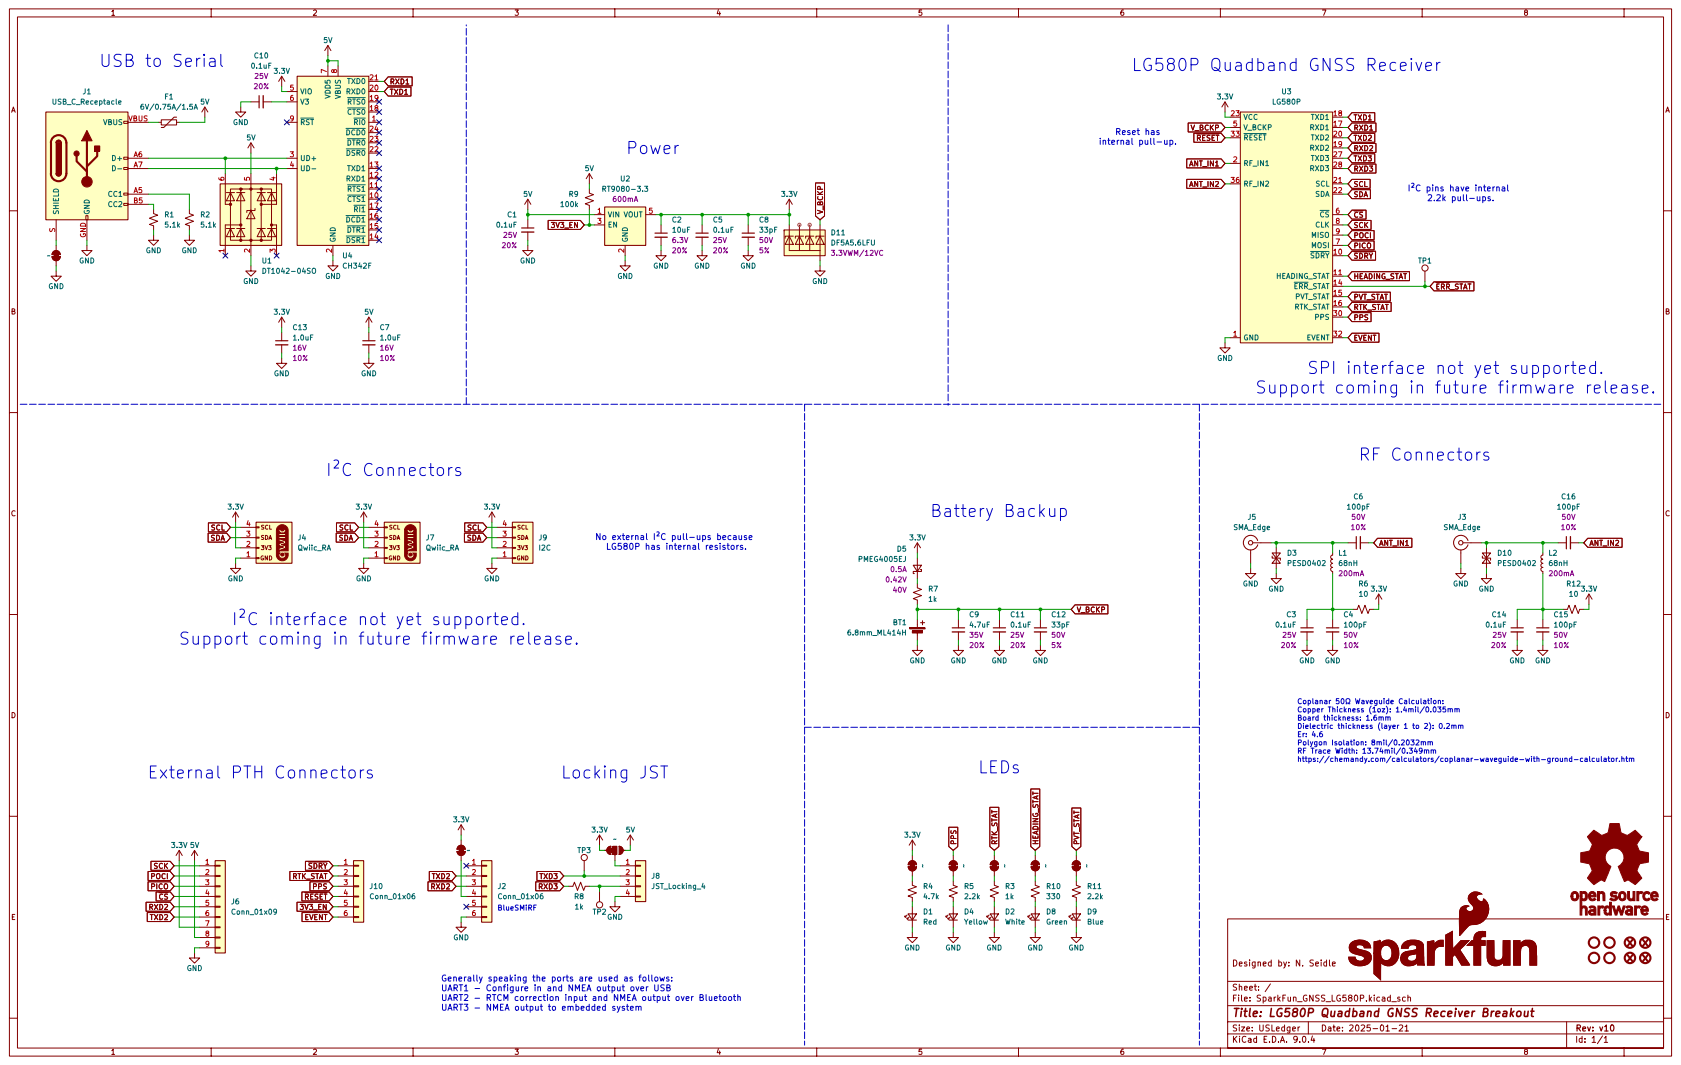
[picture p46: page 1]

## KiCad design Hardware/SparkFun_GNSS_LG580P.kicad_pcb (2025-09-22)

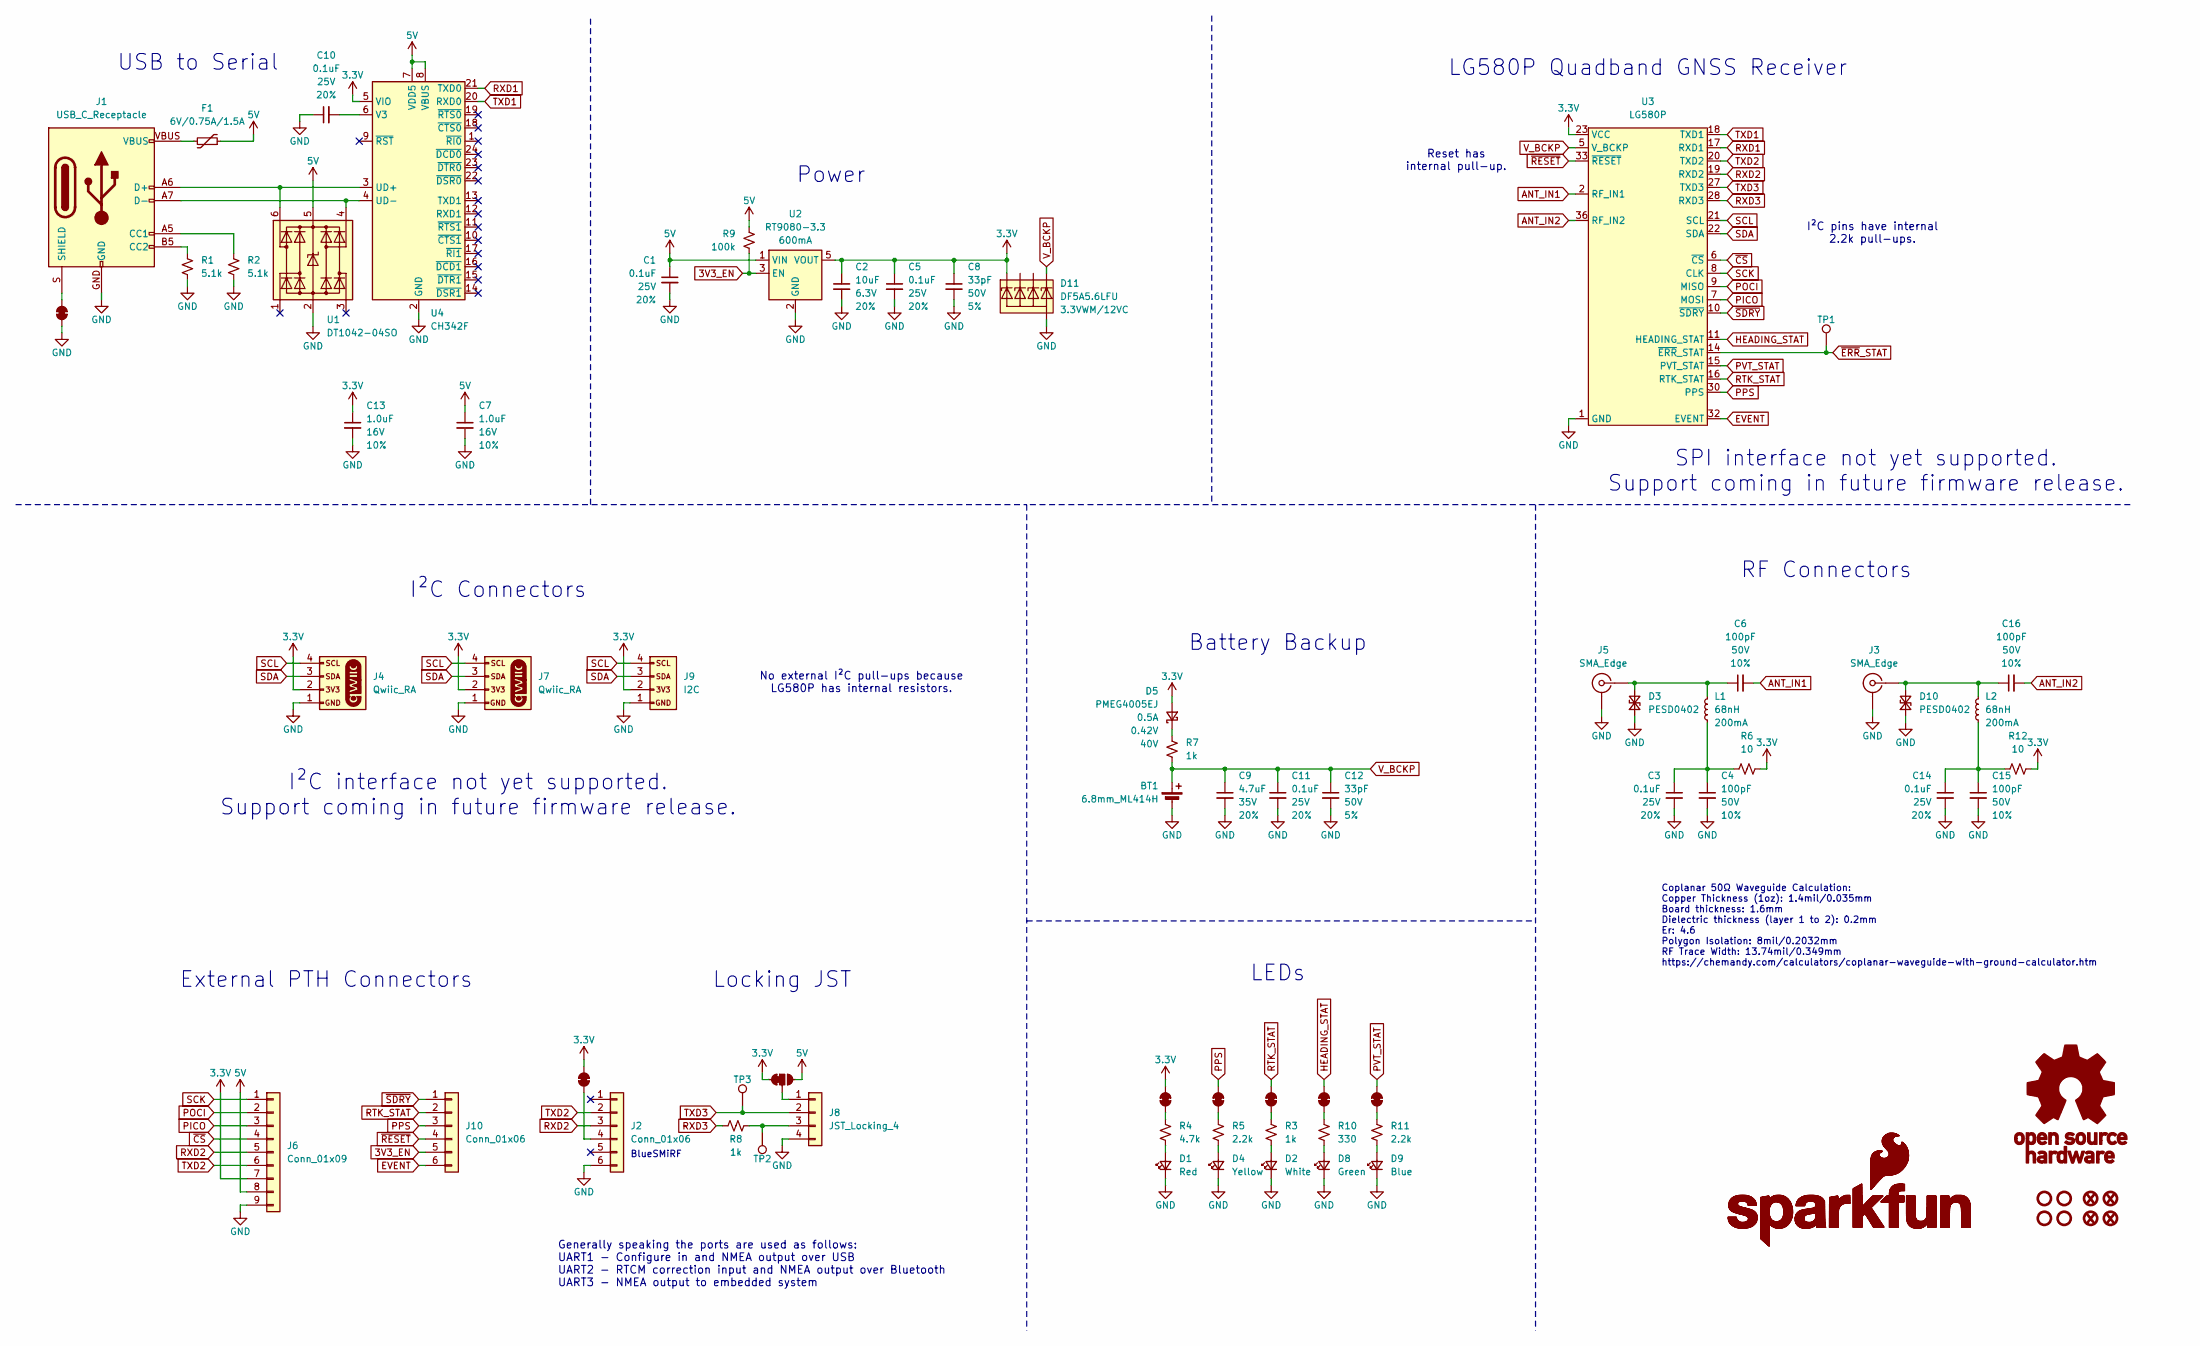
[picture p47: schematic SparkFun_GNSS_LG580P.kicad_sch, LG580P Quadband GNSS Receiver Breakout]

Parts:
BT1: 6.8mm_ML414H; ML414H_IV01E
C1, C3, C5, C10, C11, C14: 0.1uF; C_0603_1608Metric; Voltage 25V; Tolerance 20%
C2: 10uF; C_0603_1608Metric; Voltage 6.3V; Tolerance 20%
C4, C15: 100pF; C_0603_1608Metric; Voltage 50V; Tolerance 10%
C6, C16: 100pF; C_0402_1005Metric; Voltage 50V; Tolerance 10%
C7, C13: 1.0uF; C_0603_1608Metric; Voltage 16V; Tolerance 10%
C8, C12: 33pF; C_0603_1608Metric; Voltage 50V; Tolerance 5%
C9: 4.7uF; C_0603_1608Metric; Voltage 35V; Tolerance 20%
D1: Red; LED_0603_1608Metric_Red
D2: White; LED_0603_1608Metric_White
D3, D10: PESD0402; C_0402_1005Metric
D4: Yellow; LED_0603_1608Metric_Yellow
D5: PMEG4005EJ; SOD-323
D8: Green; LED_0603_1608Metric_Green
D9: Blue; LED_0603_1608Metric_Blue
D11: DF5A5.6LFU; SOT-353; Rating 3.3VWM/12VC
F1: 6V/0.75A/1.5A; 1206
FID1, FID2, FID3, FID4: Fiducial_0.5mm; Fiducial_0.5mm_Mask1mm
G1: OSHW_Logo; Creative_Commons_License
G3: SparkFun_Logo
G5: SparkFun_Logo; SparkFun_Logo_8mm
J1: USB_C_Receptacle; USB-C_16
J2, J10: Conn_01x06; 1x06
J3, J5: SMA_Edge
J4, J7: Qwiic_RA; JST_SMD_1.0mm-4_Black
J6: Conn_01x09; 1x09
J8: JST_Locking_4; JST_SMD_1.25mm-4_Locking
J9: I2C; 1x04
JP1, JP2, JP3, JP5, JP6, JP7, JP8: Jumper_2_NC_Trace
JP4: Jumper_3_NC-1_Trace
L1, L2: 68nH; C_0402_1005Metric
R1, R2: 5.1k; R_0603_1608Metric
R3, R7, R8: 1k; R_0603_1608Metric
R4: 4.7k; R_0603_1608Metric
R5, R11: 2.2k; R_0603_1608Metric
R6, R12: 10; R_0603_1608Metric
R9: 100k; R_0603_1608Metric
R10: 330; R_0603_1608Metric
ST1, ST2, ST3, ST4: Standoff
TP1, TP2, TP3: 1.0mm; TestPoint-1.0mm
U1: DT1042-04SO; SOT23-6
U2: RT9080-3.3; SOT23-5
U3: LG580P; Quectel_LG580P
U4: CH342F; QFN-24-1EP_4x4mm_P0.5mm_EP2.7x2.7mm

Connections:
3.3V: C2.1, C5.1, C8.1, C13.1, D5.2 (A), D11.1 (K1), J4.2, J6.7, J7.2, J9.2, JP1.2 (B), JP2.2 (B), JP4.1 (A), R6.2, R12.2, U2.5 (VOUT), U3.23 (VCC), U3.24 (VCC), U4.5 (VIO)
3V3_EN: J10.5, R9.1, U2.3 (EN)
5V: C1.1, C7.1, F1.1, J6.8, JP4.3 (C), R9.2, U1.5 (VCC), U2.1 (VIN), U4.7 (VDD5), U4.8 (VBUS)
ANT_IN1: C6.2, U3.2 (RF_IN1)
ANT_IN2: C16.2, U3.36 (RF_IN2)
EVENT: J10.6, U3.32 (EVENT)
GND: BT1.-, C1.2, C2.2, C3.2, C4.2, C5.2, C7.2, C8.2, C9.2, C10.1, C11.2, C12.2, C13.2, C14.2, C15.2, D1.1 (K), D2.1 (K), D3.1 (A1), D4.1 (K), D8.1 (K), D9.1 (K), D10.1 (A1), D11.2 (A), J1.GND, J2.6, J3.2 (Ext), J4.1, J5.2 (Ext), J6.9, J7.1, J8.4, J9.1, JP7.1 (A), R1.1, R2.1, U1.2 (GND), U2.2 (GND), U3.1 (GND), U3.3 (GND), U3.4 (GND), U3.34 (GND), U3.35 (GND), U3.37 (GND), U3.41 (GND), U3.43 (GND), U3.45 (GND), U3.49 (GND), U4.2 (GND), U4.25 (GND)
HEADING_STAT: JP6.2 (B), U3.11 (HEADING_STAT)
unnamed: C3.1, C4.1, L1.1, R6.1
unnamed: C14.1, C15.1, L2.1, R12.1
unnamed: D1.2 (A), R4.1
unnamed: D2.2 (A), R3.1
unnamed: C6.1, D3.2 (A2), J5.1 (In), L1.2
unnamed: D4.2 (A), R5.1
unnamed: D5.1 (K), R7.2
unnamed: D8.2 (A), R10.1
unnamed: D9.2 (A), R11.1
unnamed: C16.1, D10.2 (A2), J3.1 (In), L2.2
unnamed: F1.2, J1.VBUS
unnamed: J1.A5 (CC1), R2.2
unnamed: J1.B5 (CC2), R1.2
unnamed: J1.S (SHIELD), JP7.2 (B)
unnamed: J2.4, JP1.1 (A)
unnamed: J8.1, JP4.2 (B)
unnamed: J8.3, R8.1, TP2.1
unnamed: JP2.1 (A), R4.2
unnamed: JP3.1 (A), R5.2
unnamed: JP5.1 (A), R3.2
unnamed: JP6.1 (A), R10.2
unnamed: JP8.1 (A), R11.2
unnamed: J1.A7 (D-), J1.B7 (D-), U1.4 (I/O3), U4.4 (UD-)
unnamed: J1.A6 (D+), J1.B6 (D+), U1.6 (I/O4), U4.3 (UD+)
unnamed: C10.2, U4.6 (V3)
PICO: J6.3, U3.7 (MOSI)
POCI: J6.2, U3.9 (MISO)
PPS: J10.3, JP3.2 (B), U3.30 (PPS)
PVT_STAT: JP8.2 (B), U3.15 (PVT_STAT)
RTK_STAT: J10.2, JP5.2 (B), U3.16 (RTK_STAT)
RXD1: U3.17 (RXD1), U4.21 (TXD0)
RXD2: J2.3, J6.5, U3.19 (RXD2)
RXD3: R8.2, U3.28 (RXD3)
SCK: J6.1, U3.8 (CLK)
SCL: J4.4, J7.4, J9.4, U3.21 (SCL)
SDA: J4.3, J7.3, J9.3, U3.22 (SDA)
TXD1: U3.18 (TXD1), U4.20 (RXD0)
TXD2: J2.2, J6.6, U3.20 (TXD2)
TXD3: J8.2, TP3.1, U3.27 (TXD3)
V_BCKP: BT1.+, C9.1, C11.1, C12.1, D11.5 (K4), R7.1, U3.5 (V_BCKP)
~CS: J6.4, U3.6 (~CS)
~ERR_STAT: TP1.1, U3.14 (~ERR_STAT)
~RESET: J10.4, U3.33 (~RESET)
~SDRY: J10.1, U3.10 (~SDRY)

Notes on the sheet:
I²C Connectors
Generally speaking the ports are used as follows: UART1 - Configure in and NMEA output over USB UART2 - RTCM correction input and NMEA output over Bluetooth UART3 - NMEA output to embedded system
Reset has internal pull-up.
I²C interface not yet supported. Support coming in future firmware release.
Coplanar 50Ω Waveguide Calculation: Copper Thickness (1oz): 1.4mil/0.035mm Board thickness: 1.6mm Dielectric thickness (layer 1 to 2): 0.2mm Er: 4.6 Polygon Isolation: 8mil/0.2032mm RF Trace Width: 13.74mil/0.349mm https://chemandy.com/calculators/coplanar-waveguide-with-ground-calculator.htm
I²C pins have internal 2.2k pull-ups.
Locking JST
BlueSMiRF
Power
RF Connectors
LEDs
LG580P Quadband GNSS Receiver
USB to Serial
Battery Backup
SPI interface not yet supported. Support coming in future firmware release.
External PTH Connectors
No external I²C pull-ups because LG580P has internal resistors.

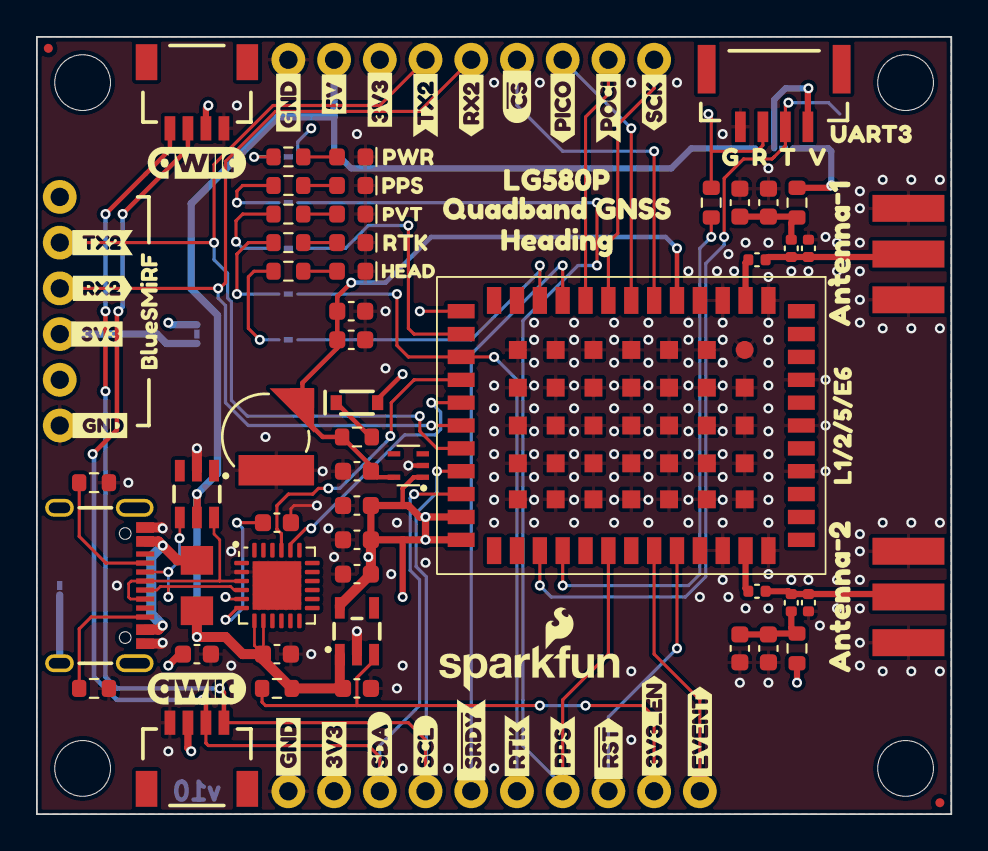
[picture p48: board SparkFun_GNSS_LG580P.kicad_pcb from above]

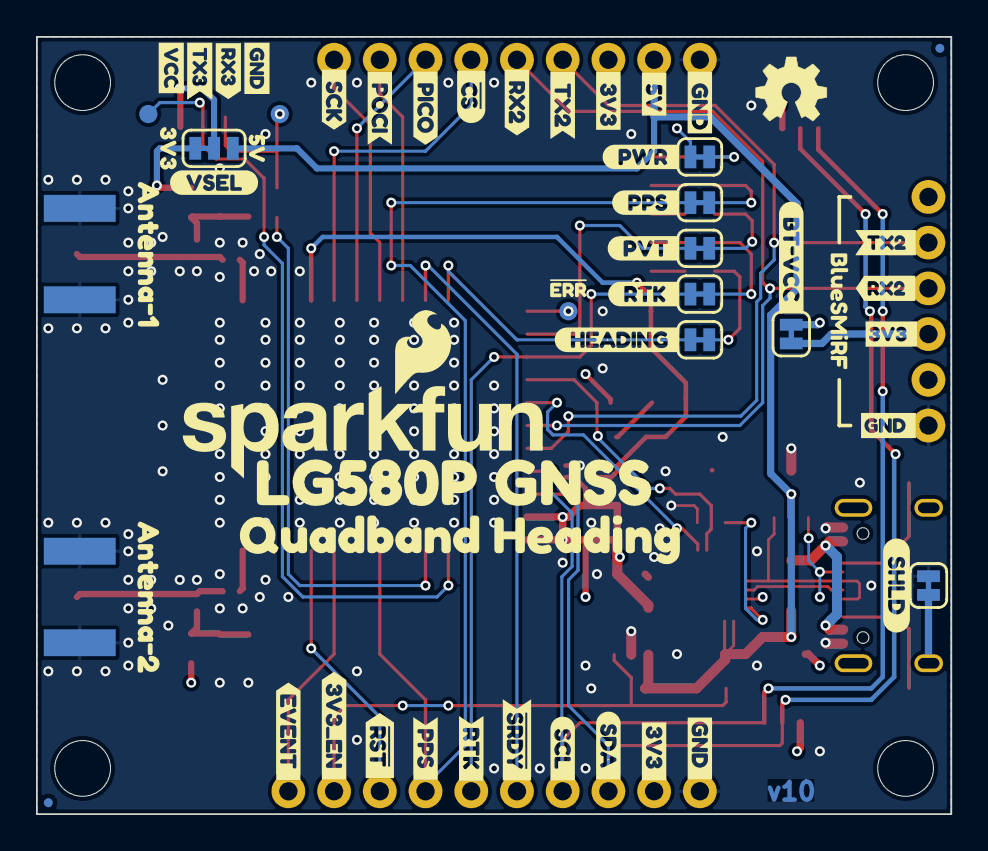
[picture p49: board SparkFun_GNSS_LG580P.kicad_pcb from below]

Board: 4 copper layers, 50.8 x 43.2 mm, 156 parts (57 on the bottom side), 52 nets.

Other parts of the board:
Ref**: Val**; OSHW_Logo_4mm
kibuzzard-64C2E6A3: G***; kibuzzard-64C2E6A3
kibuzzard-64C2E6BD: G***; kibuzzard-64C2E6BD
kibuzzard-64C2E6D6: G***; kibuzzard-64C2E6D6
kibuzzard-64C3DF93: G***; kibuzzard-64C3DF93
kibuzzard-66CAA7B2: G***; kibuzzard-66CAA7B2
kibuzzard-66CAA7D2: G***; kibuzzard-66CAA7D2
kibuzzard-66CAA41A: G***; kibuzzard-66CAA41A
kibuzzard-66CAA426: G***; kibuzzard-66CAA426
kibuzzard-66CAA432: G***; kibuzzard-66CAA432
kibuzzard-66CAA594: G***; kibuzzard-66CAA594
kibuzzard-66CB7E2C: G***; kibuzzard-66CB7E2C
kibuzzard-66CB37CC: G***; kibuzzard-66CB37CC
kibuzzard-66CB37D7: G***; kibuzzard-66CB37D7
kibuzzard-66CB82FB: G***; kibuzzard-66CB82FB
kibuzzard-66CB829C: G***; kibuzzard-66CB829C
kibuzzard-66CB830B: G***; kibuzzard-66CB830B
kibuzzard-67A3F35B: G***; kibuzzard-67A3F35B
kibuzzard-67A3F366: G***; kibuzzard-67A3F366
kibuzzard-67C8A377: G***; kibuzzard-67C8A377
kibuzzard-678FE5A2: G***; kibuzzard-678FE5A2
kibuzzard-678FE57D: G***; kibuzzard-678FE57D
kibuzzard-6501FDDA, kibuzzard-6501FDDA#2: G***; kibuzzard-6501FDDA
kibuzzard-6797CCC1: G***; kibuzzard-6797CCC1
kibuzzard-6797CCD8: G***; kibuzzard-6797CCD8
kibuzzard-6797CCDC: G***; kibuzzard-6797CCDC
kibuzzard-6797CD7B: G***; kibuzzard-6797CD7B
kibuzzard-6797CDD0: G***; kibuzzard-6797CDD0
kibuzzard-6797CDE7: G***; kibuzzard-6797CDE7
kibuzzard-6797CDED: G***; kibuzzard-6797CDED
kibuzzard-6797CE3B: G***; kibuzzard-6797CE3B
kibuzzard-6797CE3F: G***; kibuzzard-6797CE3F
kibuzzard-6797CE4B: G***; kibuzzard-6797CE4B
kibuzzard-6797CE44: G***; kibuzzard-6797CE44
kibuzzard-6797CE48: G***; kibuzzard-6797CE48
kibuzzard-6797CEC8, kibuzzard-6797CEC8#2: G***; kibuzzard-6797CEC8
kibuzzard-6797CECC, kibuzzard-6797CECC#2: G***; kibuzzard-6797CECC
kibuzzard-6797CF40: G***; kibuzzard-6797CF40
kibuzzard-6797CFAD: G***; kibuzzard-6797CFAD
kibuzzard-6797CFB3: G***; kibuzzard-6797CFB3
kibuzzard-6797CFD5: G***; kibuzzard-6797CFD5
kibuzzard-6797CFD9: G***; kibuzzard-6797CFD9
kibuzzard-6797CFEB: G***; kibuzzard-6797CFEB
kibuzzard-6797D0AD: G***; kibuzzard-6797D0AD
kibuzzard-6797D0B2: G***; kibuzzard-6797D0B2
kibuzzard-6797D0B5: G***; kibuzzard-6797D0B5
kibuzzard-6797D0B9: G***; kibuzzard-6797D0B9
kibuzzard-6797D0BE: G***; kibuzzard-6797D0BE
kibuzzard-6797D1E0: G***; kibuzzard-6797D1E0
kibuzzard-6797D1F5: G***; kibuzzard-6797D1F5
kibuzzard-6797D2D0: G***; kibuzzard-6797D2D0
kibuzzard-6797D02E: G***; kibuzzard-6797D02E
kibuzzard-6797D04A: G***; kibuzzard-6797D04A
kibuzzard-6797D04F: G***; kibuzzard-6797D04F
kibuzzard-6797D06C: G***; kibuzzard-6797D06C
kibuzzard-6797D07B: G***; kibuzzard-6797D07B
kibuzzard-6797D08B: G***; kibuzzard-6797D08B
kibuzzard-6797D08F: G***; kibuzzard-6797D08F
kibuzzard-6797D021: G***; kibuzzard-6797D021
kibuzzard-6797D21D: G***; kibuzzard-6797D21D
kibuzzard-6797D23B: G***; kibuzzard-6797D23B
kibuzzard-6797D24B: G***; kibuzzard-6797D24B
kibuzzard-6797D025: G***; kibuzzard-6797D025
kibuzzard-6797D029: G***; kibuzzard-6797D029
kibuzzard-6797D30B: G***; kibuzzard-6797D30B
kibuzzard-6797D054: G***; kibuzzard-6797D054
kibuzzard-6797D058: G***; kibuzzard-6797D058
kibuzzard-6797D071: G***; kibuzzard-6797D071
kibuzzard-6797D081: G***; kibuzzard-6797D081
kibuzzard-6797D086: G***; kibuzzard-6797D086
kibuzzard-6797D093: G***; kibuzzard-6797D093
kibuzzard-6797D096: G***; kibuzzard-6797D096
kibuzzard-6797D214: G***; kibuzzard-6797D214
kibuzzard-6797D229: G***; kibuzzard-6797D229
kibuzzard-6797D243: G***; kibuzzard-6797D243
kibuzzard-6797EDFE: G***; kibuzzard-6797EDFE
kibuzzard-6797F4C5: G***; kibuzzard-6797F4C5
kibuzzard-6797F4CD: G***; kibuzzard-6797F4CD

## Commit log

2025-02-06 Post design review changes
    [SparkFun_GNSS_LG580P.kicad_pcb, SparkFun_GNSS_LG580P.kicad_sch]
2025-02-06 Decrease paste on LG580P FP by 5%
    [SparkFun_GNSS_LG580P.kicad_pcb]
2025-03-05 Adjust values for assembly
    [SparkFun_GNSS_LG580P.kicad_pcb]
2025-04-01 Add panelized files
    [SparkFun_GNSS_LG580P.kicad_pcb, SparkFun_GNSS_LG580P.kicad_sch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]
2025-08-14 Update to KiCad v9
    [SparkFun_GNSS_LG580P.kicad_pcb, SparkFun_GNSS_LG580P.kicad_sch]
2025-09-12 Remove local FP and symbol
    [LG580P.step]
2025-09-22 Update footprint
    Updates file path and position of the footprint's 3D model
    [SparkFun_GNSS_LG580P.kicad_pcb]
2025-09-22 Add board files

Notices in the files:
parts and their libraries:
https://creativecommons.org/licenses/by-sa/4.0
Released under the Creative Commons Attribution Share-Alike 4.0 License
